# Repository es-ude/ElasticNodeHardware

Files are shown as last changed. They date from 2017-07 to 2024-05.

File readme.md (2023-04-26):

# Elastic Node Hardware Platform

## ENv5 - Elastic Node v5
The 5th generation of Elastic node is designed based on the 4th version, but with some improvements. The main improvements are:
- Using Cortex-M0 MCU instead of AVR 8-bit MCU, to gain more performance and lower power consumption.
- Using SPI as the communication interface between MCU and the FPGA to save more IO pins.
- Simplify the power supply circuit to reduce the space and improve reliability.
- Adding an energy meter chip to ease the energy measurement.
- Optimize the PCB layout to reduce the PCB size.

Before you start using the ENv5, please read the following documents accordingly:
- [ENv5 Test Version User Manual](v5/test_version/readme.md)
- [ENv5 Revision 1 User Manual](v5/revision_1/readme.md)

Troubleshooting
- When you notice the esp32 is not responding to the RP2040, you can apply the [pre-build firmware](v5/revision_1/prebuilds-firmware/test_esp_at.uf2) to test.
  - some descriptions about the behavior of the test are available [here](v5/revision_1/prebuilds-firmware/readme.md).

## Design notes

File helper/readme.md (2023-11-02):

Files that help me order PCBAs from JLCPCBs are stored in this folder.
1. the `ulp` file to generate BOM and CPL file.
2. the `cam_process` file to generate gerber files.

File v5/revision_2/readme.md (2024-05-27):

# ENv5 Revision 2 User Manual

## Notice:
- The old wifi-shield is not compatible with the ENv5-Rev1. Please use the new extension board instead.
  - When you plug out the extension board, please try to make to PCBs in parallel to avoid damage to the male headers.
- Before you plug in a battery to the ENv5, please check if the order of the battery is correct.
  - The Cable close to the dot sign should be positive.
  - A thermal resistor should be attached to the battery to prevent the battery from overheating. If the resistor is not soldered, don't use the battery.
- The pin mapping of Env5 is referred to the [schematic of env5-rev2](en_v5_rev2_schematic.pdf).
- The pin mapping of the extension board is referred to the [schematic of extension board](extension_board/extension_board_schematic.pdf).

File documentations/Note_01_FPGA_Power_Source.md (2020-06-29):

#Note_01_FPGA_Power_Source

| Supply | Circuits | FPGA pins |
| --- | --- | --- |
| 3.3V | FPGA I/O | VCCO_34 |
| 1.4V | FPGA I/O | VCCO_14 |
| 1.8V | FPGA Auxiliary | VCCAUX |
| 1.0V | FPGA Core and Block RAM | VCCINT and VCCBRAM |

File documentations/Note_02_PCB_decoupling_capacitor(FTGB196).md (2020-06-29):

#Note_02_PCB_decoupling_capacitor(FTGB196)

## 1.VCC_INT

| Device | 100uF | 4.7uF | 0.47uF |
| --- | ----- | ----- | --- |
| XC7S15 | 1 | 2 | 2 |
| XC7S25 | 1 | 2 | **3**  |
| XC7S50 | 1 | **3** | **5**  |

## 2.VCCBRAM

| Device | 100uF | 47uF | 4.7uF | 0.47uF |
| --- | ----- | ---- | ----- | --- |
| XC7S15 | 0 | 1 | 1 | 1 |
| XC7S25 | 0 | 1 | 1 | 1 |
| XC7S50 | **1** | 1 | 1 | 1 |

## 3.VCCAUX

| Device | 47uF | 4.7uF | 0.47uF |
| --- | ---- | ----- | --- |
| XC7S15 | 1 | 1 | 2 |
| XC7S25 | 1 | 1 | 2 |
| XC7S50 | 1 | 1 | **3**  |

##4.VCCO (**per Bank**)

| Device | 47uF or 100uF | 4.7uF | 0.47uF |
| --- | --- | ----- | --- |
| XC7S15 | 1 | 2 | 4 |
| XC7S25 | 1 | 2 | 4 |
| XC7S50 | 1 | 2 | 4 |

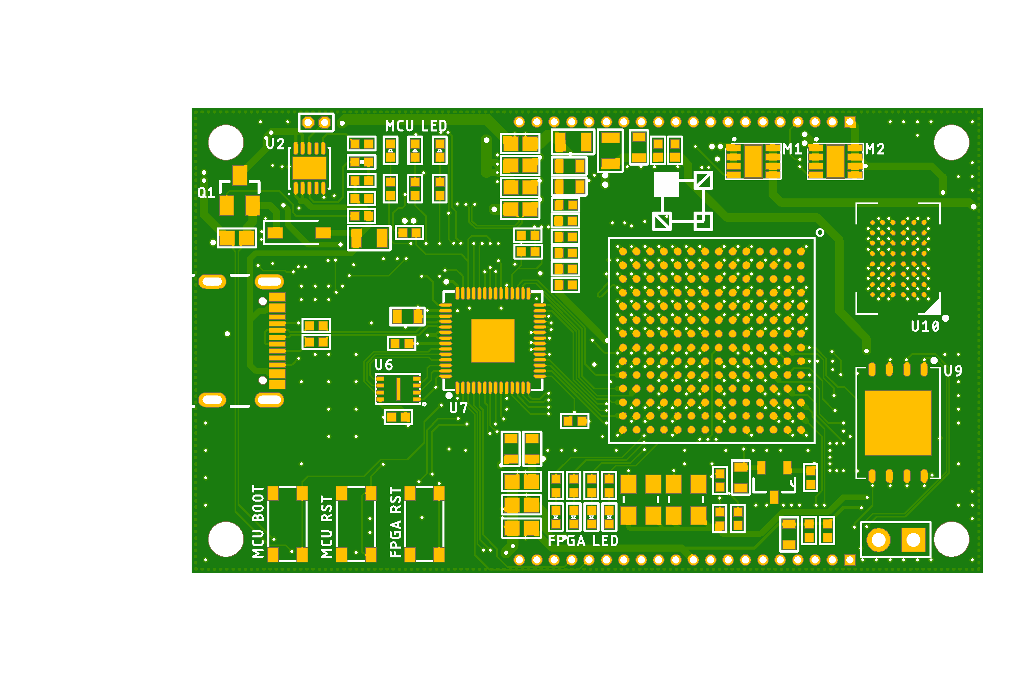
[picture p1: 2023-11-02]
v5/revision_2/main_board/en_v5_rev2_top.png

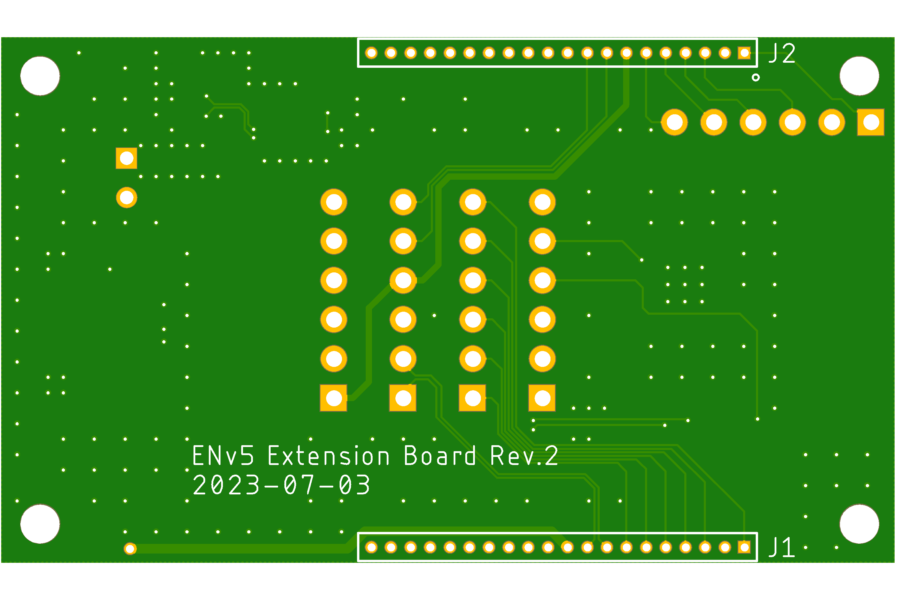
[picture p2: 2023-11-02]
v5/revision_2/extension_board/extension_board_bottom_rev2.png

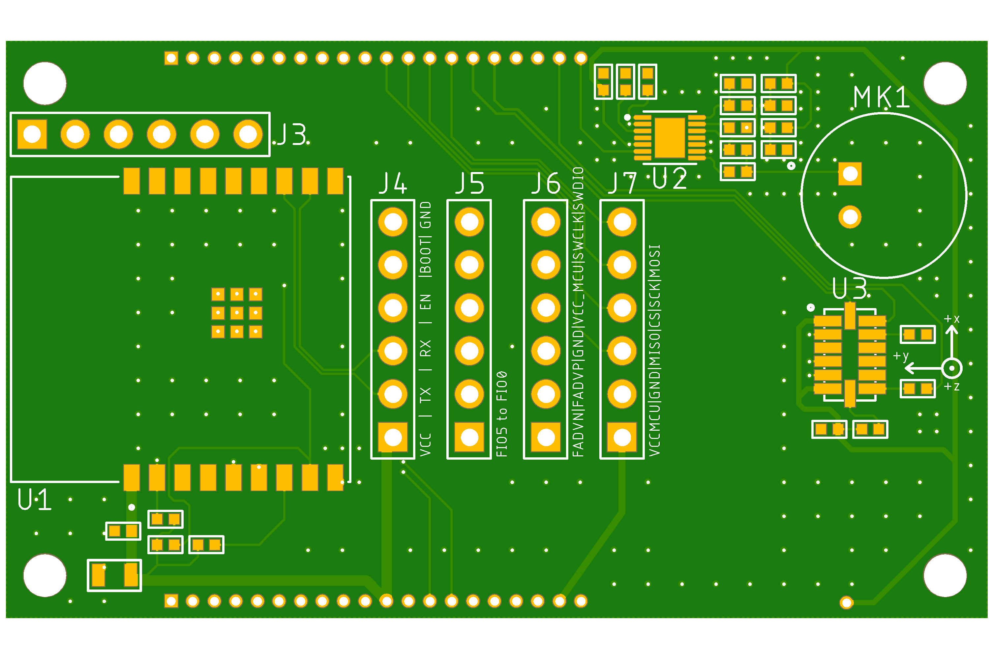
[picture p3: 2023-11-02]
v5/revision_2/extension_board/extension_board_top_rev2.png

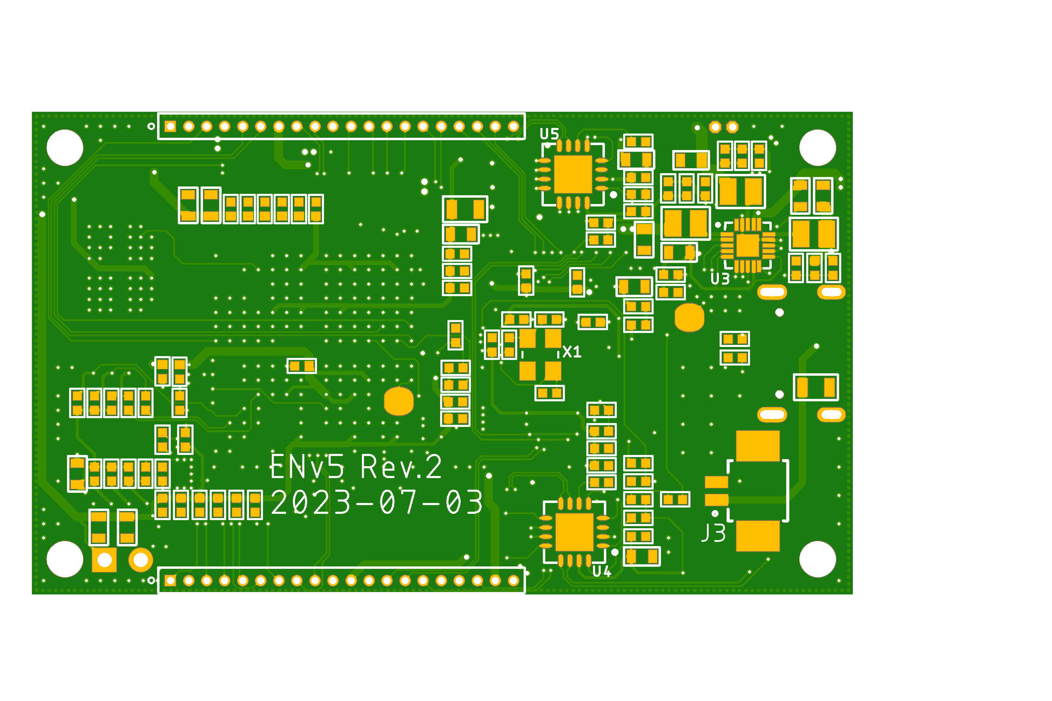
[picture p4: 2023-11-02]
v5/revision_2/main_board/en_v5_rev2_bottom.png

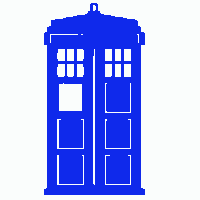
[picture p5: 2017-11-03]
logo/tardis.bmp

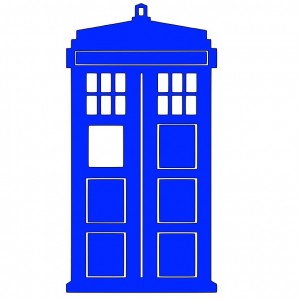
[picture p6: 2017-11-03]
logo/tardis.jpg

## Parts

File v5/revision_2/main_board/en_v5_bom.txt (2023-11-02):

Qty Value                   Device                     Package                   Parts                                                                     Description                                                                                                                           
14  0.1uF                   CAPACITOR0402              0402                      C3, C14, C16, C18, C19, C20, C21, C22, C23, C24, C26, C27, C30, C44                                                                                                                                             
2   0.1uF                   CAPACITOR0603              CAPC1608-0603             C5, C6                                                                                                                                                                                                          
1   0.1uF                   CAPACITOR0805              0805                      C1                                                                                                                                                                                                              
8   0.82R                   RESISTOR0603               0603                      R16, R17, R18, R19, R20, R21, R26, R28                                                                                                                                                                          
7   0R                      RESISTORSMD_0402           0402                      R4, R10, R27, R29, R47, R48, R49                                                                                                                                                                                
1   1.5uH(MLP2016H1R5MT0S1) INDUCTORDFE201612E-R33M=P2 INDC2016X120N             L1                                                                                                                                                                                                              
1   100MHz                  OSCILLATOR3.2X2.5          3.2X2.5_OSC               X3                                                                                                                                                                                                              
7   100R                    RESISTORSMD_0402           0402                      R33, R60, R61, R65, R66, R68, R70                                                                                                                                                                               
1   100uF                   CAPACITOR0805              0805                      C59                                                                                                                                                                                                             
7   10K                     RESISTORSMD_0402           0402                      R3, R22, R23, R24, R25, R34, R44                                                                                                                                                                                
5   10uF                    CAPACITOR0603              CAPC1608-0603             C4, C8, C10, C12, C42                                                                                                                                                                                           
1   10uF                    CAPACITOR0805              0805                      C2                                                                                                                                                                                                              
3   120K                    RESISTORSMD_0402           0402                      R9, R12, R13                                                                                                                                                                                                    
1   12MHz                   QUARTZ                     3.2X2.5_OSC               X1                                                                                                                                                                                                              
1   150K                    RESISTORSMD_0402           0402                      R11                                                                                                                                                                                                             
1   180K                    RESISTORSMD_0402           0402                      R14                                                                                                                                                                                                             
7   1K                      RESISTORSMD_0402           0402                      R6, R46, R51, R52, R54, R55, R62                                                                                                                                                                                
1   1R                      RESISTORSMD_0402           0402                      R41                                                                                                                                                                                                             
2   1uF                     CAPACITOR0402              0402                      C33, C43                                                                                                                                                                                                        
1   2.2uH(MLP2016H2R2MT0S1) INDUCTORDFE201612E-R33M=P2 INDC2016X120N             L3                                                                                                                                                                                                              
1   2.7pF                   CAPACITOR0402              0402                      C11                                                                                                                                                                                                             
1   200R                    RESISTORSMD_0402           0402                      R37                                                                                                                                                                                                             
2   20pF                    CAPACITOR0402              0402                      C31, C32                                                                                                                                                                                                        
2   27R                     RESISTORSMD_0402           0402                      R42, R43                                                                                                                                                                                                        
7   2K                      RESISTORSMD_0402           0402                      R5, R45, R50, R53, R56, R57, R58                                                                                                                                                                                
1   3.3pF                   CAPACITOR0402              0402                      C9                                                                                                                                                                                                              
1   3.3uH(MLP2016H3R3MT0S1) INDUCTORDFE201612E-R33M=P2 INDC2016X120N             L2                                                                                                                                                                                                              
1   30K                     RESISTORSMD_0402           0402                      R8                                                                                                                                                                                                              
1   32MHz                   OSCILLATOR3.2X2.5          3.2X2.5_OSC               X2                                                                                                                                                                                                              
3   4.7K                    RESISTORSMD_0402           0402                      R32, R35, R59                                                                                                                                                                                                   
15  4.7uF                   CAPACITOR0603              CAPC1608-0603             C13, C15, C17, C25, C28, C29, C34, C35, C45, C46, C54, C60, C61, C68, C70                                                                                                                                       
15  470nF                   CAPACITOR0402              0402                      C36, C37, C38, C39, C47, C48, C49, C50, C55, C56, C62, C63, C64, C71, C74                                                                                                                                       
12  47nF                    CAPACITOR0402              0402                      C40, C41, C51, C52, C57, C58, C65, C66, C67, C72, C73, C75                                                                                                                                                      
2   47uF                    CAPACITOR0805              0805                      C53, C69                                                                                                                                                                                                        
9   499R                    RESISTORSMD_0402           0402                      R30, R36, R38, R39, R40, R63, R64, R67, R69                                                                                                                                                                     
1   53261-0271              53261-0271                 MOLEX_53261-0271          J3                                                                        Conn Shrouded Header HDR 2 POS 1.25mm Solder RA SMD PicoBlade™ Embossed T/R Check availability                                        
1   57.6K                   RESISTORSMD_0402           0402                      R15                                                                                                                                                                                                             
2   5K                      RESISTORSMD_0402           0402                      R1, R2                                                                                                                                                                                                          
1   6.8pF                   CAPACITOR0402              0402                      C7                                                                                                                                                                                                              
1   806R                    RESISTORSMD_0402           0402                      R31                                                                                                                                                                                                             
1   CY7C1051DV33            CY7C1051DV33               BGA-48                    U10                                                                       SRAM 8Mb 10ns3.3V 512Kx16 Fast Async                                                                                                  
1   DIODEB5817W             SCHOTTKY_DIODEB5817W       SOD-123                   D1                                                                                                                                                                                                              
1   FDN302P                 FDN302P                    SSOT-3                    Q1                                                                        P-Channel MOSFET                                                                                                                      
1   FEMALE_HEADER_2X1       FEMALE_HEADER_2X1          2X1_HEADER                J5                                                                                                                                                                                                              
1   LTC3569EUDPBF           LTC3569EUDPBF              QFN40P300X300X80-21N      U3                                                                        Triple Buck Regulator with 1.2A and Two 600mA Outputs and  Individual Programmable References Check availability                      
2   M50-3032042             M50-3032042                20X1_HEADER_THT_1.27MM    J1, J2                                                                    M50-3032042                                                                                      
1   MCP73833T-AMI/MF        MCP73833T-AMI/MF           DFN-10(3X3X0.9)           U2                                                                        Linear Charge Management Controller Li-Ion/Li-Pol 1mA 4.2V/4.35V/4.4V/4.5V 10-Pin DFN EP T/R Check prices                             
1   NTCLE413E2103H400       RESISTORTHT_THERMAL        THT_2                     R7                                                                                                                                                                                                              
2   PAC1934                 PAC1934                    UQFN-16(4×4×0.5MM)        U4, U5                                                                    Current & Power Monitors & Regulators Quad High-Side Current Sensor, I2C/SMBus, 32V with Accumulator                                  
1   REF3012AIDBZR           REF3012AIDBZR              SOT-23(3PIN)              U1                                                                        CMOS VOLTAGE REFERENCE Check prices                                                                                                   
1   RP2040                  RP2040                     QFN40P700X700X100-57T310N U7                                                                                                                                                                                                              
1   S25FL256S               S25FL256S                  WSON6X8MM                 U9                                                                        FLASH - NOR Memory IC 256Mb (32M x 8) SPI - Quad I/O WSON-8 (6x8)                                                                     
2   SISS23DN                SISS23DN                   POWERPAK1212-8            M1, M2                                                                                                                                                                                                          
1   SPARTAN7-LX15           SPARTAN7-LX15              FTGB196                   U8                                                                                                                                                                                                              
3   TACTILE-SWITCH          TACTILE-SWITCH             TACTILE-SWITCH            S1, S2, S3                                                                612-TL3365AF180QG                                                                                                                     
2   TEST_POINTSMD           TEST_POINTSMD              SMD_PAD                   TP1, TP2                                                                                                                                                                                                        
1   USB4105-GF-A            USB4105-GF-A               GCT_USB4105-GF-A          J4                                                                        USB-C (USB TYPE-C) USB 2.0 Receptacle Connector 24 (16+8 Dummy) Position Surface Mount, Right Angle; Through Hole  Check availability 
1   W25Q16JVUXIQ            W25Q16JVUXIQ               USON8-2X3MM               U6                                                                        W25Q16JV - NOR Flash                                                                                                                  
1   green                   LED0402                    0402                      D2                                                                                                                                                                                                              
7   red                     LED0402                    0402                      D3, D4, D5, D6, D7, D8, D9

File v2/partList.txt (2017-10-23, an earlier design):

	Partlist

Exported from elasticNode.brd at 07.08.17 2:13 PM

EAGLE Version 8.2.2 Copyright (c) 1988-2017 Autodesk, Inc.

Assembly variant: 

Part     Value               Package         Library    Position (mm)         Orientation

C1       4.7uF               0805            passive    (9.5 28.25)           R270
C2       4.7uF               0805            passive    (17.36 11.25)         R0
C3       4.7uF               0805            passive    (19.5 42.25)          R0
C4       4.7uF               0805            passive    (23.25 11)            R180
C5       4.7uF               0805            passive    (7.25 28.25)          R270
C6       4.7uF               0805            passive    (17.36 13.46)         R0
C7       .47uF               0402            passive    (19.5 44.5)           R0
C8       .47uF               0402            passive    (21.25 11.5)          R90
C9       4.7uF               0805            passive    (5 28.25)             R270
C10      4.7uF               0805            passive    (27.75 48)            R0
C11      .47uF               0402            passive    (19.5 46.75)          R0
C12      .47uF               0402            passive    (20.5 8.75)           R180
C13      0.47uF              0402            passive    (2.75 28.25)          R270
C14      4.7uF               0805            passive    (27.75 45.75)         R0
C15      4.7uF               0805            passive    (43.25 27.5)          R90
C16      4.7uF               0805            passive    (7.25 25)             R270
C17      4.7uF               0805            passive    (27.75 43.5)          R0
C18      .47uF               0402            passive    (41 27.5)             R90
C19      .47uF               0402            passive    (5 25)                R270
C20      4.7uF               0805            passive    (27.75 41.25)         R0
C21      .47uF               0402            passive    (38.75 27.5)          R90
C22      .47uF               0402            passive    (2.75 25)             R270
C23      4.7uF               0805            passive    (43.25 24.75)         R270
C24      .47uF               0805            passive    (41 24.75)            R270
C25      10n                 0805            passive    (78.75 21)            R180
C26      100n                0805            passive    (78.75 25.5)          R180
C27      4.7u                0805            passive    (78.75 27.75)         R180
C28      100n                0805            passive    (74.35 15.05)         R90
C29      22u                 0805            passive    (63.5 35.5)           R0
C30      10u                 0805            passive    (67.8 26.3)           R180
C31      22u                 0805            passive    (70.25 35.5)          R180
J1       ISP_CONN_6PIN       3X2_HEADER_SMT  connectors (57.5 17)             R90
J2       FEMALE_HEADER_2X2   2X2_HEADER      connectors (64.25 48.5)          R180
J3       FEMALE_HEADER_2X1   2X1_HEADER      connectors (16.25 49.75)         R180
J4       FEMALE_HEADER_2X1   2X1_HEADER      connectors (23 49.75)            R180
J5       FEMALE_HEADER_5X2   5X2_HEADER      connectors (4.5 36.75)           R270
J6       FEMALE_HEADER_5X2   5X2_HEADER      connectors (4.5 16.9)            R90
J7       JTAG_CONN_6PINTHT   6X1_HEADER      connectors (38.5 44.25)          R270
J8       USB_CONNSMT         USB_MICRO_B_SMT connectors (77 13.5)             R90
L1       40Ohm 1.5A          0805            passive    (78.75 23.25)         R180
L2       3.3uH               0805            passive    (62.25 29.75)         R270
L3       3.3uH               0805            passive    (71.25 29.75)         R90
LED0     GREEN 2.2V          0805            opto       (68 45.25)            R90
LED1     GREEN 2.2V          0805            opto       (70.25 45.25)         R90
LED2     GREEN 2.2V          0805            opto       (72.5 45.25)          R90
LED3     GREEN 2.2V          0805            opto       (74.75 45.25)         R90
LED4     RED 1.8V 2mA        0805            opto       (10 45)               R90
LED5     RED                 0805            opto       (12.25 45)            R90
LED6     RED                 0805            opto       (14.5 45)             R90
LED7     RED                 0805            opto       (16.75 45)            R90
PWR      RED                 0805            opto       (70.25 4.5)           R90
R1       2.4k                0805            passive    (54.6 35)             R135
R2       2.4k                0805            passive    (53.5 19.75)          MR315
R3       550                 0805            passive    (68 42.25)            R90
R4       550                 0805            passive    (70.25 42.25)         R90
R5       550                 0805            passive    (72.5 42.25)          R90
R6       550                 0805            passive    (74.75 42.25)         R90
R7       15k                 0805            passive    (52 18.75)            R90
R8       750                 0805            passive    (10 42.25)            R90
R9       750                 0805            passive    (12.25 42.25)         R90
R10      750                 0805            passive    (14.5 42.25)          R90
R11      750                 0805            passive    (16.75 42.25)         R90
R12      2.4k                0805            passive    (34.25 16.5)          R270
R13      2.4k                0805            passive    (36.5 16.5)           R270
R14      2.4k                0805            passive    (17.5 8.75)           R270
R15      15k                 0805            passive    (15.25 9.5)           R0
R16      0.8                 0805            passive    (73.75 36.5)          R270
R17      .8                  0805            passive    (30.5 48.75)          R0
R18      0.16                0805            passive    (78.75 30)            R180
R19      .8                  0805            passive    (30.5 51)             R0
R20      100                 0805            passive    (73.5 33.5)           R270
R21      300                 0805            passive    (30.75 42.25)         R0
R22      .8                  0805            passive    (47.5 18.75)          R270
R23      2000                0805            passive    (44.5 22)             R180
R24      1.5k                0805            passive    (48.5 10.5)           MR180
R25      1.5k                0805            passive    (54 14)               MR180
R26      1.5k                0805            passive    (65.75 8)             R270
R27      1.5k                0805            passive    (68 8)                R270
R28      6k8                 0805            passive    (63.25 33.1)          R0
R29      1k5                 0805            passive    (65.5 31.6)           R0
R30      1k5                 0805            passive    (67.5 33.1)           R0
R31      1k5                 0805            passive    (70.25 33.1)          R0
R32      270                 0805            passive    (70.25 8)             R270
RX       ORANGE              0805            opto       (68 4.5)              R90
S1       SPST_BUTTON2PIN_SMT SPST_2PIN_SMT   connectors (57.5 9.25)           R180
S2       SPST_BUTTON2PIN_SMT SPST_2PIN_SMT   connectors (21.75 4.5)           R180
S3       SPST_DIP_2SMT       SPST_DIP2_SMT   connectors (37.5 9.75)           R0
TX       ORANGE 2V           0805            opto       (65.75 4.5)           R90
U1       ATMEGA64AQFN        QFN64           ic         (47.06 26.59)         MR0
U2       SST26VF032B         SOIC8           ic         (57.78 22.15)         MR90
U3       MRF24J40MA          MRF24J40MA      wireless   (50.75 44.5)          R0
U4       SPARTAN6-LX9        TQG144          fpga       (23.56 28.48)         R0
U5       SST26VF032B         SOIC8           ic         (29.63 11.41)         R180
U6       PAC1720             VDFN10          sensors    (77 33.5)             R270
U7       PAC1720             VDFN10          sensors    (32.5 45.5)           R270
U8       PAC1720             VDFN10          sensors    (40.75 18)            R180
U9       FT232RSSOP28        SSOP28          ic         (68 16.75)            R270
U10      LTC3419DFN          DFN8            power      (66.5 29.25)          R270
X1       12MHz               3.2X2.5_OSC     passive    (49.25 14)            MR0
X2       50MHz               3.2X2.5_OSC     passive    (22.75 15)            R180
X3       32MHz               3.2X2.5_OSC     passive    (40.25 32.75)         R270

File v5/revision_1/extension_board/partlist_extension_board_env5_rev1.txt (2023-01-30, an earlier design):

Partlist exported from /home/chao/EAGLE/projects/lattice_v5/extension_board/extension_board.sch at 16/01/2023 20:29

Qty Value                  Device                 Package                     Parts               Description                                                                                                AVAILABILITY CUI_PURCHASE_URL                                                                                                                                                    DESCRIPTION                                                                MANUFACTURER MAXIMUM_PACKAGE_HEIGHT MF                  MP             PACKAGE               PARTREV PRICE PURCHASE-URL                                                    STANDARD                    
3   0.1uF                  CAPACITOR0402          0402                        C3, C5, C6                                                                                                                                                                                                                                                                                                                                                                                                                                                                                                                                                                                        
1   0.1uF                  CAPACITOR0805          0805                        C1                                                                                                                                                                                                                                                                                                                                                                                                                                                                                                                                                                                                
1   0R                     RESISTORSMD_0402       0402                        R13                                                                                                                                                                                                                                                                                                                                                                                                                                                                                                                                                                                               
5   100K                   RESISTORSMD_0402       0402                        R4, R5, R6, R7, R10                                                                                                                                                                                                                                                                                                                                                                                                                                                                                                                                                                               
3   10K                    RESISTORSMD_0402       0402                        R1, R2, R3                                                                                                                                                                                                                                                                                                                                                                                                                                                                                                                                                                                        
1   10uF                   CAPACITOR0805          0805                        C2                                                                                                                                                                                                                                                                                                                                                                                                                                                                                                                                                                                                
1   150K                   RESISTORSMD_0402       0402                        R9                                                                                                                                                                                                                                                                                                                                                                                                                                                                                                                                                                                                
2   1uF                    CAPACITOR0402          0402                        C4, C8                                                                                                                                                                                                                                                                                                                                                                                                                                                                                                                                                                                            
1   2.2K                   RESISTORSMD_0402       0402                        R8                                                                                                                                                                                                                                                                                                                                                                                                                                                                                                                                                                                                
1   2.2uF                  CAPACITOR0402          0402                        C7                                                                                                                                                                                                                                                                                                                                                                                                                                                                                                                                                                                                
2   2K                     RESISTORSMD_0402       0402                        R11, R12                                                                                                                                                                                                                                                                                                                                                                                                                                                                                                                                                                                          
1   ADXL345BCCZ-RL         ADXL345BCCZ-RL         PQFN80P300X500X79-14N       U3                  3-Axis, ±2 g/±4 g/±8 g/±16 g Digital Accelerometer Check prices                                            In Stock                                                                                                                                                                          Accelerometer X, Y, Z Axis ±2g, 4g, 8g, 16g 0.05Hz ~ 1.6kHz 14-LGA (3x5)                                      Analog Devices Inc. ADXL345BCCZ-RL LGA-14 Analog Devices         None  https://pricing.snapeda.com/search/part/ADXL345BCCZ-RL/?ref=eda                             
1   CMA-4544PF-W           CMA-4544PF-W           MIC_CMA-4544PF-W            MK1                 CMA Series 9.7 mm Electret Condenser Omni-Directional Pin Mount 3 V Microphone Check prices                In Stock     https://www.cuidevices.com/product/audio/microphones/electret-condenser-microphones/cma-4544pf-w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 9.7 mm, Omnidirectional, PCB Mount, 3.0 Vdc, Electret Condenser Microphone                                     CUI Devices         CMA-4544PF-W   6-DIP-6 CUI                   None  https://pricing.snapeda.com/search/part/CMA-4544PF-W/?ref=eda                               
1   ESP32-C3-WROOM-02-H4   ESP32-C3-WROOM-02-H4   MODULE_ESP32-C3-WROOM-02-H4 U1                  WiFi Modules (802.11) (Engineering Samples) SMD module, ESP32-C3, 4MB SPI flash, PCB antenna, -40 C +105 C                                                                                                                                                                                                                                                             Espressif    3.35 mm                                                                         V1.0                                                                          Manufacturer Recommendations
2   M50-3142045THT         M50-3142045THT         20X1_HEADER_THT_1.27MM      J1, J2              Headers & Wire Housings 20 WAY SIL VERT SMT SKT                                                                                                                                                                                                                                                                                                                                                                                                                                                                                                                               
5   MALE_HEADER_6X1_2.54MM MALE_HEADER_6X1_2.54MM HDR_6X1_2.54MM              J3, J4, J5, J6, J7                                                                                                                                                                                                                                                                                                                                                                                                                                                                                                                                                                                
1   MAX9814ETD+T           MAX9814ETD+T           SON40P300X300X80-15N        U2                  Audio Amp Microphone 1-CH Mono Class-AB 14-Pin TDFN EP T/R Check prices                                    In Stock                                                                                                                                                                          Amplifier IC 1-Channel (Mono) Class AB 14-TDFN-EP (3x3)                                                       Maxim Integrated    MAX9814ETD+    TDFN-14 Maxim                 None

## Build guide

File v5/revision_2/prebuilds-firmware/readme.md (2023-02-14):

This folder hosts prebuild firmware for hardware test or example purposes. 
The current prebuild are:
- `factory_MINI-1.bin` for the EPS32-C3 module on the extension board with enabled logs.
- `factory_MINI-1-Silence-Mode.bin` is the same as above but enables silence mode.

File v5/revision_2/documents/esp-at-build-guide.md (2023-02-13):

# ESP AT Firmware Build and debug guide
> you can find my prebuild firmware [here](https://github.com/es-ude/ElasticNodeHardware/tree/master/v5/revision_1/prebuilds-firmware).
## Commands example
```
git clone git@github.com:espressif/esp-at.git
cd esp-at
git checkout release/v3.0.0.0
# install your building system
./build.py install
# build the firmware, choose 2 -> 1 -> 0
./build.py build
# to flash the firmware
./build.py flash -p /dev/ttyUSB0
# alternative command to flash the firmware
./build.py flash -p /dev/ttyUSB0 build/factory/factory_MINI-1.bin

# to monitor debug output
./build.py monitor -p /dev/ttyUSB0
```
You will see output like this:

```
--- idf_monitor on /dev/ttyUSB0 115200 ---
--- Quit: Ctrl+] | Menu: Ctrl+T | Help: Ctrl+T followed by Ctrl+H ---
ESP-ROM:esp32c3-api1-20210207
Build:Feb  7 2021
rst:0x1 (POWERON),boot:0xc (SPI_FAST_FLASH_BOOT)
SPIWP:0xee
mode:DIO, clock div:2
load:0x3fcd6100,len:0x18cc
load:0x403ce000,len:0x8dc
load:0x403d0000,len:0x2d90
entry 0x403ce000
I (31) boot: ESP-IDF v4.3.2-553-g588436db47 2nd stage bootloader
I (31) boot: compile time 22:25:17
I (32) boot: chip revision: 3
I (35) boot.esp32c3: SPI Speed      : 40MHz
I (39) boot.esp32c3: SPI Mode       : DIO
I (44) boot.esp32c3: SPI Flash Size : 4MB
I (49) boot: Enabling RNG early entropy source...
I (54) boot: Partition Table:
I (58) boot: ## Label            Usage          Type ST Offset   Length
I (65) boot:  0 otadata          OTA data         01 00 0000d000 00002000
I (72) boot:  1 phy_init         RF data          01 01 0000f000 00001000
I (80) boot:  2 nvs              WiFi data        01 02 00010000 0000e000
I (87) boot:  3 at_customize     unknown          40 00 0001e000 00042000
I (95) boot:  4 ota_0            OTA app          00 10 00060000 001d0000
I (102) boot:  5 ota_1            OTA app          00 11 00230000 001d0000
I (110) boot: End of partition table
I (114) esp_image: segment 0: paddr=00060020 vaddr=3c140020 size=2a990h (174480) map
I (161) esp_image: segment 1: paddr=0008a9b8 vaddr=3fc91200 size=03c04h ( 15364) load
I (165) esp_image: segment 2: paddr=0008e5c4 vaddr=40380000 size=01a54h (  6740) load
I (168) esp_image: segment 3: paddr=00090020 vaddr=42000020 size=134c40h (1264704) map
I (452) esp_image: segment 4: paddr=001c4c68 vaddr=40381a54 size=0f6d0h ( 63184) load
I (467) esp_image: segment 5: paddr=001d4340 vaddr=50000000 size=00014h (    20) load
I (468) esp_image: segment 6: paddr=001d435c vaddr=50000018 size=00010h (    16) load
I (479) boot: Loaded app from partition at offset 0x60000
I (479) boot: Disabling RNG early entropy source...
AT cmd port:uart1 tx:7 rx:6 cts:5 rts:4 baudrate:115200
module_name:MINI-1
max tx power=78,ret=0
2.5.0

```

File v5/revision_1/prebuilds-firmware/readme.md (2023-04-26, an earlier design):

This folder hosts prebuild firmware for hardware test or example purposes. 
The current prebuild are:
- `factory_MINI-1.bin` for the EPS32-C3 module on the extension board with enabled logs.
- `factory_MINI-1-Silence-Mode.bin` is the same as above but enables silence mode.
- `test_esp_at.uf2` is the file for quick check if the esp32 is well connected to ENv5.
  - after you flash it to the RP2040, connect it via `screen` or `putty`, and send the 't' to the board, and it starts the test.
  - It automatically connects to `ES-Stud`, and start ping an IP address, as long as you see it comes to the ping test stage, which means the connection between boards is fine.

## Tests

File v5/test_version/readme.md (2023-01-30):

# ENv5 Test Version User Manual

## Known Issues of the Test Version
> Since this is the primary version of the ENv5, there are some known issues that need to be fixed in the next revision. Please read the following list carefully to save your time for debugging.
- The silk print for buttons `BOOT` and `MCU_RST` is reversed.
- The Flash chip is powered with the same rail as FPGA IOs, which means when you turn off the FPGA the Flash chip will be turned off as well.
  - You cannot write bitfile to the flash chip when the FPGA is turned off.
  - When the bitfile on flash chip is corrupted, once the FPGA is powered on, the FPGA will keeps reading data from the Flash chip. This leads to the MCU cannot visit the Flash anymore.
- Resistor value of the FPGAs mode selection pins are with wrong value, correct value is 1K.

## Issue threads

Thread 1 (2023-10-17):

ENv5 Revision 1 new boards with new MCU does not work with USB 3.0

telefonjoker100, 2023-10-17:
The new boards do not work with USB-C to USB-C Cable. We assume it are the new MCUs that do not force the pc to downgrade to USB2.0

SuperChange001, 2023-11-02:
Closed because we located the error is caused by the wrong resistor soldered by the manufacturer.

Closed 2023-11-02.

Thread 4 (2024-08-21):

LTC3569 - Datasheet states that power rail voltage drops when switching the enable pin of the LTC3569 respective power rail

LeoBuron, 2024-08-21:
The Output is computed with

VOUT1 = VREF1(1 + R1/R2) with R1=30k and R2=120k => VOUT1 = 1.0V
VOUT2 = VREF2(1 + R3/R4) with R3=150k and R4=120k => VOUT2 = 1.8V

VREF starts at 0.8V and will decrease everytime it the respective enable pin is switched by 25mV down to 0.425V.
This means that everytime we switch the FPGA power on and off, the VREF1 and VREF2 will go down by 25mV. Which will result in drops of 31.25mV for VOUT1 and 56.25mV for VOUT2. We should definitly check if the behaviour is like that. This would mean that we can not really turn off and on the FPGA multiple times.

LeoBuron, 2024-09-19:
Sure. But if we enable and disbale the ltc3569 fast, we generate a square wave. So the problem might still occur.

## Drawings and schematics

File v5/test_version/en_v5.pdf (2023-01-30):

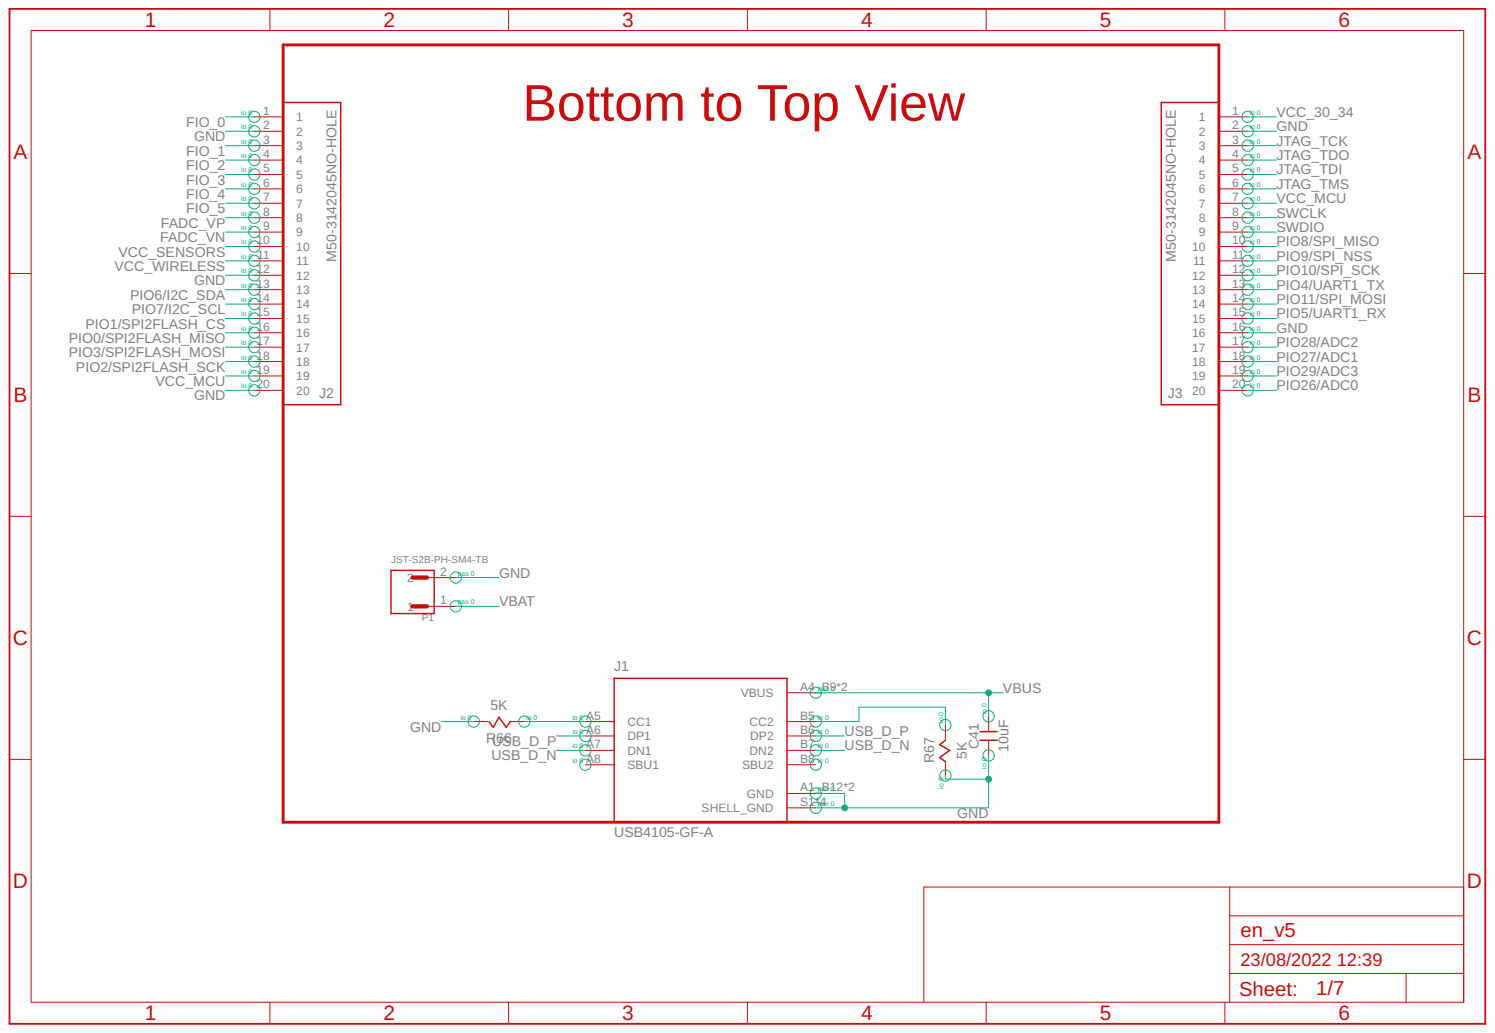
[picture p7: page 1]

Bottom to Top View

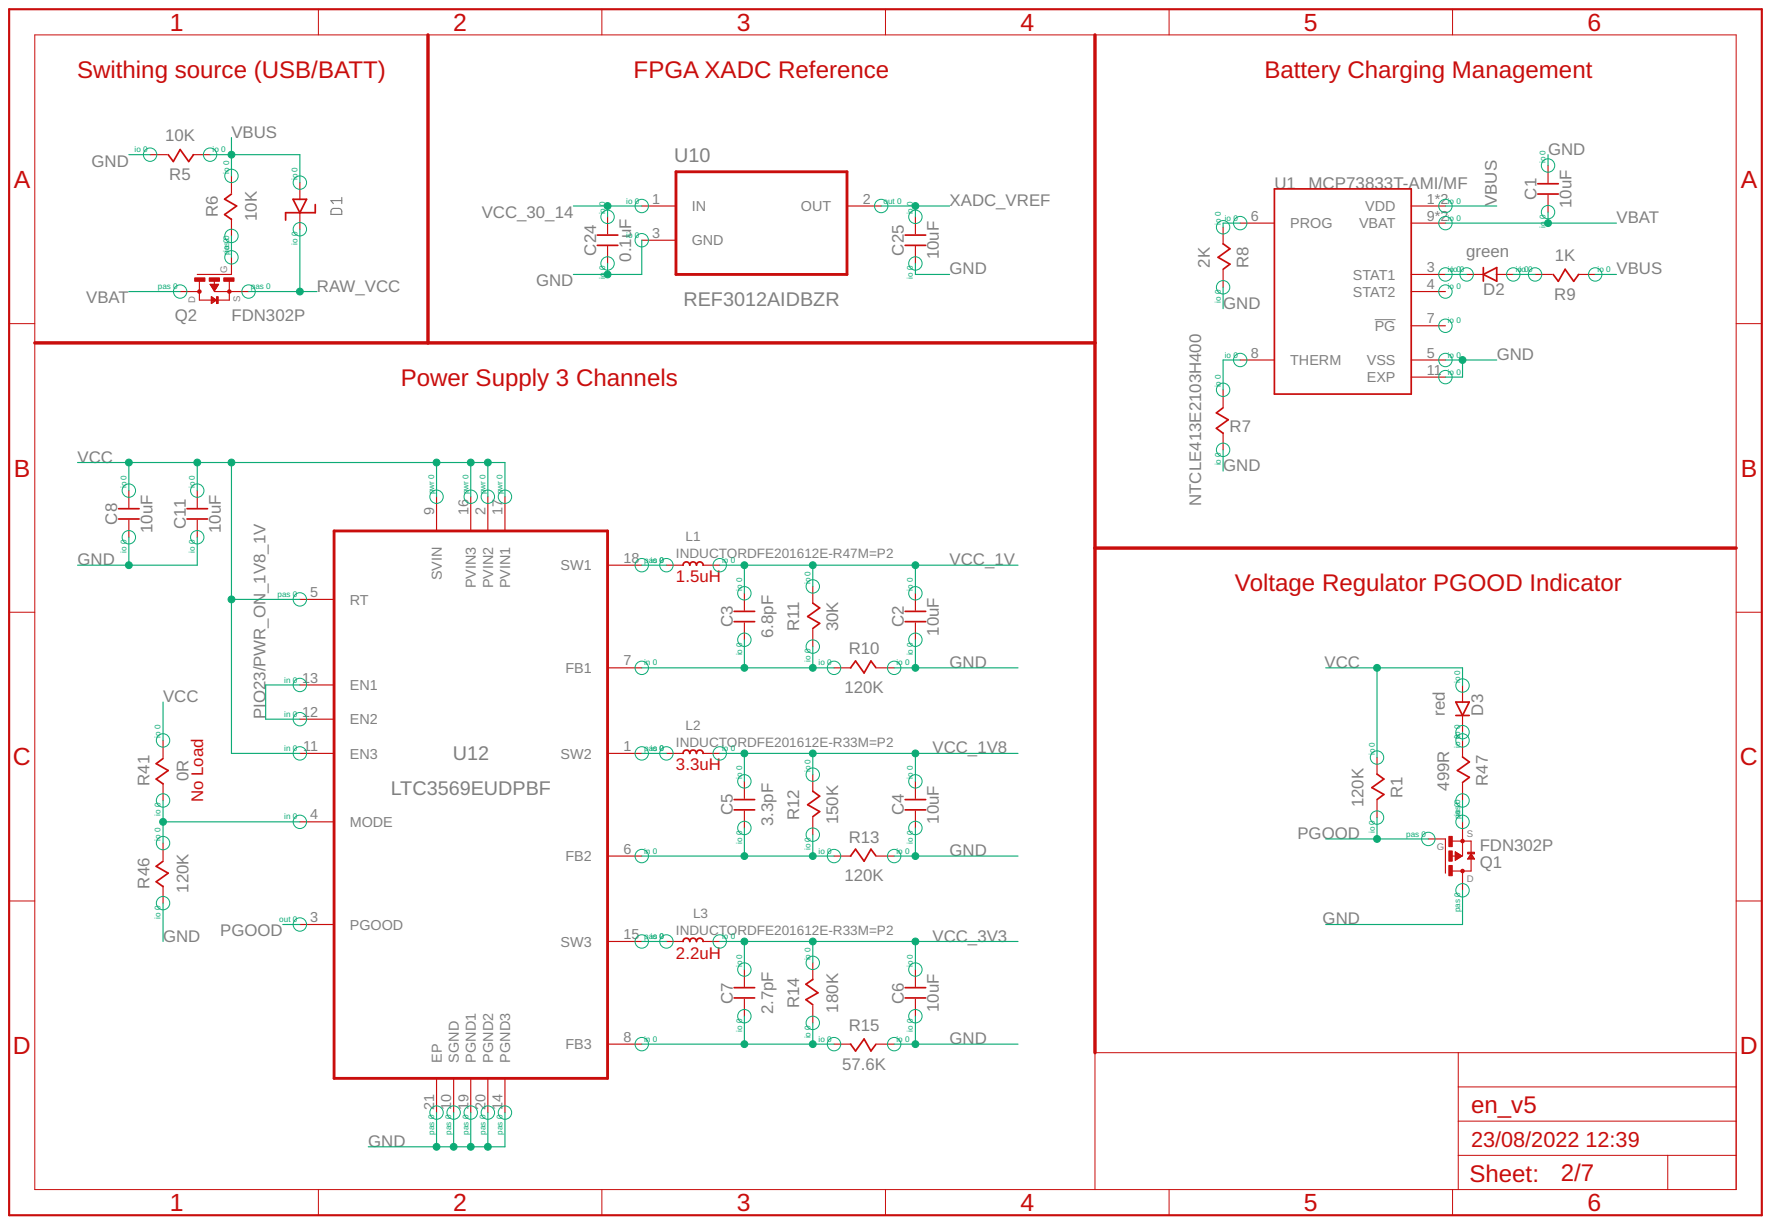
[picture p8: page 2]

Swithing source (USB/BATT) VBUS VBAT | FPGA XADC Reference GND | Battery Charging Management

No Load Power Supply 3 Channels

Voltage Regulator PGOOD Indicator

L2 1 pas 0 io 0 io 0

L3 15 pas 0 io 0 io 0

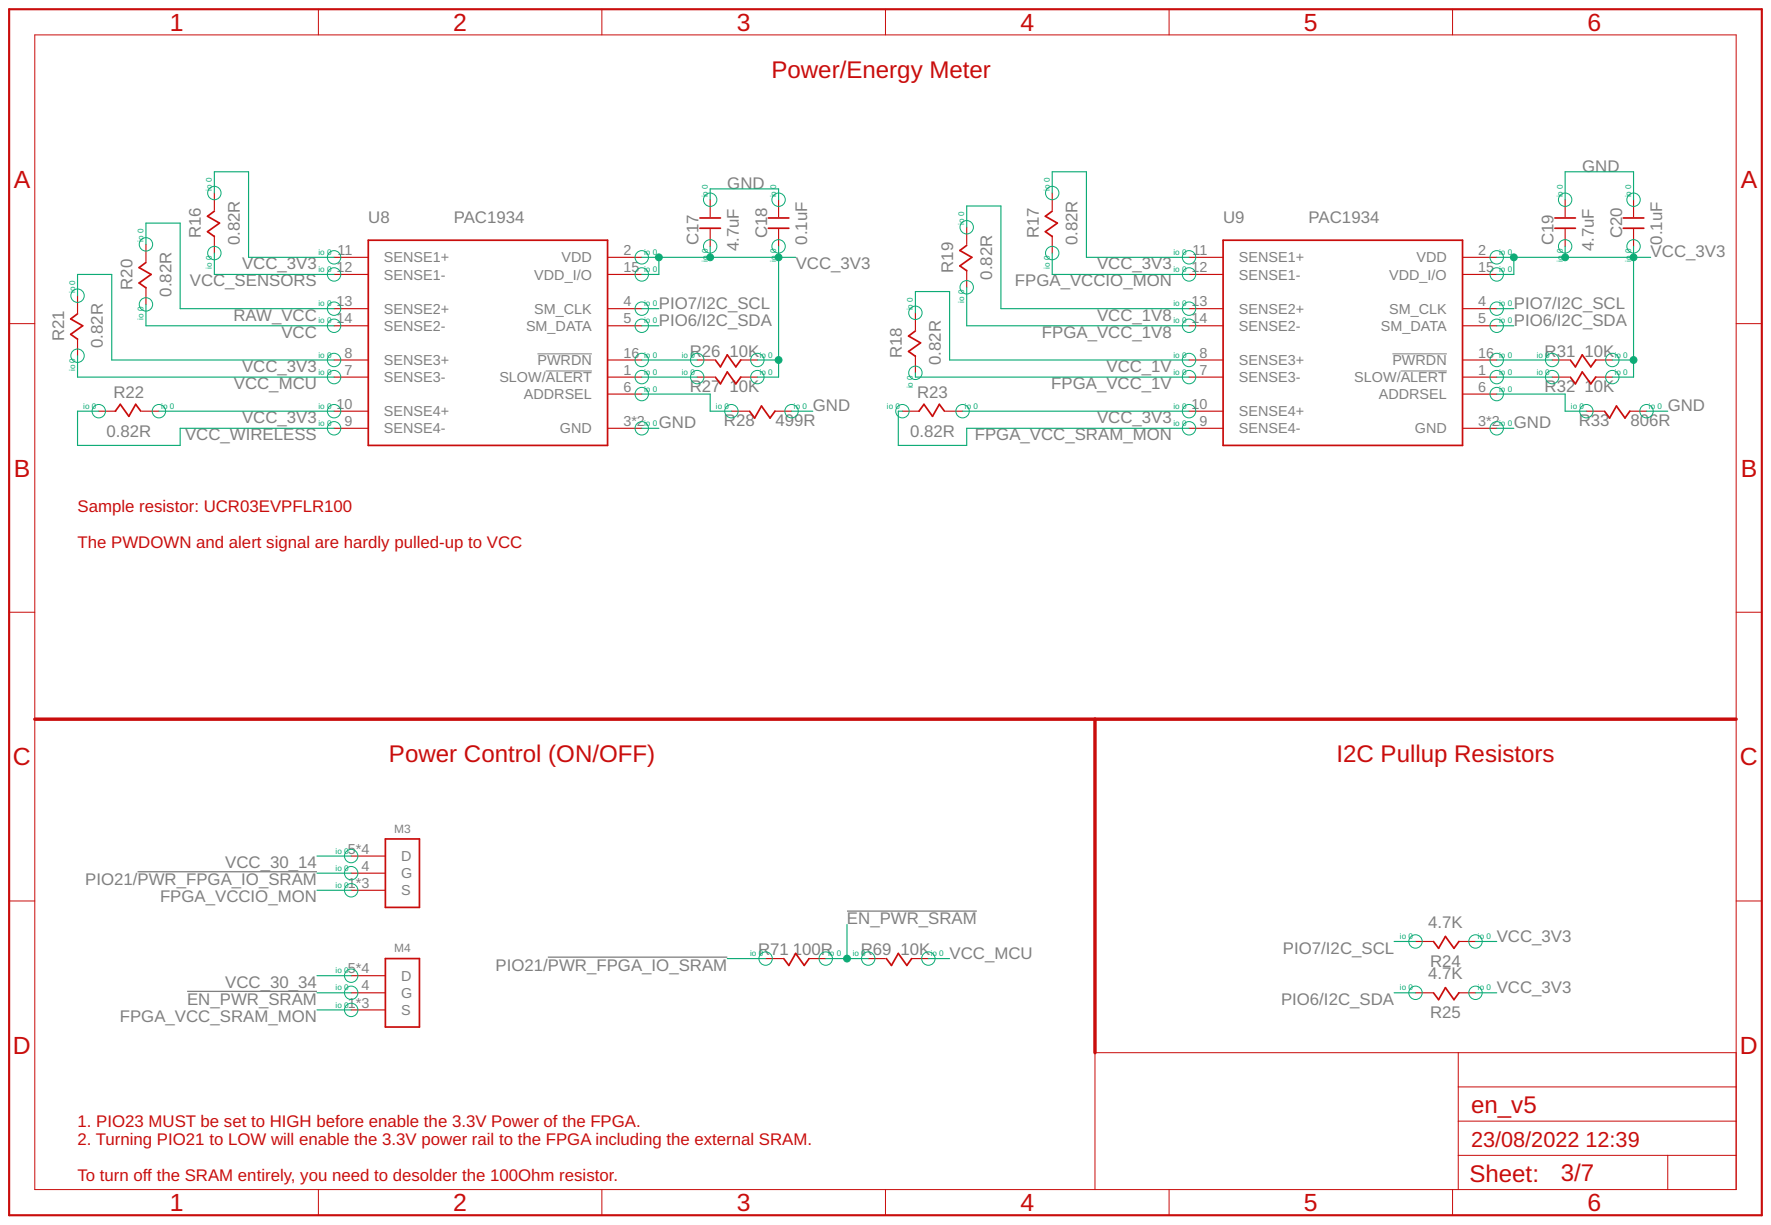
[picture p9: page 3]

Sample resistor: UCR03EVPFLR100
The PWDOWN and alert signal are hardly pulled-up to VCC

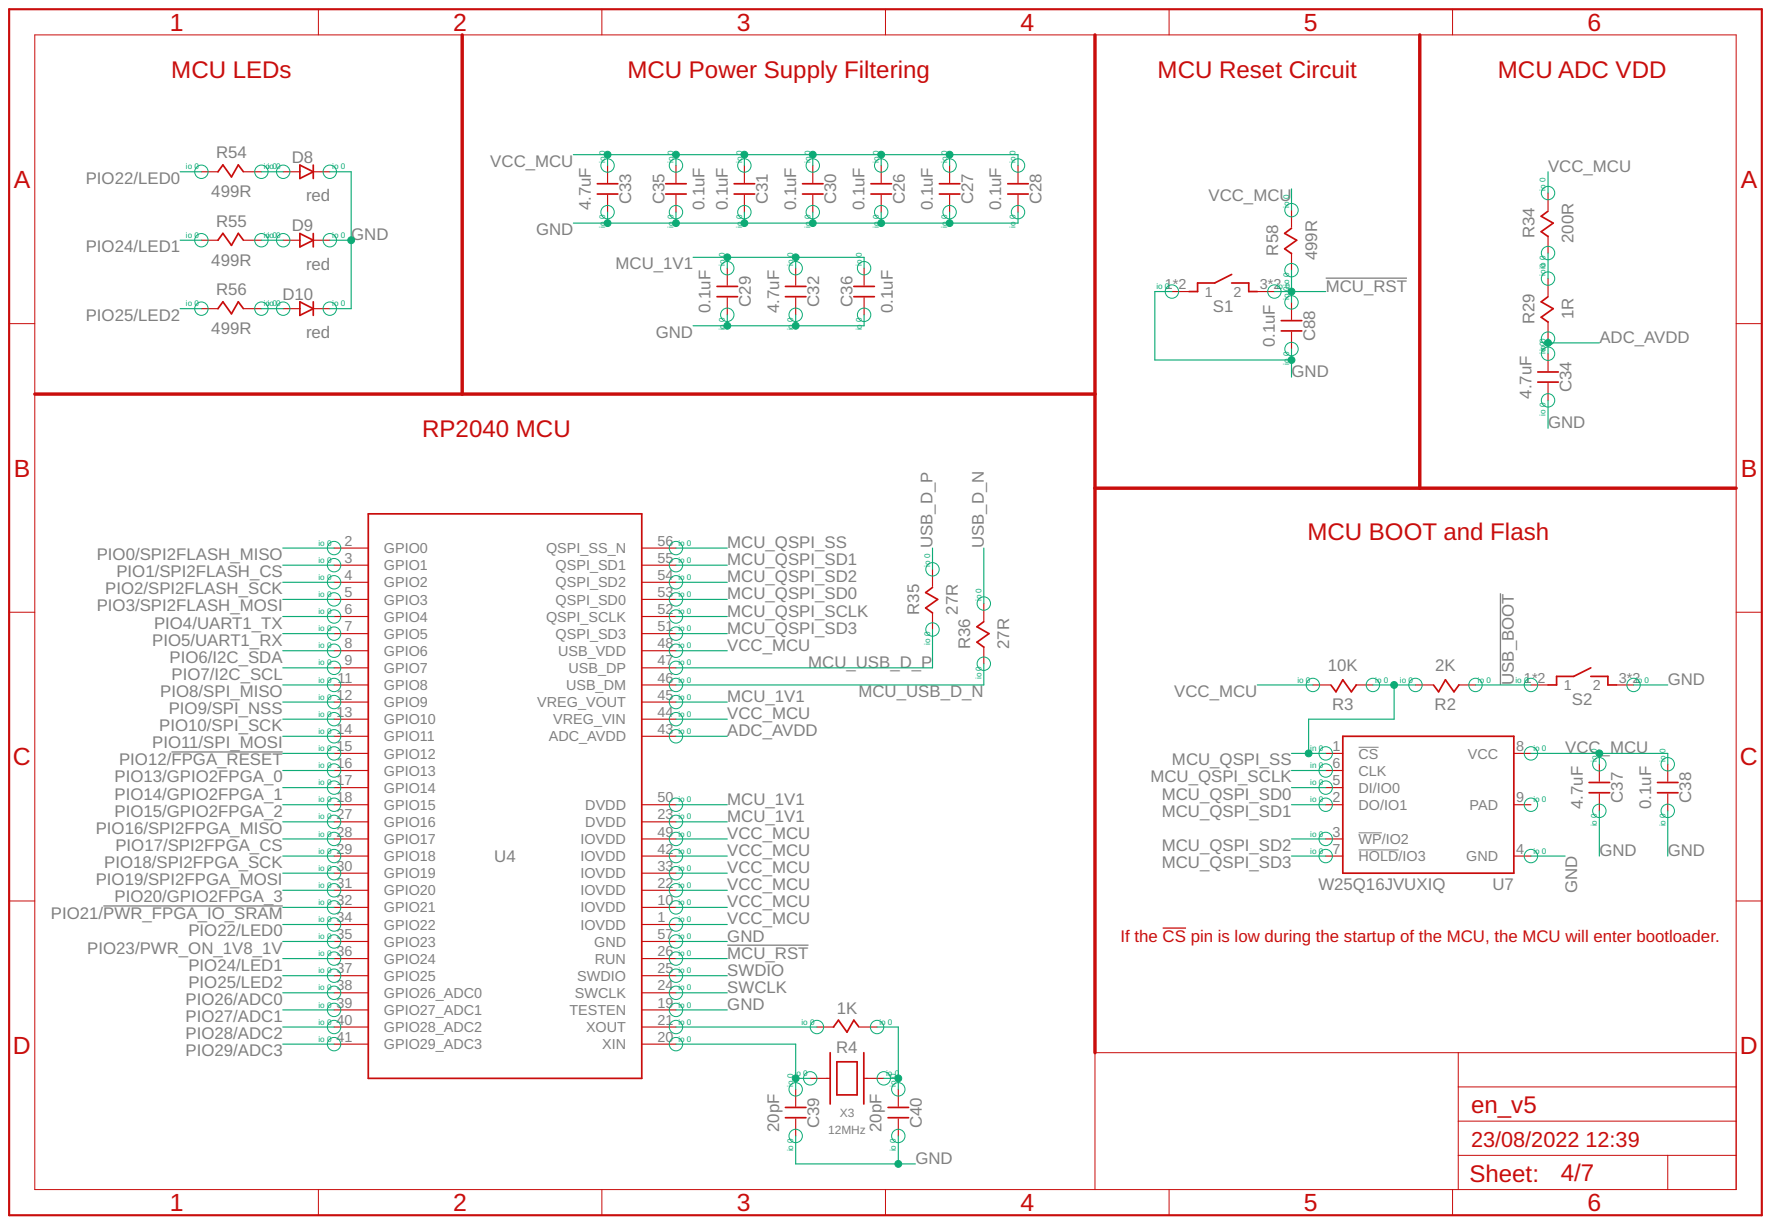
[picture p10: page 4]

MCU BOOT and Flash

If the CS pin is low during the startup of the MCU, the MCU will enter bootloader.

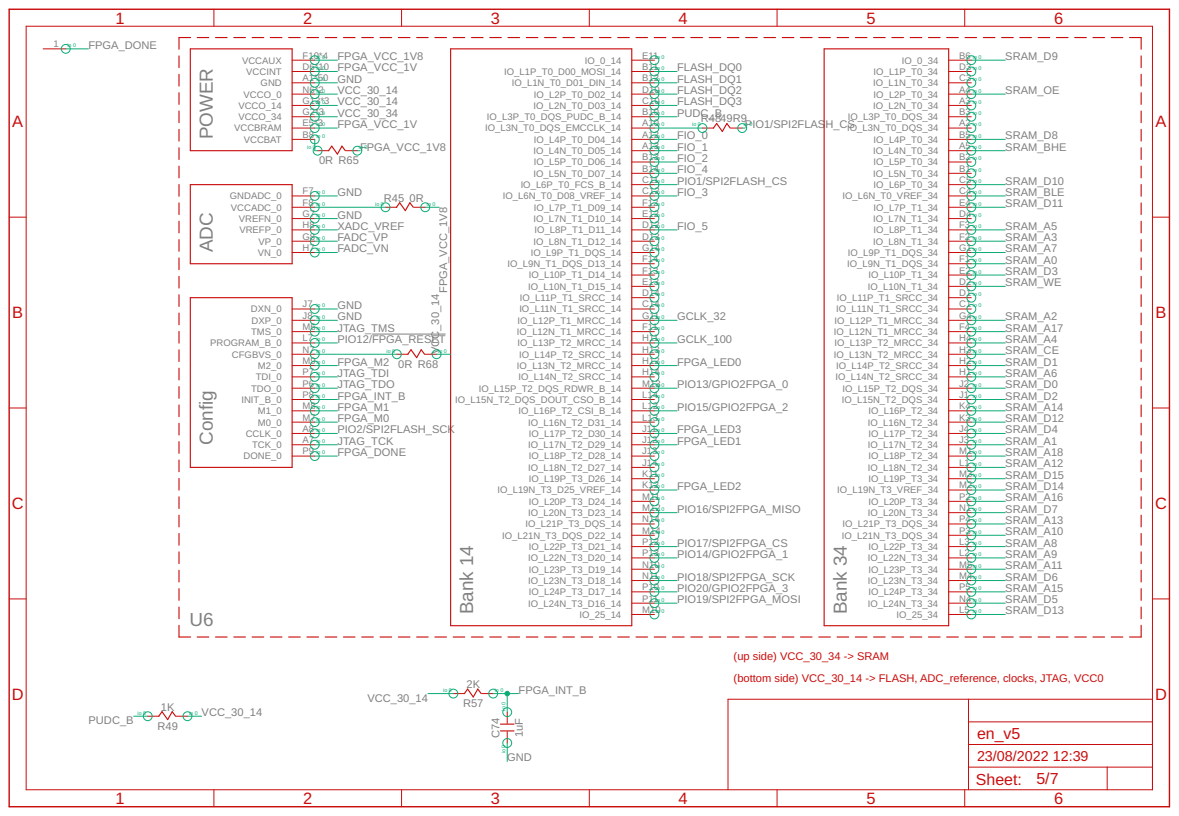
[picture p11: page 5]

(up side) VCC_30_34 -> SRAM
(bottom side) VCC_30_14 -> FLASH, ADC_reference, clocks, JTAG, VCC0

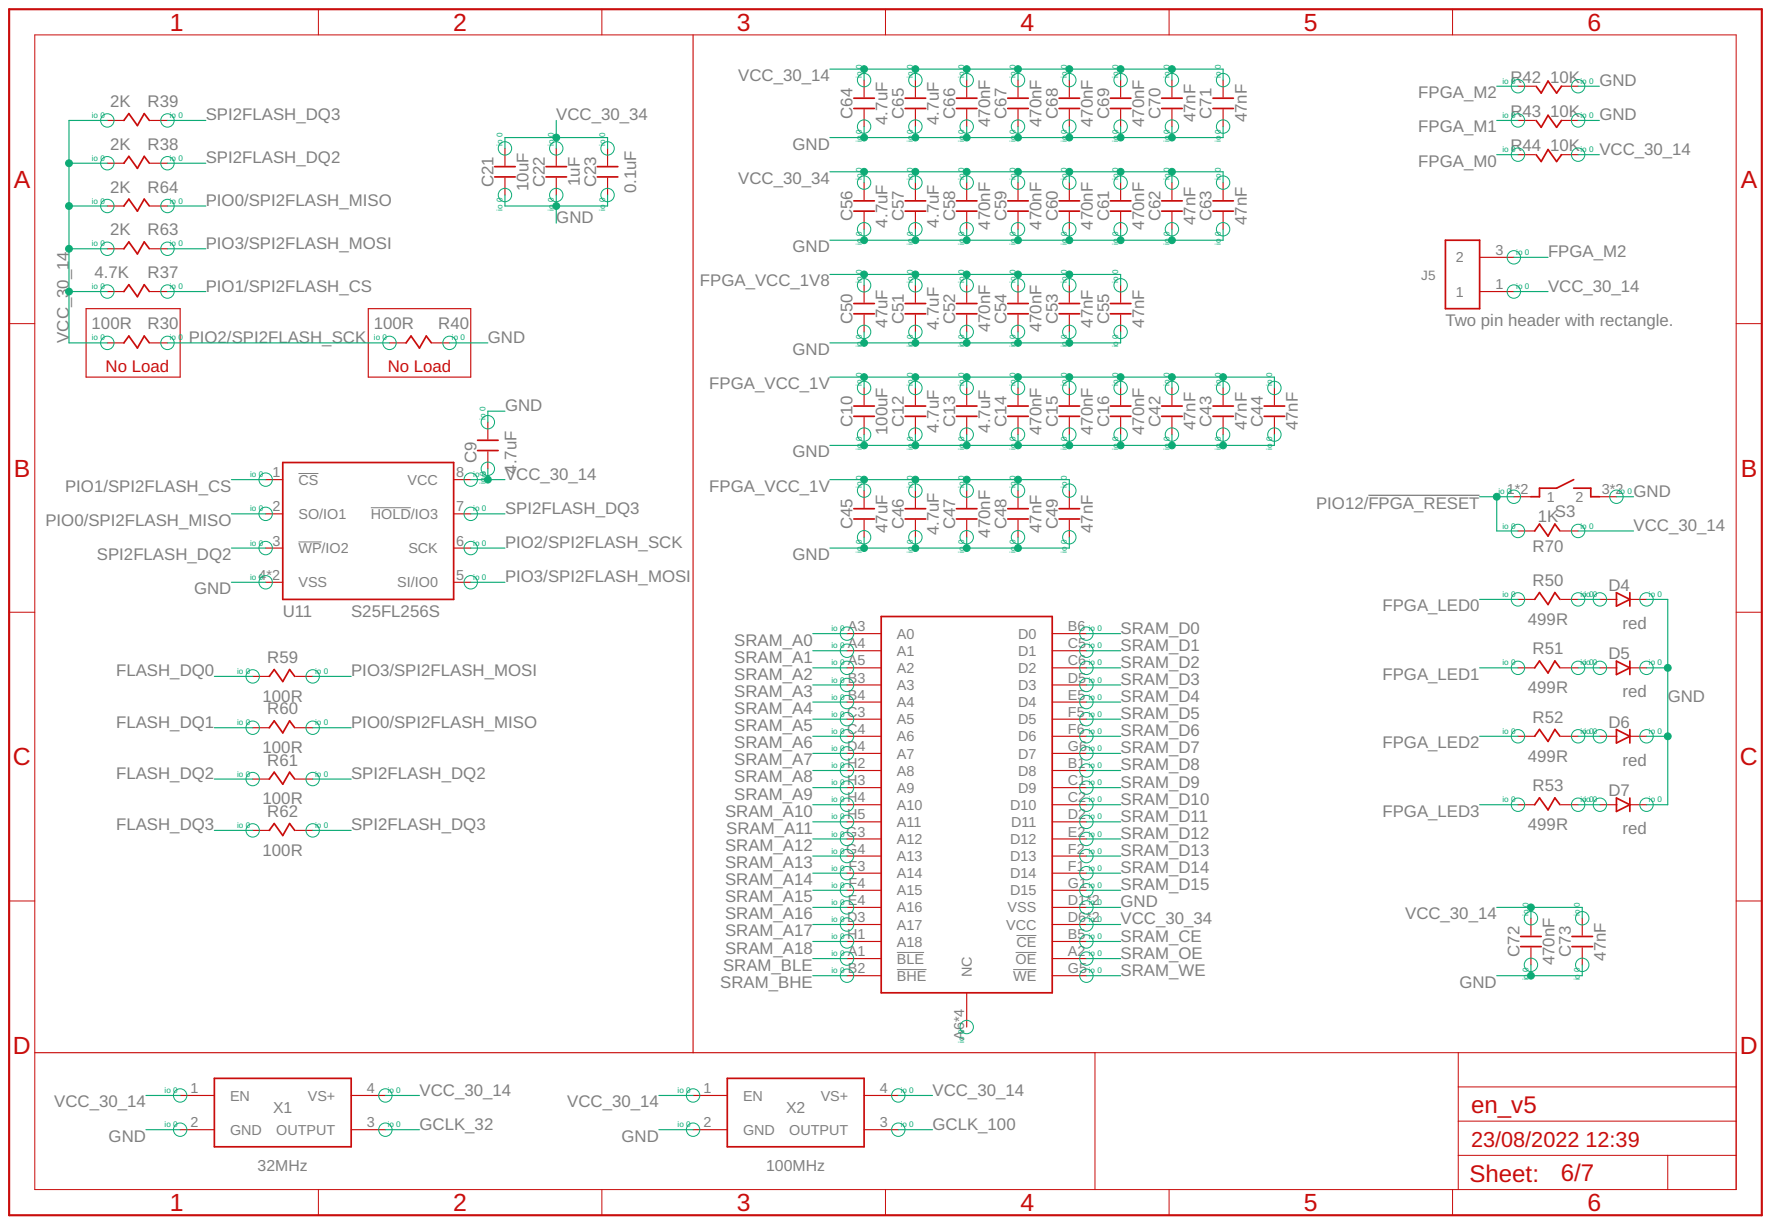
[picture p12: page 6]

2K R39 VCC_30_34 io 0 io 0 | | | | | | FPGA_M0

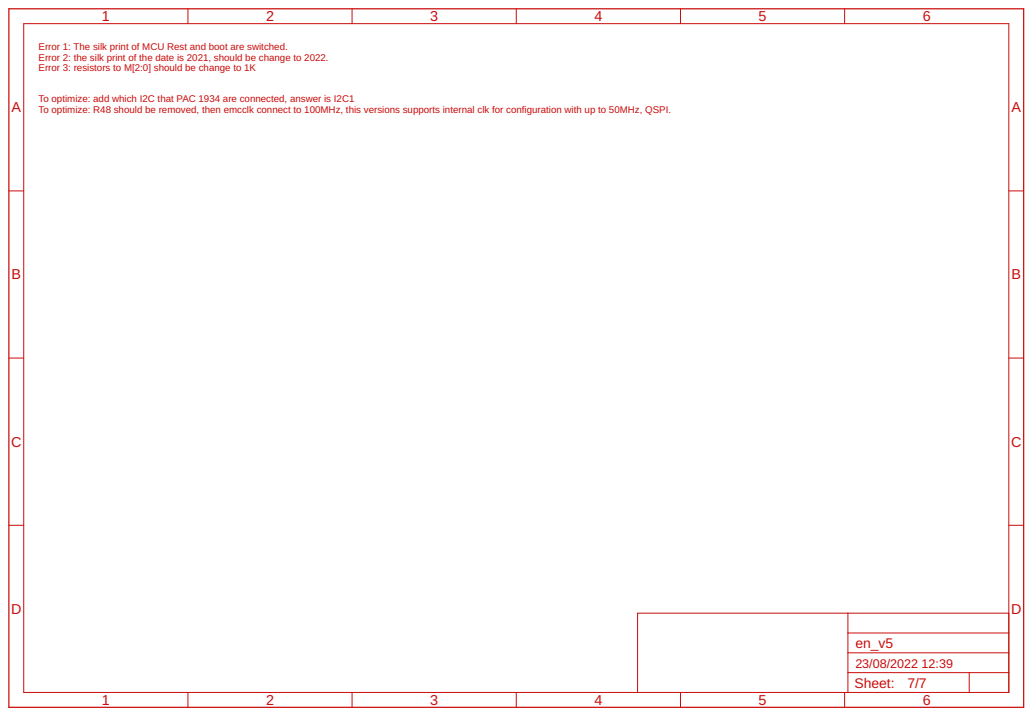
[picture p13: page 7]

Error 1: The silk print of MCU Rest and boot are switched. Error 2: the silk print of the date is 2021, should be change to 2022. Error 3: resistors to M[2:0] should be change to 1K

To optimize: add which I2C that PAC 1934 are connected, answer is I2C1
To optimize: R48 should be removed, then emcclk connect to 100MHz, this versions supports internal clk for configuration with up to 50MHz, QSPI.

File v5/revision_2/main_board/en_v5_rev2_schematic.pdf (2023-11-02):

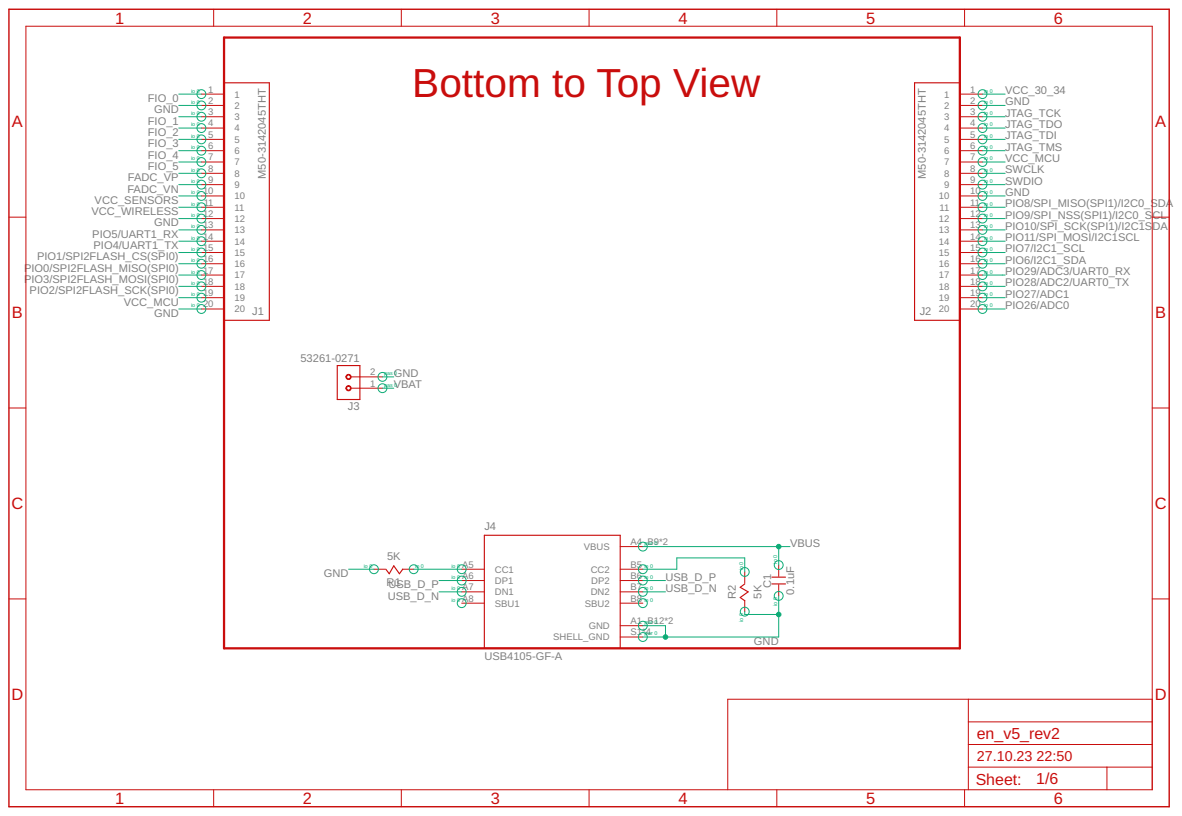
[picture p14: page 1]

Bottom to Top View

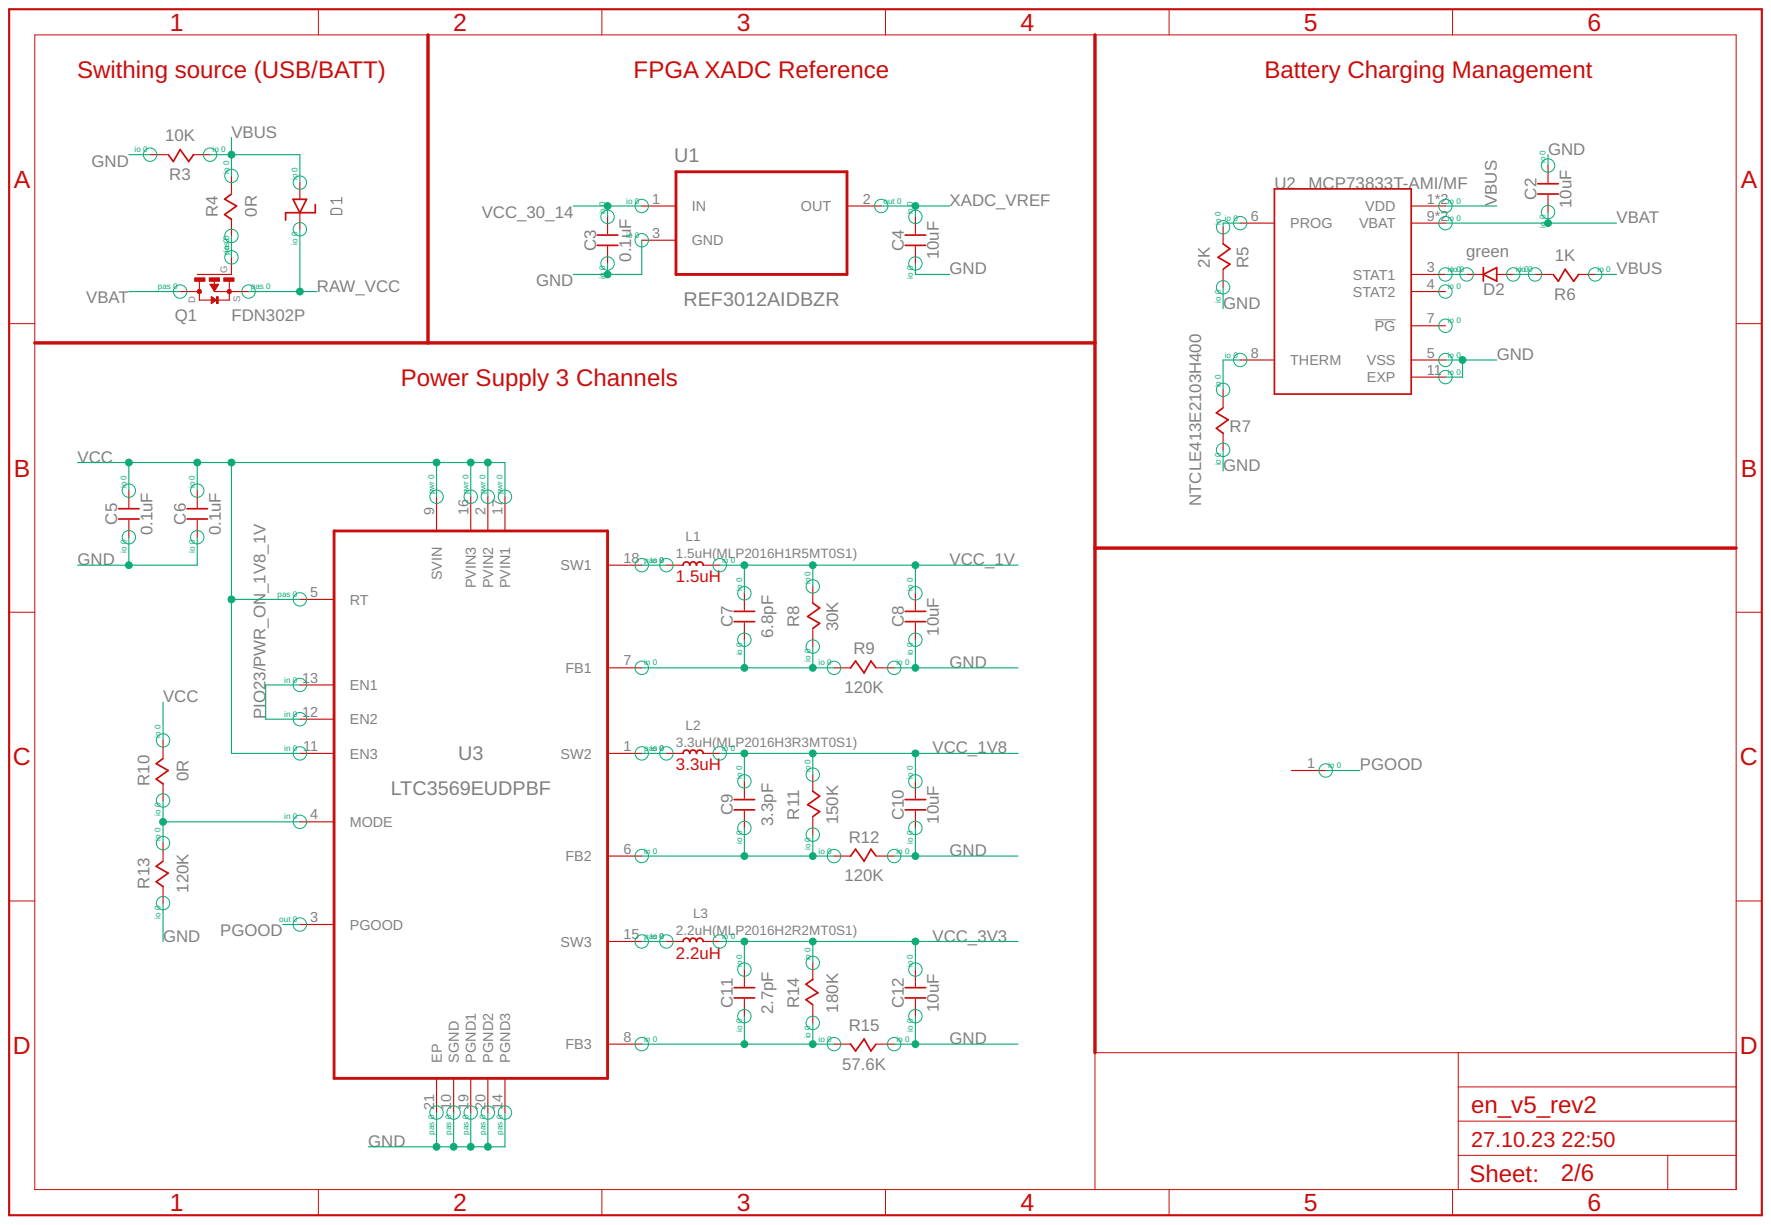
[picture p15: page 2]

Swithing source (USB/BATT) VBUS VBAT | FPGA XADC Reference GND | Battery Charging Management

L2 1 pas 0 io 0 io 0

L3 15 pas 0 io 0 io 0

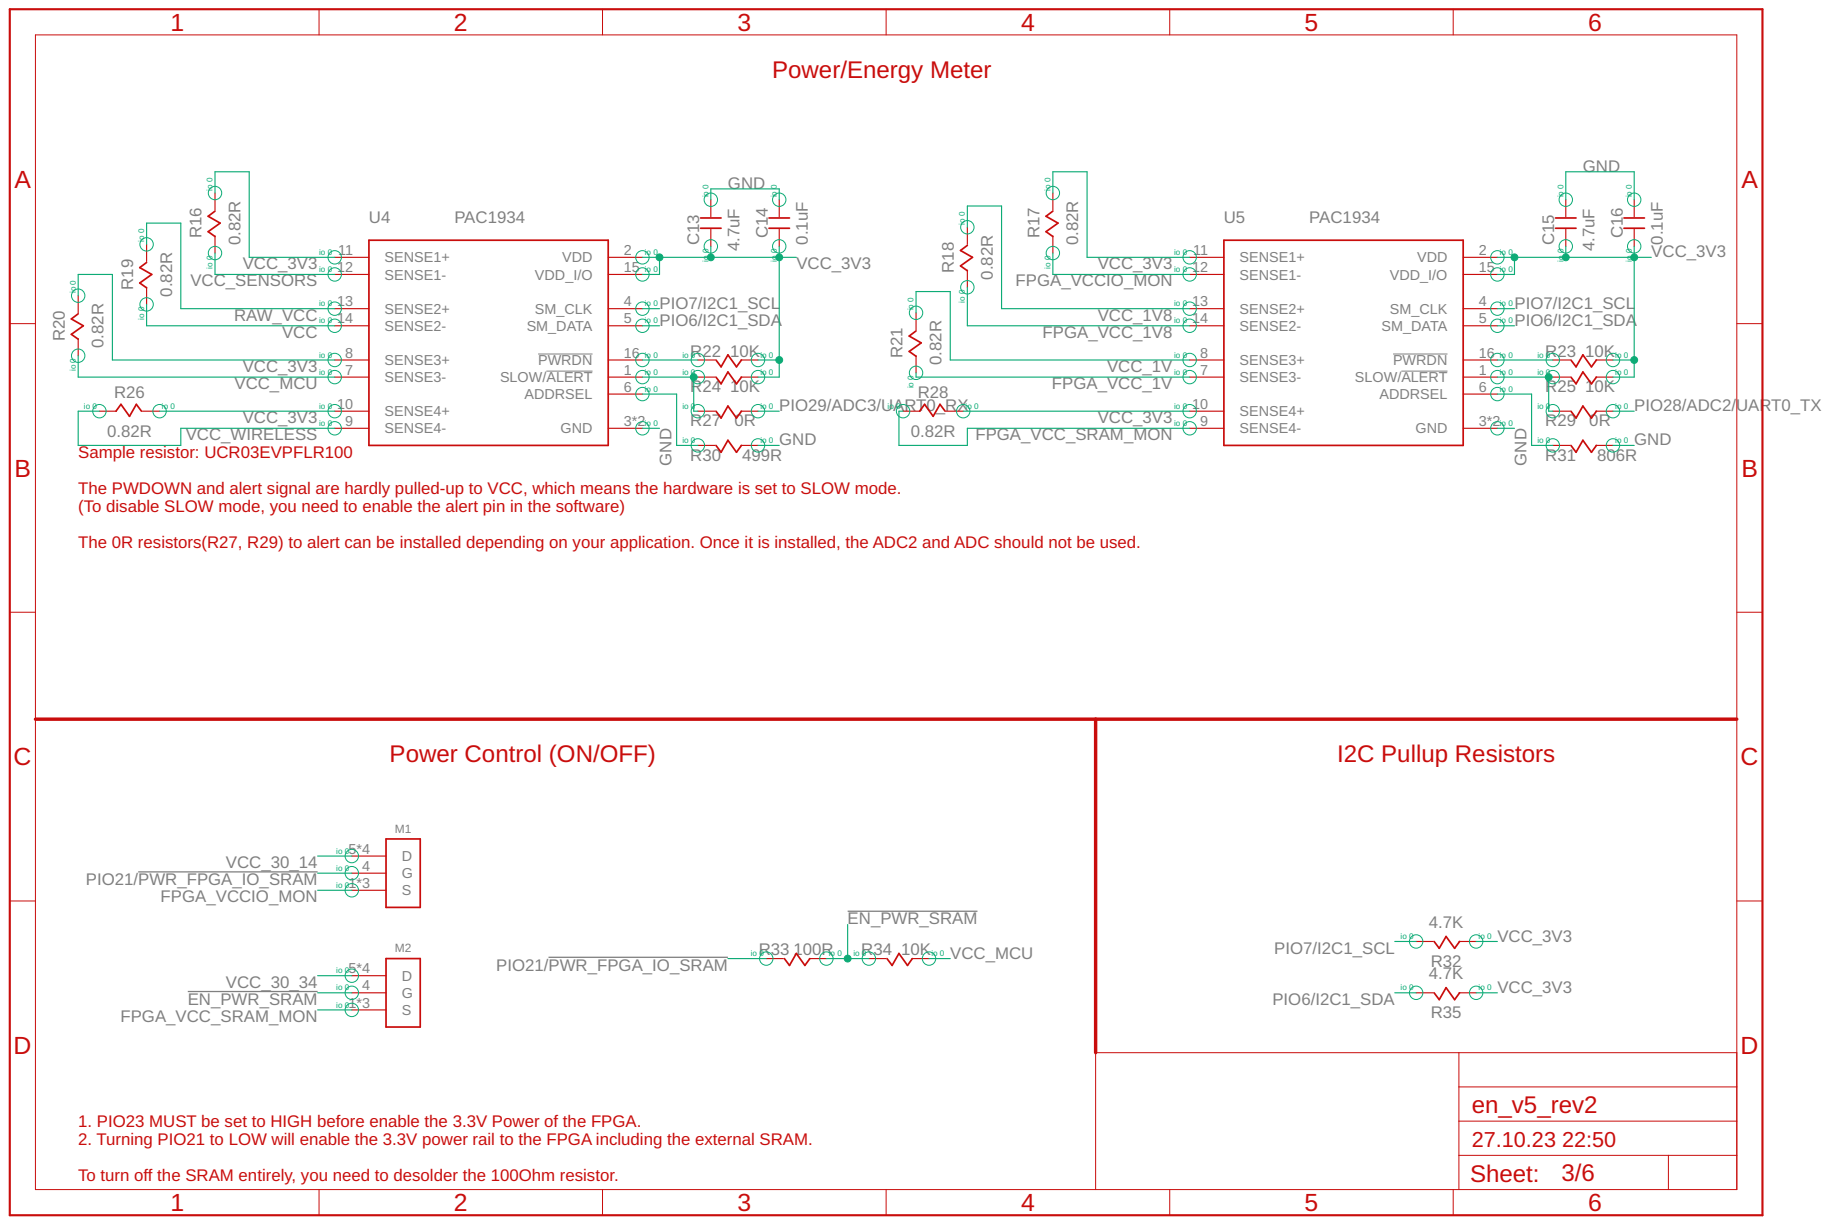
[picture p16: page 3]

The PWDOWN and alert signal are hardly pulled-up to VCC, which means the hardware is set to SLOW mode. (To disable SLOW mode, you need to enable the alert pin in the software)

The 0R resistors(R27, R29) to alert can be installed depending on your application. Once it is installed, the ADC2 and ADC should not be used.

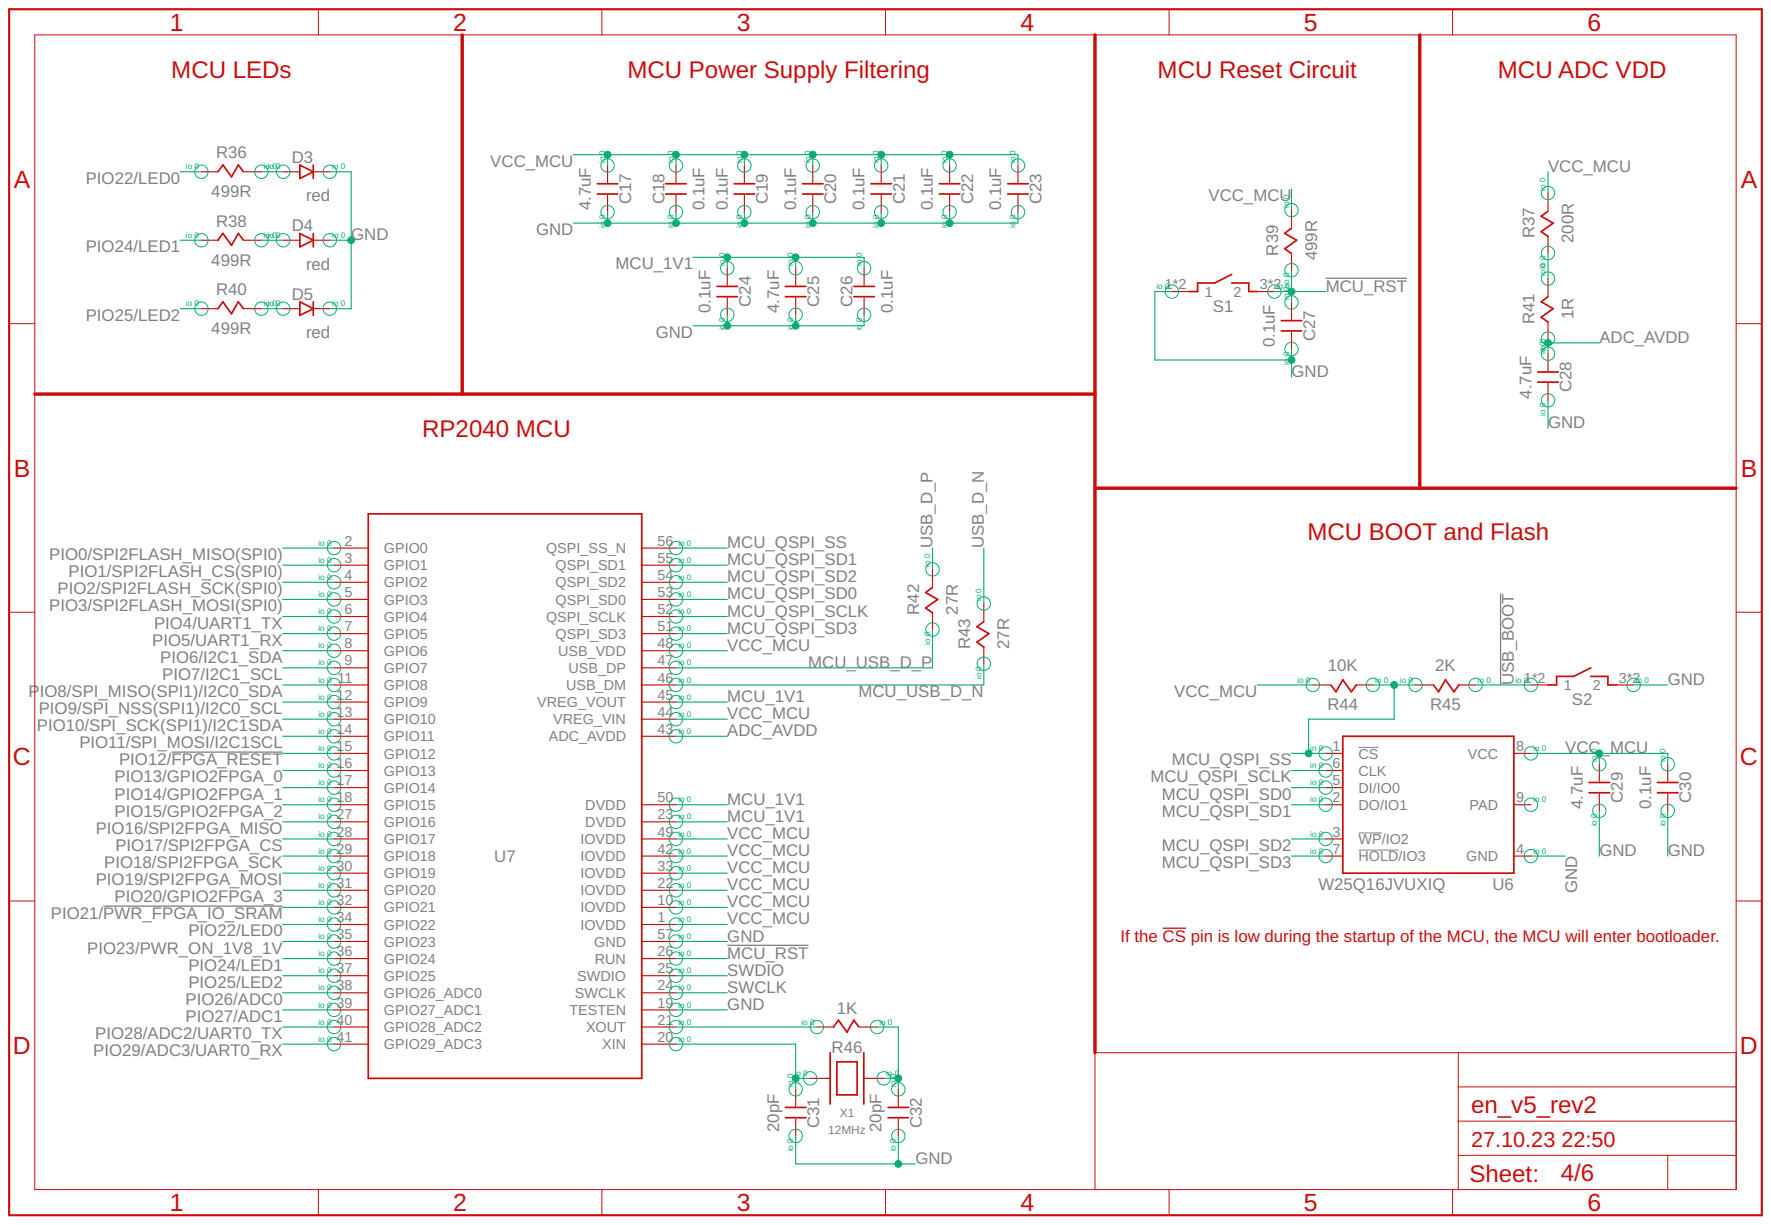
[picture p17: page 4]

MCU BOOT and Flash

If the CS pin is low during the startup of the MCU, the MCU will enter bootloader.

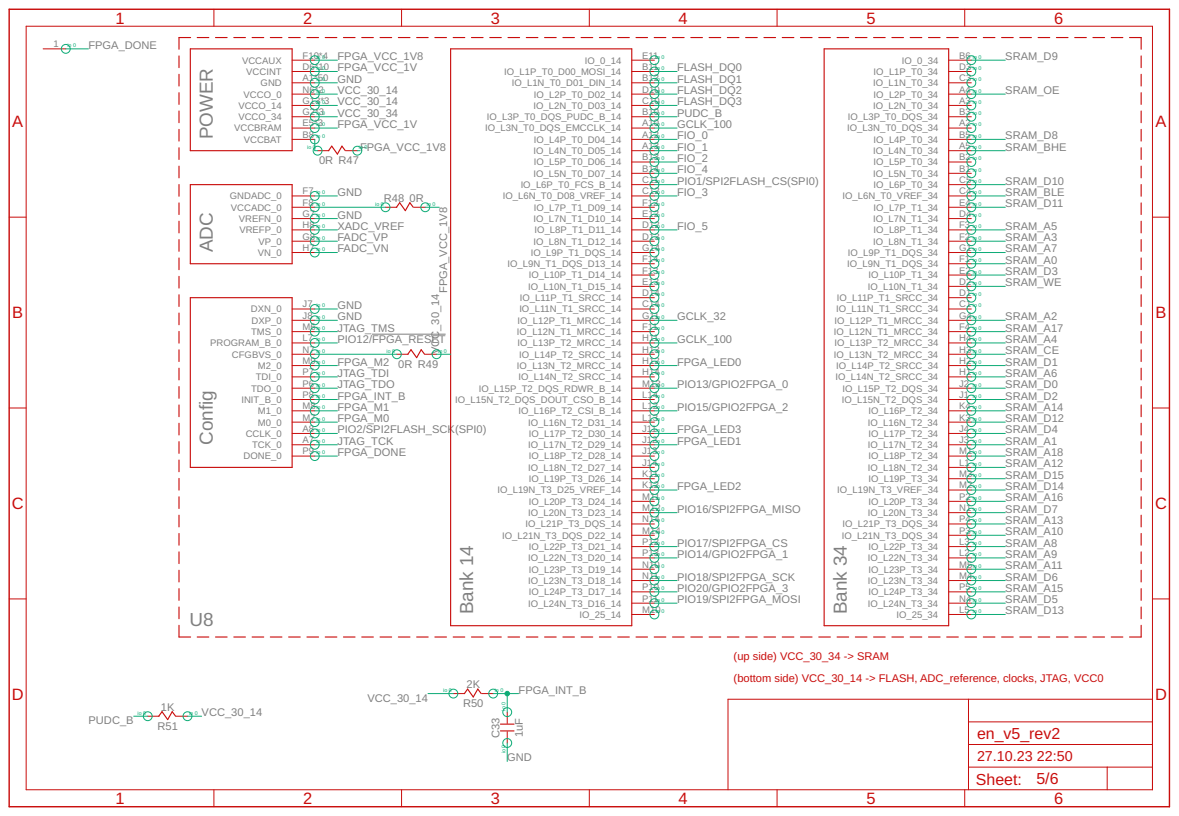
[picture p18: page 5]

(up side) VCC_30_34 -> SRAM
(bottom side) VCC_30_14 -> FLASH, ADC_reference, clocks, JTAG, VCC0


2K R53 io 0 io 0 | | | | FPGA_M0




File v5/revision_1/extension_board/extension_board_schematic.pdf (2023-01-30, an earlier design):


J1 J2 M50-3142045THT M50-3142045THT | 0.1uF C2

Serial Wire Debug to MCU

check the setting on the ENv5 Rev1.

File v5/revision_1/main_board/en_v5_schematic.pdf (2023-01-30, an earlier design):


Bottom to Top View


Swithing source (USB/BATT) VBUS VBAT | FPGA XADC Reference GND | Battery Charging Management

No Load Power Supply 3 Channels

L2 1 pas 0 io 0 io 0

L3 15 pas 0 io 0 io 0


The PWDOWN and alert signal are hardly pulled-up to VCC, which means the hardware is set to SLOW mode. (To disable SLOW mode, you need to enable the alert pin in the software)

The 0R resistors(R27, R29) to alert can be installed depending on your application. Once it is installed, the ADC2 and ADC should not be used.


MCU BOOT and Flash

If the CS pin is low during the startup of the MCU, the MCU will enter bootloader.


(up side) VCC_30_34 -> SRAM
(bottom side) VCC_30_14 -> FLASH, ADC_reference, clocks, JTAG, VCC0


2K R53 io 0 io 0 | | | | FPGA_M0

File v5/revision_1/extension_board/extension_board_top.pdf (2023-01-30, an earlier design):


VCC | TX | RX | EN |BOOT| GND FIO5 to FIO0 FADVN|FADVP|GND|VCC_MCU|SWCLK|SWDIO VCCMCU|GND|MISO|CS|SCK|MOSI +y +x+z J4 J5 J6 J3 J7 1uF 10K 10K 0R 100K 150K 0.1uF 2.2K 0.1uF 10K 10K 10K 10K 10K 10K 10K 0.1uF 10uF 1uF 2.2uF 0.1uF U1 MK1 U2 U3



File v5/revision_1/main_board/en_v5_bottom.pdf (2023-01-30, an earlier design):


10K

4.7K


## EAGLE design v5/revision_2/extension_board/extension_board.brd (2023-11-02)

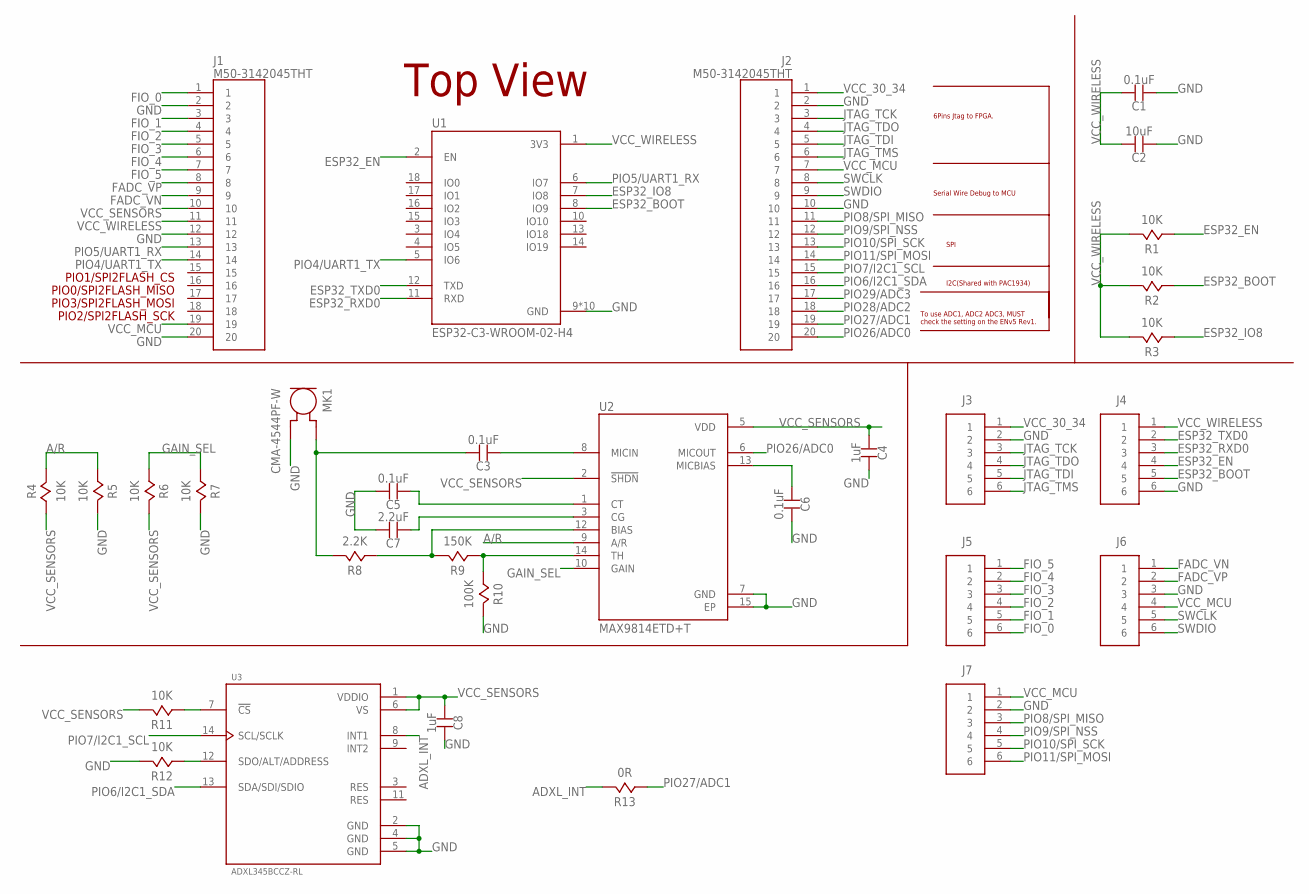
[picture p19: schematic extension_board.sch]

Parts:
C1, C3, C5, C6: 0.1uF; 0402
C2: 10uF; 0805
C4, C8: 1uF; 0402
C7: 2.2uF; 0402
J1, J2: M50-3142045THT; 20X1_HEADER_THT_1.27MM
J3, J4, J5, J6, J7: MALE_HEADER_6X1_2.54MM; HDR_6X1_2.54MM
MK1: CMA-4544PF-W; MIC_CMA-4544PF-W
R1, R2, R3, R4, R5, R6, R7, R11, R12: 10K; 0402
R8: 2.2K; 0402
R9: 150K; 0402
R10: 100K; 0402
R13: 0R; 0402
U1: ESP32-C3-WROOM-02-H4; MODULE_ESP32-C3-WROOM-02-H4
U2: MAX9814ETD+T; SON40P300X300X80-15N
U3: ADXL345BCCZ-RL; PQFN80P300X500X79-14N

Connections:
A/R: R4.2, R5.1, U2.9 (A/R)
ADXL_INT: R13.2, U3.8 (INT1)
ESP32_BOOT: J4.5, R2.1, U1.8 (IO9)
ESP32_EN: J4.4, R1.1, U1.2 (EN)
ESP32_IO8: R3.1, U1.7 (IO8)
ESP32_RXD0: J4.3, U1.11 (RXD)
ESP32_TXD0: J4.2, U1.12 (TXD)
FADC_VN: J1.9, J6.1
FADC_VP: J1.8, J6.2
FIO_0: J1.1, J5.6
FIO_1: J1.3, J5.5
FIO_2: J1.4, J5.4
FIO_3: J1.5, J5.3
FIO_4: J1.6, J5.2
FIO_5: J1.7, J5.1
GAIN_SEL: R6.1, R7.1, U2.10 (GAIN)
GND: C1.1, C2.1, C4.2, C5.2, C6.2, C7.2, C8.2, J1.2, J1.12, J1.20, J2.2, J2.10, J3.2, J4.6, J6.3, J7.2, MK1.2 (GND), R5.2, R7.2, R10.2, R12.2, U1.9 (GND), U1.19 (GND), U1.20 (GND), U1.21 (GND), U1.22 (GND), U1.23 (GND), U1.24 (GND), U1.25 (GND), U1.26 (GND), U1.27 (GND), U2.7 (GND), U2.15 (EP), U3.2 (GND), U3.4 (GND), U3.5 (GND)
JTAG_TCK: J2.3, J3.3
JTAG_TDI: J2.5, J3.5
JTAG_TDO: J2.4, J3.4
JTAG_TMS: J2.6, J3.6
MIC_INPUT: C3.2, MK1.1 (OUT), R8.2
unnamed: R11.1, U3.7 (!CS)
unnamed: R12.1, U3.12 (SDO/ALT/ADDRESS)
unnamed: C5.1, U2.1 (CT)
unnamed: C7.1, U2.3 (CG)
unnamed: C3.1, U2.8 (MICIN)
unnamed: R8.1, R9.2, U2.12 (BIAS)
unnamed: R9.1, R10.1, U2.14 (TH)
unnamed: C6.1, U2.13 (MICBIAS)
PIO4/UART1_TX: J1.14, U1.5 (IO6)
PIO5/UART1_RX: J1.13, U1.6 (IO7)
PIO6/I2C1_SDA: J2.16, U3.13 (SDA/SDI/SDIO)
PIO7/I2C1_SCL: J2.15, U3.14 (SCL/SCLK)
PIO8/SPI_MISO: J2.11, J7.3
PIO9/SPI_NSS: J2.12, J7.4
PIO10/SPI_SCK: J2.13, J7.5
PIO11/SPI_MOSI: J2.14, J7.6
PIO26/ADC0: J2.20, U2.6 (MICOUT)
PIO27/ADC1: J2.19, R13.1
PIO28/ADC2: J2.18
PIO29/ADC3: J2.17
SWCLK: J2.8, J6.5
SWDIO: J2.9, J6.6
VCC_30_34: J2.1, J3.1
VCC_MCU: J1.19, J2.7, J6.4, J7.1
VCC_SENSORS: C4.1, C8.1, J1.10, R4.1, R6.2, R11.2, U2.2 (!SHDN), U2.5 (VDD), U3.1 (VDDIO), U3.6 (VS)
VCC_WIRELESS: C1.2, C2.2, J1.11, J4.1, R1.2, R2.2, R3.2, U1.1 (3V3)

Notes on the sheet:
Top View
PIO1/SPI2FLASH_CS
PIO0/SPI2FLASH_MISO
PIO3/SPI2FLASH_MOSI
PIO2/SPI2FLASH_SCK
To use ADC1, ADC2 ADC3, MUST check the setting on the ENv5 Rev1.
6Pins Jtag to FPGA.
Serial Wire Debug to MCU
SPI
I2C(Shared with PAC1934)

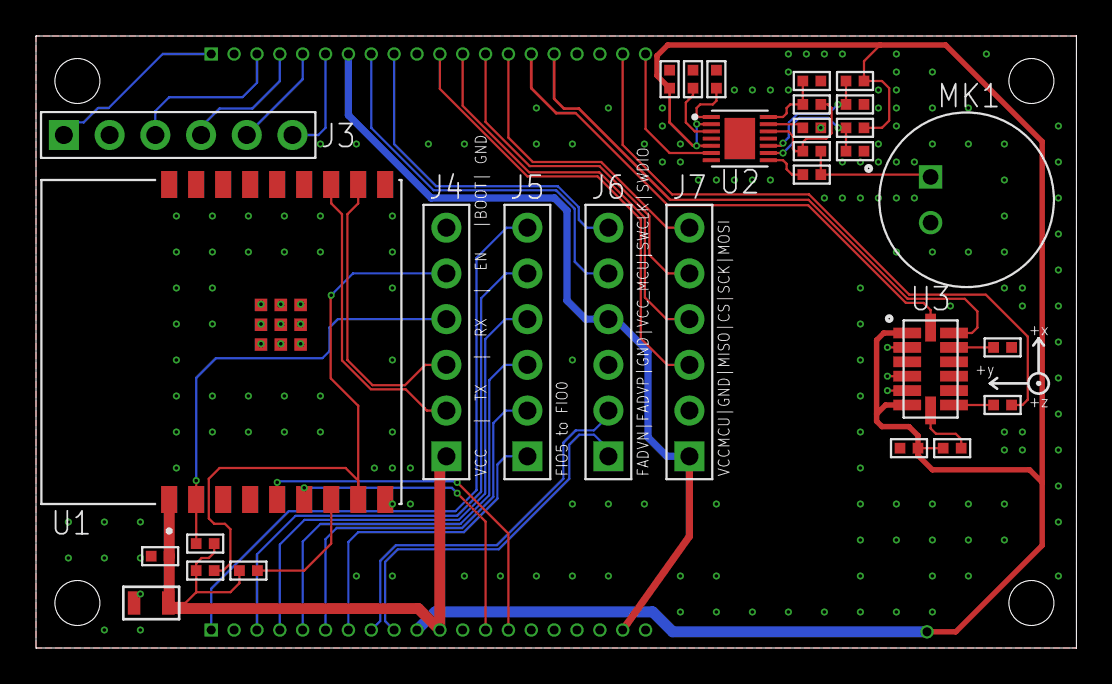
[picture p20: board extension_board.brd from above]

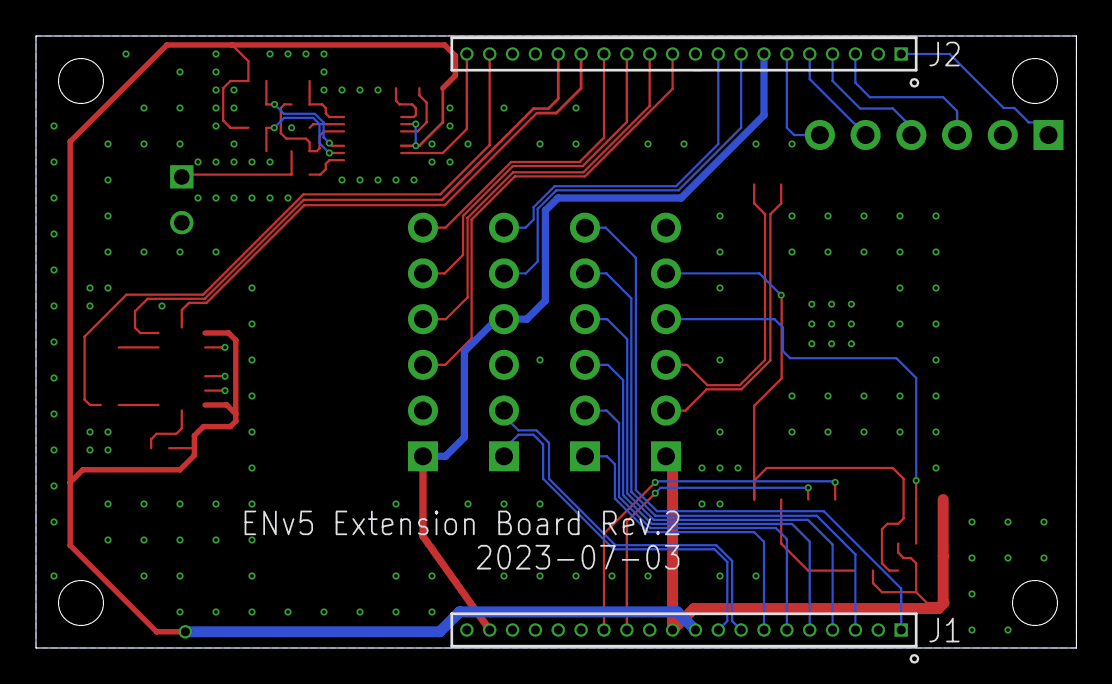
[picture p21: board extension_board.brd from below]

Board: 2 copper layers, 57.8 x 34.0 mm, 32 parts (2 on the bottom side), 46 nets.

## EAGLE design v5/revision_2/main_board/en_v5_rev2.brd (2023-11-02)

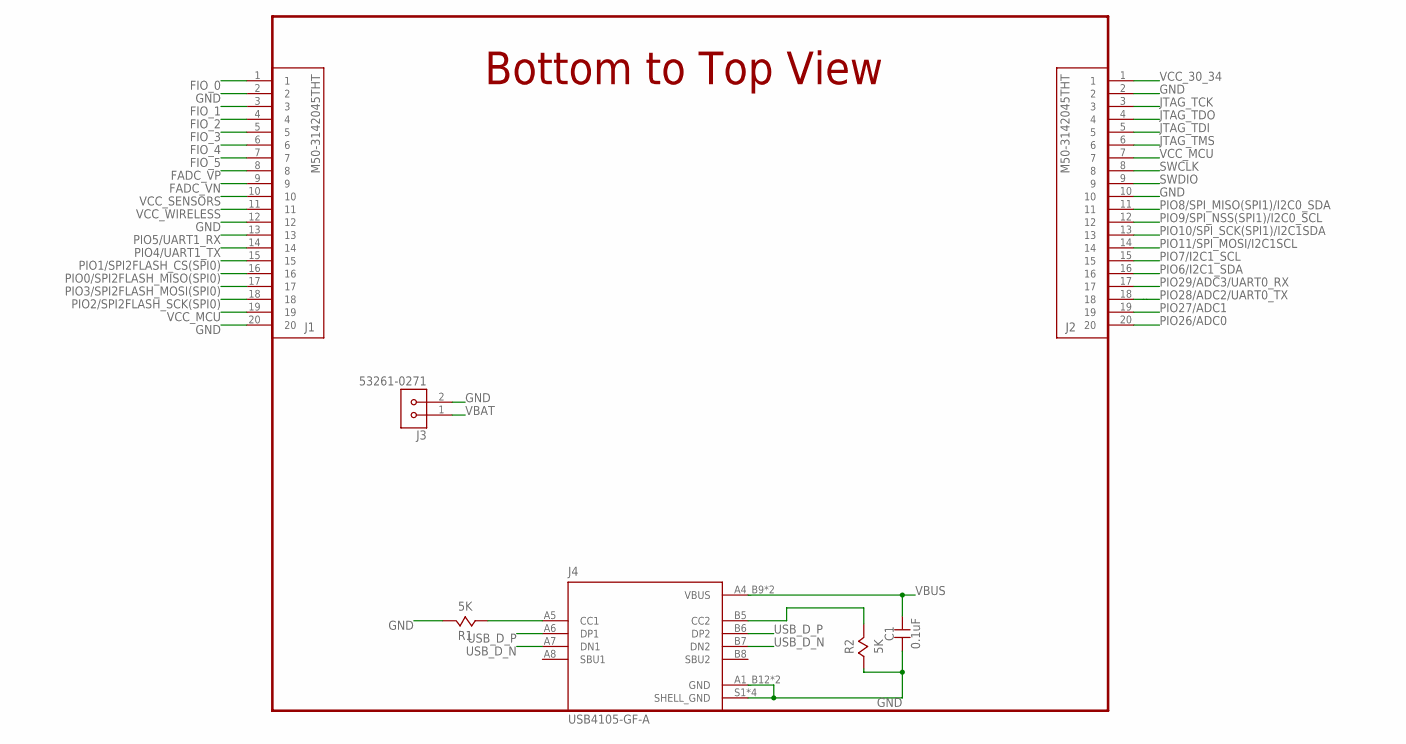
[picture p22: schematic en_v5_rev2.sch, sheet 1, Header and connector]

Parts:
C1: 0.1uF; 0805
J1, J2: M50-3142045THT; 20X1_HEADER_THT_1.27MM
J3: 53261-0271; MOLEX_53261-0271
J4: USB4105-GF-A; GCT_USB4105-GF-A
R1, R2: 5K; 0402

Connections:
FADC_VN: J1.9; also elsewhere on the board
FADC_VP: J1.8; also elsewhere on the board
FIO_0: J1.1; also elsewhere on the board
FIO_1: J1.3; also elsewhere on the board
FIO_2: J1.4; also elsewhere on the board
FIO_3: J1.5; also elsewhere on the board
FIO_4: J1.6; also elsewhere on the board
FIO_5: J1.7; also elsewhere on the board
GND: C1.1, J1.2, J1.12, J1.20, J2.2, J2.10, J3.2, J4.A1_B12 (GND), J4.B1_A12 (GND), J4.S1 (SHELL_GND), J4.S2 (SHELL_GND), J4.S3 (SHELL_GND), J4.S4 (SHELL_GND), R1.2, R2.1; also elsewhere on the board
JTAG_TCK: J2.3; also elsewhere on the board
JTAG_TDI: J2.5; also elsewhere on the board
JTAG_TDO: J2.4; also elsewhere on the board
JTAG_TMS: J2.6; also elsewhere on the board
unnamed: J4.B5 (CC2), R2.2
unnamed: J4.A5 (CC1), R1.1
PIO0/SPI2FLASH_MISO(SPI0): J1.16; also elsewhere on the board
PIO1/SPI2FLASH_CS(SPI0): J1.15; also elsewhere on the board
PIO2/SPI2FLASH_SCK(SPI0): J1.18; also elsewhere on the board
PIO3/SPI2FLASH_MOSI(SPI0): J1.17; also elsewhere on the board
PIO4/UART1_TX: J1.14; also elsewhere on the board
PIO5/UART1_RX: J1.13; also elsewhere on the board
PIO6/I2C1_SDA: J2.16; also elsewhere on the board
PIO7/I2C1_SCL: J2.15; also elsewhere on the board
PIO8/SPI_MISO(SPI1)/I2C0_SDA: J2.11; also elsewhere on the board
PIO9/SPI_NSS(SPI1)/I2C0_SCL: J2.12; also elsewhere on the board
PIO10/SPI_SCK(SPI1)/I2C1SDA: J2.13; also elsewhere on the board
PIO11/SPI_MOSI/I2C1SCL: J2.14; also elsewhere on the board
PIO26/ADC0: J2.20; also elsewhere on the board
PIO27/ADC1: J2.19; also elsewhere on the board
PIO28/ADC2/UART0_TX: J2.18; also elsewhere on the board
PIO29/ADC3/UART0_RX: J2.17; also elsewhere on the board
SWCLK: J2.8; also elsewhere on the board
SWDIO: J2.9; also elsewhere on the board
USB_D_N: J4.A7 (DN1), J4.B7 (DN2); also elsewhere on the board
USB_D_P: J4.A6 (DP1), J4.B6 (DP2); also elsewhere on the board
VBAT: J3.1; also elsewhere on the board
VBUS: C1.2, J4.A4_B9 (VBUS), J4.B4_A9 (VBUS); also elsewhere on the board
VCC_30_34: J2.1; also elsewhere on the board
VCC_MCU: J1.19, J2.7; also elsewhere on the board
VCC_SENSORS: J1.10; also elsewhere on the board
VCC_WIRELESS: J1.11; also elsewhere on the board

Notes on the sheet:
Bottom to Top View

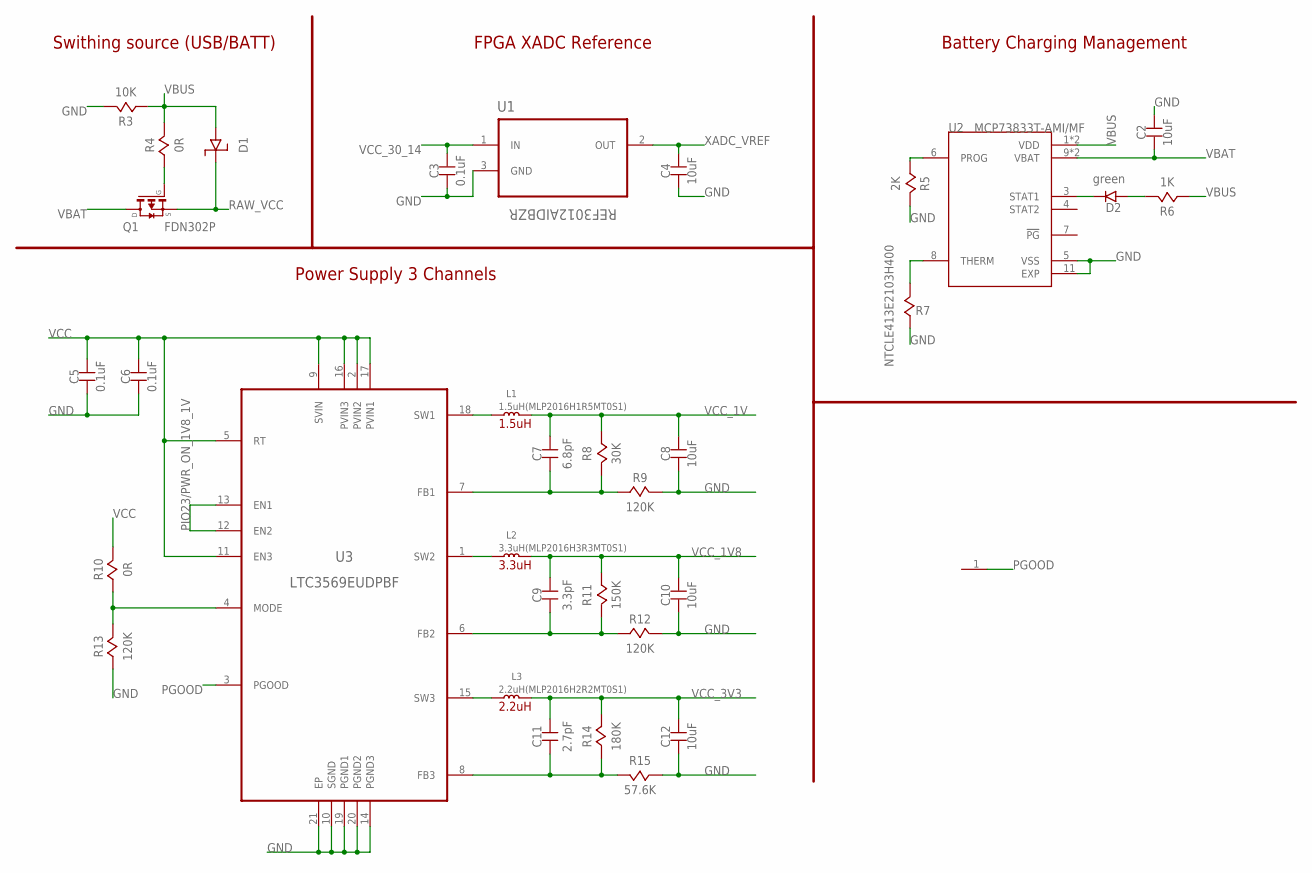
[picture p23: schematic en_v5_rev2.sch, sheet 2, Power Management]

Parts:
C2: 10uF; 0805
C3: 0.1uF; 0402
C4, C8, C10, C12: 10uF; CAPC1608-0603
C5, C6: 0.1uF; CAPC1608-0603
C7: 6.8pF; 0402
C9: 3.3pF; 0402
C11: 2.7pF; 0402
D1: DIODEB5817W; SOD-123
D2: green; 0402
L1: 1.5uH(MLP2016H1R5MT0S1); INDC2016X120N
L2: 3.3uH(MLP2016H3R3MT0S1); INDC2016X120N
L3: 2.2uH(MLP2016H2R2MT0S1); INDC2016X120N
Q1: FDN302P; SSOT-3
R3: 10K; 0402
R4, R10: 0R; 0402
R5: 2K; 0402
R6: 1K; 0402
R7: NTCLE413E2103H400; THT_2
R8: 30K; 0402
R9, R12, R13: 120K; 0402
R11: 150K; 0402
R14: 180K; 0402
R15: 57.6K; 0402
TP2: TEST_POINTSMD; SMD_PAD
U1: REF3012AIDBZR; SOT-23(3PIN)
U2: MCP73833T-AMI/MF; DFN-10(3X3X0.9)
U3: LTC3569EUDPBF; QFN40P300X300X80-21N

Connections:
GND: C2.2, C3.1, C4.1, C5.2, C6.2, C8.1, C10.2, C12.2, R3.2, R5.2, R7.P$1 (1), R9.2, R12.2, R13.1, R15.2, U1.3 (GND), U2.5 (VSS), U2.11 (EXP), U3.10 (SGND), U3.14 (PGND3), U3.19 (PGND1), U3.20 (PGND2), U3.21 (EP); also elsewhere on the board
unnamed: R7.P$2 (2), U2.8 (THERM)
unnamed: R5.1, U2.6 (PROG)
unnamed: Q1.1 (G), R4.1
unnamed: L2.1, U3.1 (SW2)
unnamed: L1.1, U3.18 (SW1)
unnamed: D2.2, U2.3 (STAT1)
unnamed: D2.1, R6.2
unnamed: C7.2, R8.2, R9.1, U3.7 (FB1)
unnamed: L3.2, U3.15 (SW3)
unnamed: C11.2, R14.2, R15.1, U3.8 (FB3)
unnamed: C9.2, R11.2, R12.1, U3.6 (FB2)
unnamed: R10.1, R13.2, U3.4 (MODE)
PGOOD: TP2.1, U3.3 (PGOOD)
PIO23/PWR_ON_1V8_1V: U3.12 (EN2), U3.13 (EN1); also elsewhere on the board
RAW_VCC: D1.1 (C), Q1.2 (S); also elsewhere on the board
VBAT: C2.1, Q1.3 (D), U2.9 (VBAT), U2.10 (VBAT); also elsewhere on the board
VBUS: D1.2 (A), R3.1, R4.2, R6.1, U2.1 (VDD), U2.2 (VDD); also elsewhere on the board
VCC: C5.1, C6.1, R10.2, U3.2 (PVIN2), U3.5 (RT), U3.9 (SVIN), U3.11 (EN3), U3.16 (PVIN3), U3.17 (PVIN1); also elsewhere on the board
VCC_1V: C7.1, C8.2, L1.2, R8.1; also elsewhere on the board
VCC_1V8: C9.1, C10.1, L2.2, R11.1; also elsewhere on the board
VCC_3V3: C11.1, C12.1, L3.1, R14.1; also elsewhere on the board
VCC_30_14: C3.2, U1.1 (IN); also elsewhere on the board
XADC_VREF: C4.2, U1.2 (OUT); also elsewhere on the board

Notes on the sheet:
1.5uH
3.3uH
2.2uH
Power Supply 3 Channels
Swithing source (USB/BATT)
FPGA XADC Reference
Battery Charging Management

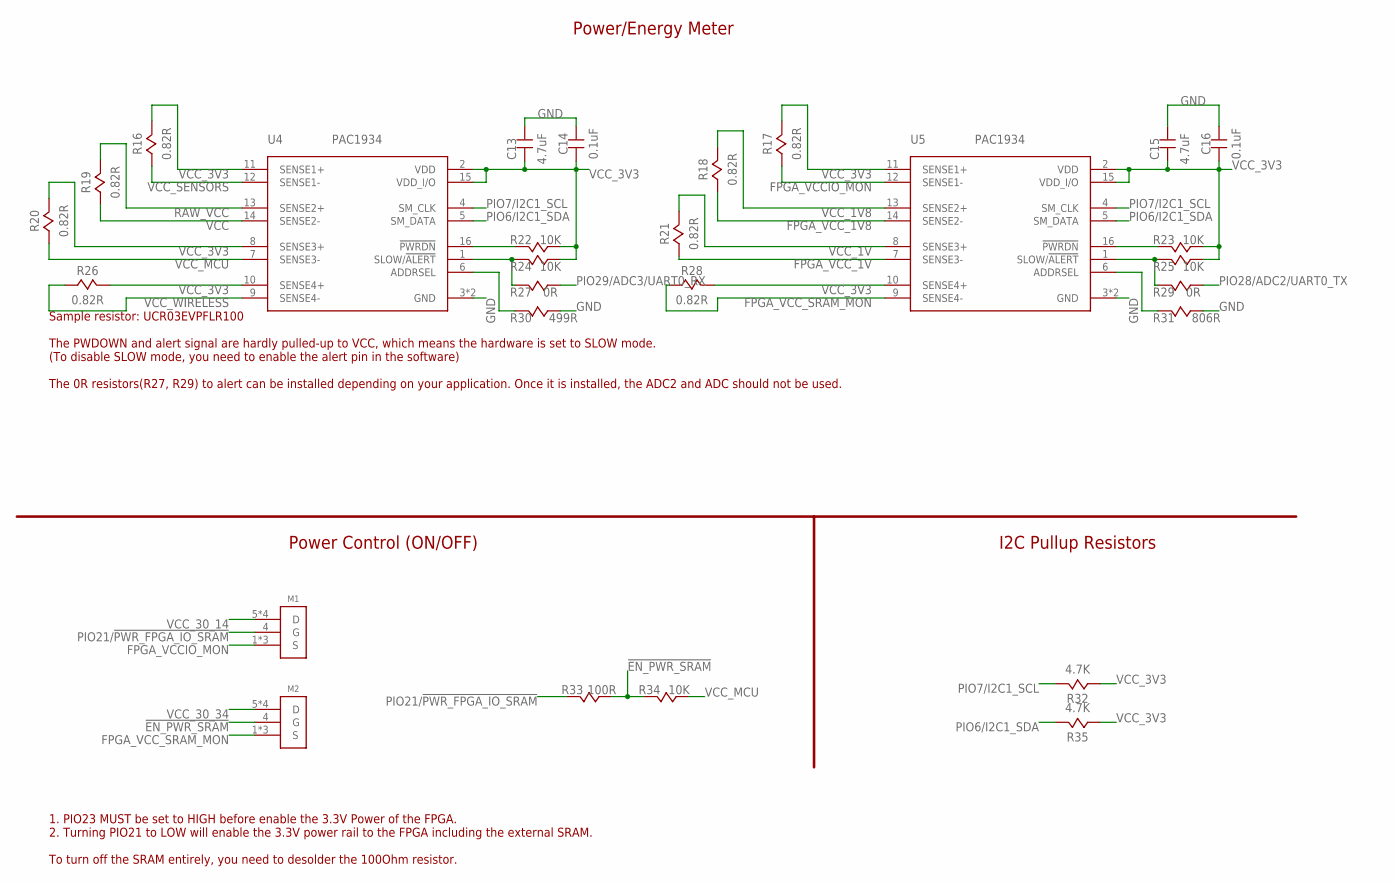
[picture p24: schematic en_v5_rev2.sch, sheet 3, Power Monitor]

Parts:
C13, C15: 4.7uF; CAPC1608-0603
C14, C16: 0.1uF; 0402
M1, M2: SISS23DN; POWERPAK1212-8
R16, R17, R18, R19, R20, R21, R26, R28: 0.82R; 0603
R22, R23, R24, R25, R34: 10K; 0402
R27, R29: 0R; 0402
R30: 499R; 0402
R31: 806R; 0402
R32, R35: 4.7K; 0402
R33: 100R; 0402
U4, U5: PAC1934; UQFN-16(4×4×0.5MM)

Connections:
!EN_PWR_SRAM: M2.4 (G), R33.1, R34.2
FPGA_VCCIO_MON: M1.1 (S), M1.2 (S), M1.3 (S), R17.1, U5.12 (SENSE1-)
FPGA_VCC_1V: R21.1, U5.7 (SENSE3-); also elsewhere on the board
FPGA_VCC_1V8: R18.1, U5.14 (SENSE2-); also elsewhere on the board
FPGA_VCC_SRAM_MON: M2.1 (S), M2.2 (S), M2.3 (S), R28.1, U5.9 (SENSE4-)
GND: C13.2, C14.2, C15.2, C16.2, R30.1, R31.1, U4.3 (GND), U4.17 (GND), U5.3 (GND), U5.17 (GND); also elsewhere on the board
unnamed: R24.2, R27.2, U4.1 (SLOW/!ALERT)
unnamed: R25.2, R29.2, U5.1 (SLOW/!ALERT)
unnamed: R22.2, U4.16 (!PWRDN)
unnamed: R30.2, U4.6 (ADDRSEL)
unnamed: R23.2, U5.16 (!PWRDN)
unnamed: R31.2, U5.6 (ADDRSEL)
PIO6/I2C1_SDA: R35.2, U4.5 (SM_DATA), U5.5 (SM_DATA); also elsewhere on the board
PIO7/I2C1_SCL: R32.2, U4.4 (SM_CLK), U5.4 (SM_CLK); also elsewhere on the board
PIO21/!PWR_FPGA_IO_SRAM: M1.4 (G), R33.2; also elsewhere on the board
PIO28/ADC2/UART0_TX: R29.1; also elsewhere on the board
PIO29/ADC3/UART0_RX: R27.1; also elsewhere on the board
RAW_VCC: R19.2, U4.13 (SENSE2+); also elsewhere on the board
VCC: R19.1, U4.14 (SENSE2-); also elsewhere on the board
VCC_1V: R21.2, U5.8 (SENSE3+); also elsewhere on the board
VCC_1V8: R18.2, U5.13 (SENSE2+); also elsewhere on the board
VCC_3V3: C13.1, C14.1, C15.1, C16.1, R16.2, R17.2, R20.2, R22.1, R23.1, R24.1, R25.1, R26.2, R28.2, R32.1, R35.1, U4.2 (VDD), U4.8 (SENSE3+), U4.10 (SENSE4+), U4.11 (SENSE1+), U4.15 (VDD_I/O), U5.2 (VDD), U5.10 (SENSE4+), U5.11 (SENSE1+), U5.15 (VDD_I/O); also elsewhere on the board
VCC_30_14: M1.5 (D), M1.6 (D), M1.7 (D), M1.8 (D); also elsewhere on the board
VCC_30_34: M2.5 (D), M2.6 (D), M2.7 (D), M2.8 (D); also elsewhere on the board
VCC_MCU: R20.1, R34.1, U4.7 (SENSE3-); also elsewhere on the board
VCC_SENSORS: R16.1, U4.12 (SENSE1-); also elsewhere on the board
VCC_WIRELESS: R26.1, U4.9 (SENSE4-); also elsewhere on the board

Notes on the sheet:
Sample resistor: UCR03EVPFLR100 The PWDOWN and alert signal are hardly pulled-up to VCC, which means the hardware is set to SLOW mode. (To disable SLOW mode, you need to enable the alert pin in the software) The 0R resistors(R27, R29) to alert can be installed depending on your application. Once it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
Power/Energy Meter
Power Control (ON/OFF)
I2C Pullup Resistors
1. PIO23 MUST be set to HIGH before enable the 3.3V Power of the FPGA. 2. Turning PIO21 to LOW will enable the 3.3V power rail to the FPGA including the external SRAM. To turn off the SRAM entirely, you need to desolder the 100Ohm resistor.

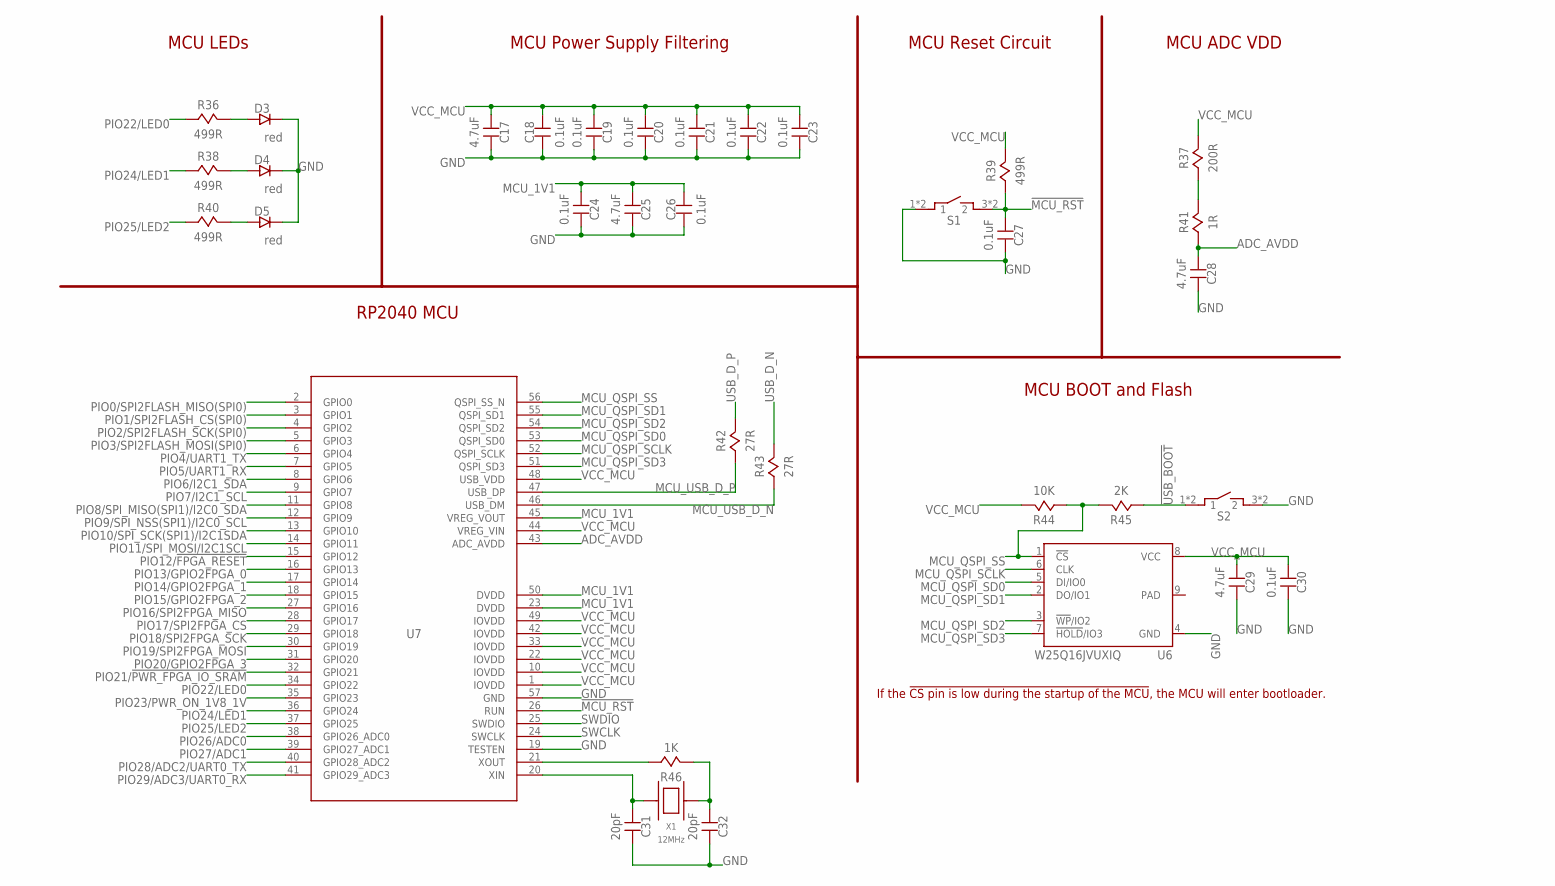
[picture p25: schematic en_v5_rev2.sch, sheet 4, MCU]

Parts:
C17, C25, C28, C29: 4.7uF; CAPC1608-0603
C18, C19, C20, C21, C22, C23, C24, C26, C27, C30: 0.1uF; 0402
C31, C32: 20pF; 0402
D3, D4, D5: red; 0402
R36, R38, R39, R40: 499R; 0402
R37: 200R; 0402
R41: 1R; 0402
R42, R43: 27R; 0402
R44: 10K; 0402
R45: 2K; 0402
R46: 1K; 0402
S1, S2: TACTILE-SWITCH
U6: W25Q16JVUXIQ; USON8-2X3MM
U7: RP2040; QFN40P700X700X100-57T310N
X1: 12MHz; 3.2X2.5_OSC

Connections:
!MCU_RST: C27.1, R39.1, S1.3 (2), S1.4 (2), U7.26 (RUN)
!USB_BOOT: R45.1, S2.1, S2.2 (1)
ADC_AVDD: C28.1, R41.1, U7.43 (ADC_AVDD)
ADC_VREF: R37.1, R41.2
GND: C17.2, C18.1, C19.2, C20.2, C21.2, C22.2, C23.2, C24.2, C25.2, C26.1, C27.2, C28.2, C29.2, C30.2, C31.2, C32.2, D3.2, D4.2, D5.2, S1.1, S1.2 (1), S2.3 (2), S2.4 (2), U6.4 (GND), U7.19 (TESTEN), U7.57 (GND); also elsewhere on the board
MCU_1V1: C24.1, C25.1, C26.2, U7.23 (DVDD), U7.45 (VREG_VOUT), U7.50 (DVDD)
MCU_QSPI_SCLK: U6.6 (CLK), U7.52 (QSPI_SCLK)
MCU_QSPI_SD0: U6.5 (DI/IO0), U7.53 (QSPI_SD0)
MCU_QSPI_SD1: U6.2 (DO/IO1), U7.55 (QSPI_SD1)
MCU_QSPI_SD2: U6.3 (!WP!/IO2), U7.54 (QSPI_SD2)
MCU_QSPI_SD3: U6.7 (!HOLD!/IO3), U7.51 (QSPI_SD3)
MCU_QSPI_SS: R44.1, R45.2, U6.1 (!CS), U7.56 (QSPI_SS_N)
MCU_USB_D_N: R43.1, U7.46 (USB_DM)
MCU_USB_D_P: R42.1, U7.47 (USB_DP)
unnamed: R46.1, U7.21 (XOUT)
unnamed: C32.1, R46.2, X1.3
unnamed: C31.1, U7.20 (XIN), X1.1
unnamed: D3.1, R36.2
unnamed: D4.1, R38.2
unnamed: D5.1, R40.2
PIO0/SPI2FLASH_MISO(SPI0): U7.2 (GPIO0); also elsewhere on the board
PIO1/SPI2FLASH_CS(SPI0): U7.3 (GPIO1); also elsewhere on the board
PIO2/SPI2FLASH_SCK(SPI0): U7.4 (GPIO2); also elsewhere on the board
PIO3/SPI2FLASH_MOSI(SPI0): U7.5 (GPIO3); also elsewhere on the board
PIO4/UART1_TX: U7.6 (GPIO4); also elsewhere on the board
PIO5/UART1_RX: U7.7 (GPIO5); also elsewhere on the board
PIO6/I2C1_SDA: U7.8 (GPIO6); also elsewhere on the board
PIO7/I2C1_SCL: U7.9 (GPIO7); also elsewhere on the board
PIO8/SPI_MISO(SPI1)/I2C0_SDA: U7.11 (GPIO8); also elsewhere on the board
PIO9/SPI_NSS(SPI1)/I2C0_SCL: U7.12 (GPIO9); also elsewhere on the board
PIO10/SPI_SCK(SPI1)/I2C1SDA: U7.13 (GPIO10); also elsewhere on the board
PIO11/SPI_MOSI/I2C1SCL: U7.14 (GPIO11); also elsewhere on the board
PIO12/!FPGA_RESET: U7.15 (GPIO12); also elsewhere on the board
PIO13/GPIO2FPGA_0: U7.16 (GPIO13); also elsewhere on the board
PIO14/GPIO2FPGA_1: U7.17 (GPIO14); also elsewhere on the board
PIO15/GPIO2FPGA_2: U7.18 (GPIO15); also elsewhere on the board
PIO16/SPI2FPGA_MISO: U7.27 (GPIO16); also elsewhere on the board
PIO17/SPI2FPGA_CS: U7.28 (GPIO17); also elsewhere on the board
PIO18/SPI2FPGA_SCK: U7.29 (GPIO18); also elsewhere on the board
PIO19/SPI2FPGA_MOSI: U7.30 (GPIO19); also elsewhere on the board
PIO20/GPIO2FPGA_3: U7.31 (GPIO20); also elsewhere on the board
PIO21/!PWR_FPGA_IO_SRAM: U7.32 (GPIO21); also elsewhere on the board
PIO22/LED0: R36.1, U7.34 (GPIO22)
PIO23/PWR_ON_1V8_1V: U7.35 (GPIO23); also elsewhere on the board
PIO24/LED1: R38.1, U7.36 (GPIO24)
PIO25/LED2: R40.1, U7.37 (GPIO25)
PIO26/ADC0: U7.38 (GPIO26_ADC0); also elsewhere on the board
PIO27/ADC1: U7.39 (GPIO27_ADC1); also elsewhere on the board
PIO28/ADC2/UART0_TX: U7.40 (GPIO28_ADC2); also elsewhere on the board
PIO29/ADC3/UART0_RX: U7.41 (GPIO29_ADC3); also elsewhere on the board
SWCLK: U7.24 (SWCLK); also elsewhere on the board
SWDIO: U7.25 (SWDIO); also elsewhere on the board
USB_D_N: R43.2; also elsewhere on the board
USB_D_P: R42.2; also elsewhere on the board
VCC_MCU: C17.1, C18.2, C19.1, C20.1, C21.1, C22.1, C23.1, C29.1, C30.1, R37.2, R39.2, R44.2, U6.8 (VCC), U7.1 (IOVDD), U7.10 (IOVDD), U7.22 (IOVDD), U7.33 (IOVDD), U7.42 (IOVDD), U7.44 (VREG_VIN), U7.48 (USB_VDD), U7.49 (IOVDD); also elsewhere on the board

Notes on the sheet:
If the !CS pin is low during the startup of the MCU, the MCU will enter bootloader.
MCU LEDs
RP2040 MCU
MCU Power Supply Filtering
MCU Reset Circuit
MCU ADC VDD
MCU BOOT and Flash

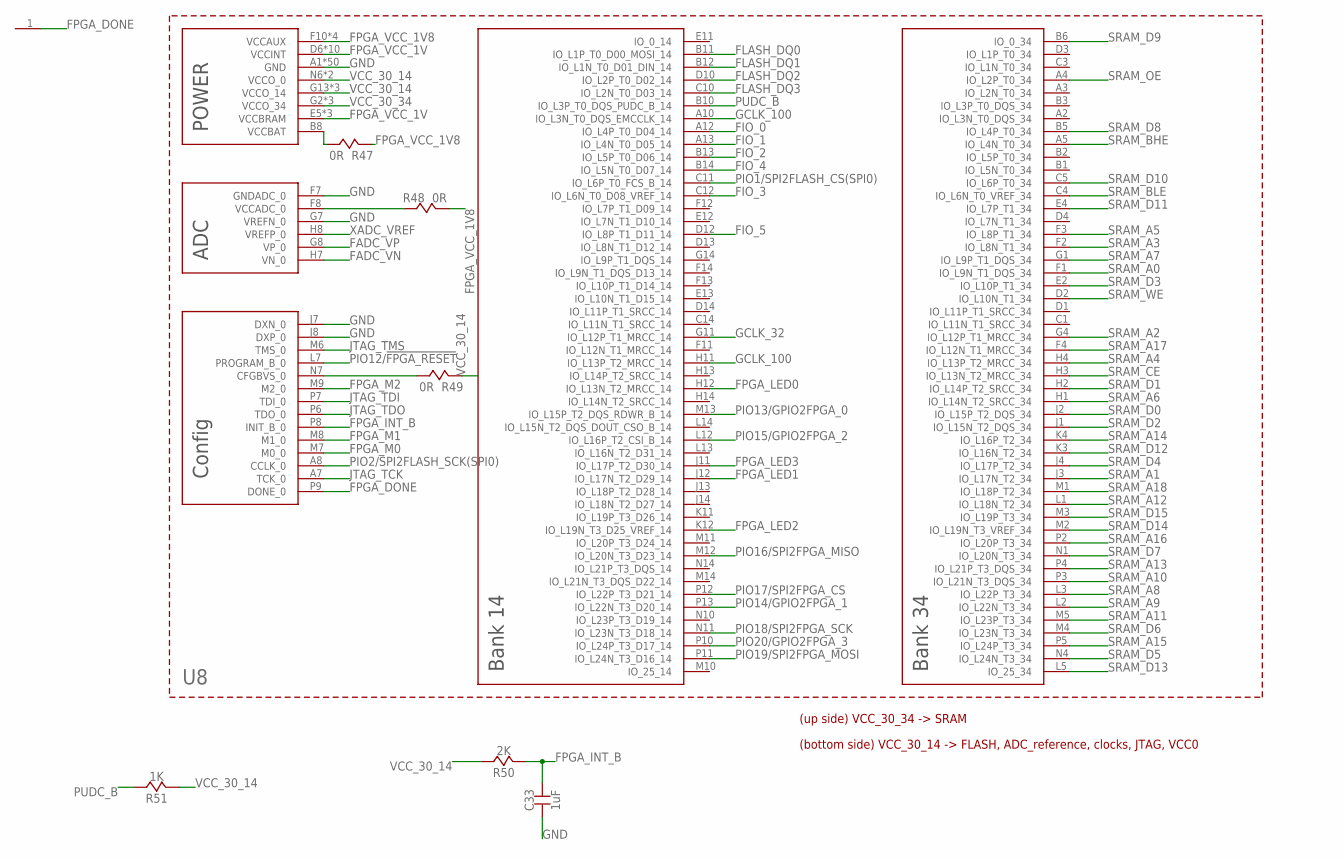
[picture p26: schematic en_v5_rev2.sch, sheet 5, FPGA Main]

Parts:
C33: 1uF; 0402
R47, R48, R49: 0R; 0402
R50: 2K; 0402
R51: 1K; 0402
TP1: TEST_POINTSMD; SMD_PAD
U8: SPARTAN7-LX15; FTGB196

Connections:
FADC_VN: U8.H7 (VN_0); also elsewhere on the board
FADC_VP: U8.G8 (VP_0); also elsewhere on the board
FIO_0: U8.A12 (IO_L4P_T0_D04_14); also elsewhere on the board
FIO_1: U8.A13 (IO_L4N_T0_D05_14); also elsewhere on the board
FIO_2: U8.B13 (IO_L5P_T0_D06_14); also elsewhere on the board
FIO_3: U8.C12 (IO_L6N_T0_D08_VREF_14); also elsewhere on the board
FIO_4: U8.B14 (IO_L5N_T0_D07_14); also elsewhere on the board
FIO_5: U8.D12 (IO_L8P_T1_D11_14); also elsewhere on the board
FLASH_DQ0: U8.B11 (IO_L1P_T0_D00_MOSI_14); also elsewhere on the board
FLASH_DQ1: U8.B12 (IO_L1N_T0_D01_DIN_14); also elsewhere on the board
FLASH_DQ2: U8.D10 (IO_L2P_T0_D02_14); also elsewhere on the board
FLASH_DQ3: U8.C10 (IO_L2N_T0_D03_14); also elsewhere on the board
FPGA_DONE: TP1.1, U8.P9 (DONE_0)
FPGA_INT_B: C33.2, R50.2, U8.P8 (INIT_B_0)
FPGA_LED0: U8.H12 (IO_L13N_T2_MRCC_14); also elsewhere on the board
FPGA_LED1: U8.J12 (IO_L17N_T2_D29_14); also elsewhere on the board
FPGA_LED2: U8.K12 (IO_L19N_T3_D25_VREF_14); also elsewhere on the board
FPGA_LED3: U8.J11 (IO_L17P_T2_D30_14); also elsewhere on the board
FPGA_M0: U8.M7 (M0_0); also elsewhere on the board
FPGA_M1: U8.M8 (M1_0); also elsewhere on the board
FPGA_M2: U8.M9 (M2_0); also elsewhere on the board
FPGA_VCC_1V: U8.D6 (VCCINT), U8.D8 (VCCINT), U8.E5 (VCCBRAM), U8.E7 (VCCINT), U8.E9 (VCCINT), U8.F6 (VCCINT), U8.G5 (VCCBRAM), U8.G9 (VCCINT), U8.H6 (VCCINT), U8.J5 (VCCBRAM), U8.J9 (VCCINT), U8.K6 (VCCINT), U8.K8 (VCCINT); also elsewhere on the board
FPGA_VCC_1V8: R47.2, R48.2, U8.F10 (VCCAUX), U8.H10 (VCCAUX), U8.K10 (VCCAUX), U8.L9 (VCCAUX); also elsewhere on the board
GCLK_32: U8.G11 (IO_L12P_T1_MRCC_14); also elsewhere on the board
GCLK_100: U8.A10 (IO_L3N_T0_DQS_EMCCLK_14), U8.H11 (IO_L13P_T2_MRCC_14); also elsewhere on the board
GND: C33.1, U8.A1 (GND), U8.A6 (GND), U8.A9 (GND), U8.A11 (GND), U8.A14 (GND), U8.B4 (GND), U8.B7 (GND), U8.B9 (GND), U8.C2 (GND), U8.C6 (GND), U8.C7 (GND), U8.C8 (GND), U8.C9 (GND), U8.C13 (GND), U8.D5 (GND), U8.D7 (GND), U8.D9 (GND), U8.D11 (GND), U8.E1 (GND), U8.E3 (GND), U8.E6 (GND), U8.E8 (GND), U8.E10 (GND), U8.E14 (GND), U8.F5 (GND), U8.F7 (GNDADC_0), U8.F9 (GND), U8.G3 (GND), U8.G6 (GND), U8.G7 (VREFN_0), U8.G10 (GND), U8.G12 (GND), U8.H5 (GND), U8.H9 (GND), U8.J6 (GND), U8.J7 (DXN_0), U8.J8 (DXP_0), U8.J10 (GND), U8.K1 (GND), U8.K5 (GND), U8.K7 (GND), U8.K9 (GND), U8.K14 (GND), U8.L4 (GND), U8.L6 (GND), U8.L8 (GND), U8.L10 (GND), U8.L11 (GND), U8.N3 (GND), U8.N5 (GND), U8.N9 (GND), U8.N12 (GND), U8.P1 (GND), U8.P14 (GND); also elsewhere on the board
JTAG_TCK: U8.A7 (TCK_0); also elsewhere on the board
JTAG_TDI: U8.P7 (TDI_0); also elsewhere on the board
JTAG_TDO: U8.P6 (TDO_0); also elsewhere on the board
JTAG_TMS: U8.M6 (TMS_0); also elsewhere on the board
unnamed: R47.1, U8.B8 (VCCBAT)
unnamed: R49.1, U8.N7 (CFGBVS_0)
unnamed: R48.1, U8.F8 (VCCADC_0)
PIO1/SPI2FLASH_CS(SPI0): U8.C11 (IO_L6P_T0_FCS_B_14); also elsewhere on the board
PIO2/SPI2FLASH_SCK(SPI0): U8.A8 (CCLK_0); also elsewhere on the board
PIO12/!FPGA_RESET: U8.L7 (PROGRAM_B_0); also elsewhere on the board
PIO13/GPIO2FPGA_0: U8.M13 (IO_L15P_T2_DQS_RDWR_B_14); also elsewhere on the board
PIO14/GPIO2FPGA_1: U8.P13 (IO_L22N_T3_D20_14); also elsewhere on the board
PIO15/GPIO2FPGA_2: U8.L12 (IO_L16P_T2_CSI_B_14); also elsewhere on the board
PIO16/SPI2FPGA_MISO: U8.M12 (IO_L20N_T3_D23_14); also elsewhere on the board
PIO17/SPI2FPGA_CS: U8.P12 (IO_L22P_T3_D21_14); also elsewhere on the board
PIO18/SPI2FPGA_SCK: U8.N11 (IO_L23N_T3_D18_14); also elsewhere on the board
PIO19/SPI2FPGA_MOSI: U8.P11 (IO_L24N_T3_D16_14); also elsewhere on the board
PIO20/GPIO2FPGA_3: U8.P10 (IO_L24P_T3_D17_14); also elsewhere on the board
PUDC_B: R51.1, U8.B10 (IO_L3P_T0_DQS_PUDC_B_14)
SRAM_A0: U8.F1 (IO_L9N_T1_DQS_34); also elsewhere on the board
SRAM_A1: U8.J3 (IO_L17N_T2_34); also elsewhere on the board
SRAM_A2: U8.G4 (IO_L12P_T1_MRCC_34); also elsewhere on the board
SRAM_A3: U8.F2 (IO_L8N_T1_34); also elsewhere on the board
SRAM_A4: U8.H4 (IO_L13P_T2_MRCC_34); also elsewhere on the board
SRAM_A5: U8.F3 (IO_L8P_T1_34); also elsewhere on the board
SRAM_A6: U8.H1 (IO_L14N_T2_SRCC_34); also elsewhere on the board
SRAM_A7: U8.G1 (IO_L9P_T1_DQS_34); also elsewhere on the board
SRAM_A8: U8.L3 (IO_L22P_T3_34); also elsewhere on the board
SRAM_A9: U8.L2 (IO_L22N_T3_34); also elsewhere on the board
SRAM_A10: U8.P3 (IO_L21N_T3_DQS_34); also elsewhere on the board
SRAM_A11: U8.M5 (IO_L23P_T3_34); also elsewhere on the board
SRAM_A12: U8.L1 (IO_L18N_T2_34); also elsewhere on the board
SRAM_A13: U8.P4 (IO_L21P_T3_DQS_34); also elsewhere on the board
SRAM_A14: U8.K4 (IO_L16P_T2_34); also elsewhere on the board
SRAM_A15: U8.P5 (IO_L24P_T3_34); also elsewhere on the board
SRAM_A16: U8.P2 (IO_L20P_T3_34); also elsewhere on the board
SRAM_A17: U8.F4 (IO_L12N_T1_MRCC_34); also elsewhere on the board
SRAM_A18: U8.M1 (IO_L18P_T2_34); also elsewhere on the board
SRAM_BHE: U8.A5 (IO_L4N_T0_34); also elsewhere on the board
SRAM_BLE: U8.C4 (IO_L6N_T0_VREF_34); also elsewhere on the board
SRAM_CE: U8.H3 (IO_L13N_T2_MRCC_34); also elsewhere on the board
SRAM_D0: U8.J2 (IO_L15P_T2_DQS_34); also elsewhere on the board
SRAM_D1: U8.H2 (IO_L14P_T2_SRCC_34); also elsewhere on the board
SRAM_D2: U8.J1 (IO_L15N_T2_DQS_34); also elsewhere on the board
SRAM_D3: U8.E2 (IO_L10P_T1_34); also elsewhere on the board
SRAM_D4: U8.J4 (IO_L17P_T2_34); also elsewhere on the board
SRAM_D5: U8.N4 (IO_L24N_T3_34); also elsewhere on the board
SRAM_D6: U8.M4 (IO_L23N_T3_34); also elsewhere on the board
SRAM_D7: U8.N1 (IO_L20N_T3_34); also elsewhere on the board
SRAM_D8: U8.B5 (IO_L4P_T0_34); also elsewhere on the board
SRAM_D9: U8.B6 (IO_0_34); also elsewhere on the board
SRAM_D10: U8.C5 (IO_L6P_T0_34); also elsewhere on the board
SRAM_D11: U8.E4 (IO_L7P_T1_34); also elsewhere on the board
SRAM_D12: U8.K3 (IO_L16N_T2_34); also elsewhere on the board
SRAM_D13: U8.L5 (IO_25_34); also elsewhere on the board
SRAM_D14: U8.M2 (IO_L19N_T3_VREF_34); also elsewhere on the board
SRAM_D15: U8.M3 (IO_L19P_T3_34); also elsewhere on the board
SRAM_OE: U8.A4 (IO_L2P_T0_34); also elsewhere on the board
SRAM_WE: U8.D2 (IO_L10N_T1_34); also elsewhere on the board
VCC_30_14: R49.2, R50.1, R51.2, U8.G13 (VCCO_14), U8.K13 (VCCO_14), U8.N6 (VCCO_0), U8.N8 (VCCO_0), U8.N13 (VCCO_14); also elsewhere on the board
VCC_30_34: U8.G2 (VCCO_34), U8.K2 (VCCO_34), U8.N2 (VCCO_34); also elsewhere on the board
XADC_VREF: U8.H8 (VREFP_0); also elsewhere on the board

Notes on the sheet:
(up side) VCC_30_34 -> SRAM
(bottom side) VCC_30_14 -> FLASH, ADC_reference, clocks, JTAG, VCC0

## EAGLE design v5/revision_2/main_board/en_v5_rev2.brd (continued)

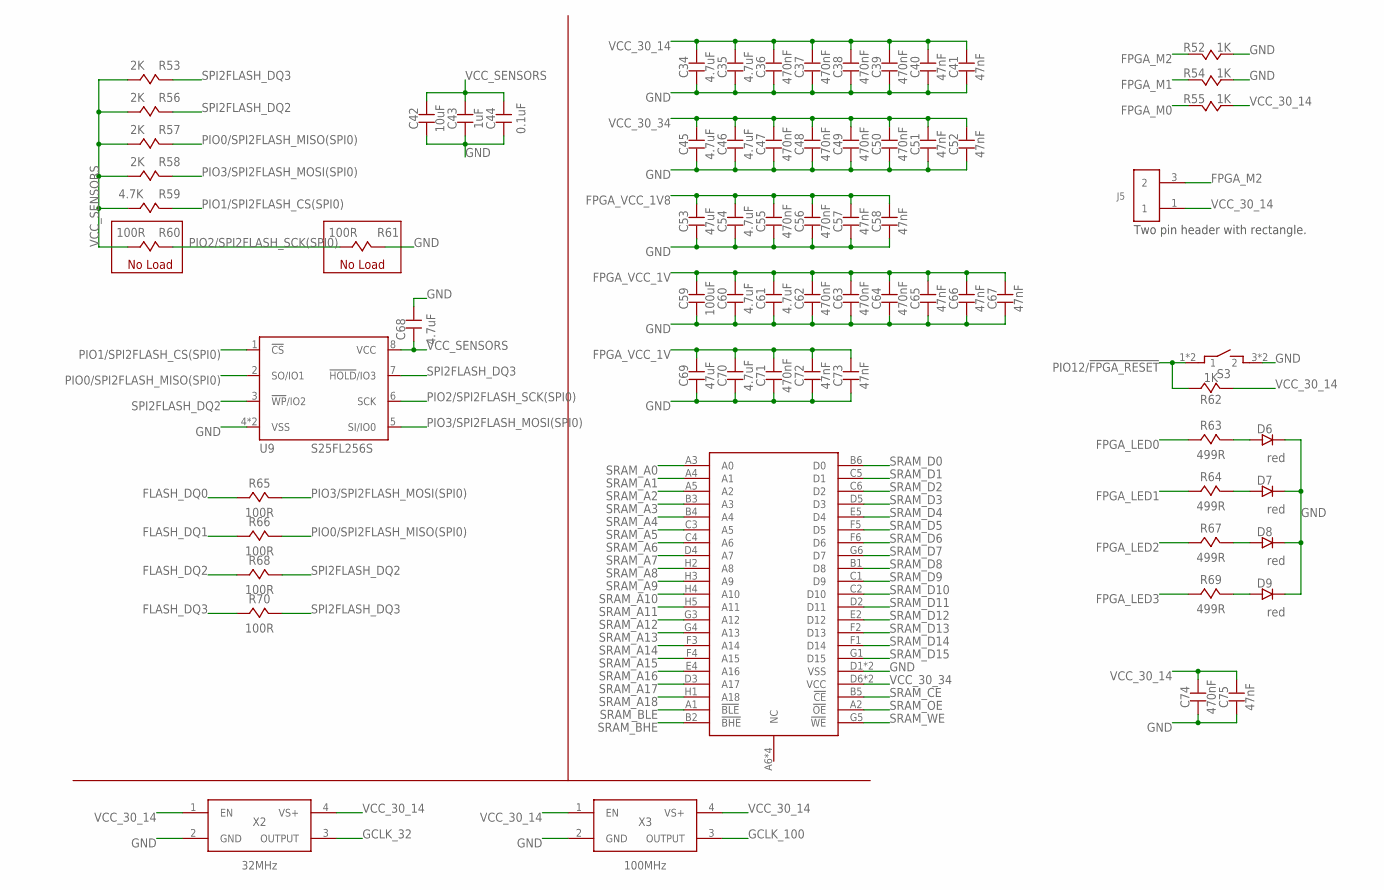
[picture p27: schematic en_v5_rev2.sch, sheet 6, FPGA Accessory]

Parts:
C34, C35, C45, C46, C54, C60, C61, C68, C70: 4.7uF; CAPC1608-0603
C36, C37, C38, C39, C47, C48, C49, C50, C55, C56, C62, C63, C64, C71, C74: 470nF; 0402
C40, C41, C51, C52, C57, C58, C65, C66, C67, C72, C73, C75: 47nF; 0402
C42: 10uF; CAPC1608-0603
C43: 1uF; 0402
C44: 0.1uF; 0402
C53, C69: 47uF; 0805
C59: 100uF; 0805
D6, D7, D8, D9: red; 0402
J5: FEMALE_HEADER_2X1; 2X1_HEADER
R52, R54, R55, R62: 1K; 0402
R53, R56, R57, R58: 2K; 0402
R59: 4.7K; 0402
R60, R61, R65, R66, R68, R70: 100R; 0402
R63, R64, R67, R69: 499R; 0402
S3: TACTILE-SWITCH
U9: S25FL256S; WSON6X8MM
U10: CY7C1051DV33; BGA-48
X2: 32MHz; 3.2X2.5_OSC
X3: 100MHz; 3.2X2.5_OSC

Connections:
FLASH_DQ0: R65.1; also elsewhere on the board
FLASH_DQ1: R66.1; also elsewhere on the board
FLASH_DQ2: R68.1; also elsewhere on the board
FLASH_DQ3: R70.1; also elsewhere on the board
FPGA_LED0: R63.1; also elsewhere on the board
FPGA_LED1: R64.1; also elsewhere on the board
FPGA_LED2: R67.1; also elsewhere on the board
FPGA_LED3: R69.1; also elsewhere on the board
FPGA_M0: R55.2; also elsewhere on the board
FPGA_M1: R54.2; also elsewhere on the board
FPGA_M2: J5.3 (2), R52.2; also elsewhere on the board
FPGA_VCC_1V: C59.2, C60.2, C61.2, C62.2, C63.2, C64.2, C65.2, C66.2, C67.2, C69.2, C70.2, C71.2, C72.2, C73.2; also elsewhere on the board
FPGA_VCC_1V8: C53.2, C54.2, C55.2, C56.2, C57.2, C58.2; also elsewhere on the board
GCLK_32: X2.3 (OUTPUT); also elsewhere on the board
GCLK_100: X3.3 (OUTPUT); also elsewhere on the board
GND: C34.1, C35.1, C36.1, C37.1, C38.1, C39.1, C40.1, C41.1, C42.1, C43.1, C44.1, C45.1, C46.1, C47.1, C48.1, C49.1, C50.1, C51.1, C52.1, C53.1, C54.1, C55.1, C56.1, C57.1, C58.1, C59.1, C60.1, C61.1, C62.1, C63.1, C64.1, C65.1, C66.1, C67.1, C68.2, C69.1, C70.1, C71.1, C72.1, C73.1, C74.1, C75.1, D6.2, D7.2, D8.2, D9.2, R52.1, R54.1, R61.2, S3.3 (2), S3.4 (2), U9.4 (VSS), U9.9 (VSS), U10.D1 (VSS), U10.E6 (VSS), X2.2 (GND), X3.2 (GND); also elsewhere on the board
unnamed: D6.1, R63.2
unnamed: D7.1, R64.2
unnamed: D8.1, R67.2
unnamed: D9.1, R69.2
PIO0/SPI2FLASH_MISO(SPI0): R57.2, R66.2, U9.2 (SO/IO1); also elsewhere on the board
PIO1/SPI2FLASH_CS(SPI0): R59.2, U9.1 (!CS); also elsewhere on the board
PIO2/SPI2FLASH_SCK(SPI0): R60.2, R61.1, U9.6 (SCK); also elsewhere on the board
PIO3/SPI2FLASH_MOSI(SPI0): R58.2, R65.2, U9.5 (SI/IO0); also elsewhere on the board
PIO12/!FPGA_RESET: R62.1, S3.1, S3.2 (1); also elsewhere on the board
SPI2FLASH_DQ2: R56.2, R68.2, U9.3 (!WP!/IO2)
SPI2FLASH_DQ3: R53.2, R70.2, U9.7 (!HOLD!/IO3)
SRAM_A0: U10.A3 (A0); also elsewhere on the board
SRAM_A1: U10.A4 (A1); also elsewhere on the board
SRAM_A2: U10.A5 (A2); also elsewhere on the board
SRAM_A3: U10.B3 (A3); also elsewhere on the board
SRAM_A4: U10.B4 (A4); also elsewhere on the board
SRAM_A5: U10.C3 (A5); also elsewhere on the board
SRAM_A6: U10.C4 (A6); also elsewhere on the board
SRAM_A7: U10.D4 (A7); also elsewhere on the board
SRAM_A8: U10.H2 (A8); also elsewhere on the board
SRAM_A9: U10.H3 (A9); also elsewhere on the board
SRAM_A10: U10.H4 (A10); also elsewhere on the board
SRAM_A11: U10.H5 (A11); also elsewhere on the board
SRAM_A12: U10.G3 (A12); also elsewhere on the board
SRAM_A13: U10.G4 (A13); also elsewhere on the board
SRAM_A14: U10.F3 (A14); also elsewhere on the board
SRAM_A15: U10.F4 (A15); also elsewhere on the board
SRAM_A16: U10.E4 (A16); also elsewhere on the board
SRAM_A17: U10.D3 (A17); also elsewhere on the board
SRAM_A18: U10.H1 (A18); also elsewhere on the board
SRAM_BHE: U10.B2 (!BHE); also elsewhere on the board
SRAM_BLE: U10.A1 (!BLE); also elsewhere on the board
SRAM_CE: U10.B5 (!CE); also elsewhere on the board
SRAM_D0: U10.B6 (D0); also elsewhere on the board
SRAM_D1: U10.C5 (D1); also elsewhere on the board
SRAM_D2: U10.C6 (D2); also elsewhere on the board
SRAM_D3: U10.D5 (D3); also elsewhere on the board
SRAM_D4: U10.E5 (D4); also elsewhere on the board
SRAM_D5: U10.F5 (D5); also elsewhere on the board
SRAM_D6: U10.F6 (D6); also elsewhere on the board
SRAM_D7: U10.G6 (D7); also elsewhere on the board
SRAM_D8: U10.B1 (D8); also elsewhere on the board
SRAM_D9: U10.C1 (D9); also elsewhere on the board
SRAM_D10: U10.C2 (D10); also elsewhere on the board
SRAM_D11: U10.D2 (D11); also elsewhere on the board
SRAM_D12: U10.E2 (D12); also elsewhere on the board
SRAM_D13: U10.F2 (D13); also elsewhere on the board
SRAM_D14: U10.F1 (D14); also elsewhere on the board
SRAM_D15: U10.G1 (D15); also elsewhere on the board
SRAM_OE: U10.A2 (!OE); also elsewhere on the board
SRAM_WE: U10.G5 (!WE); also elsewhere on the board
VCC_30_14: C34.2, C35.2, C36.2, C37.2, C38.2, C39.2, C40.2, C41.2, C74.2, C75.2, J5.1, R55.1, R62.2, X2.1 (EN), X2.4 (VS+), X3.1 (EN), X3.4 (VS+); also elsewhere on the board
VCC_30_34: C45.2, C46.2, C47.2, C48.2, C49.2, C50.2, C51.2, C52.2, U10.D6 (VCC), U10.E1 (VCC); also elsewhere on the board
VCC_SENSORS: C42.2, C43.2, C44.2, C68.1, R53.1, R56.1, R57.1, R58.1, R59.1, R60.1, U9.8 (VCC); also elsewhere on the board

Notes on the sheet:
No Load
Two pin header with rectangle.

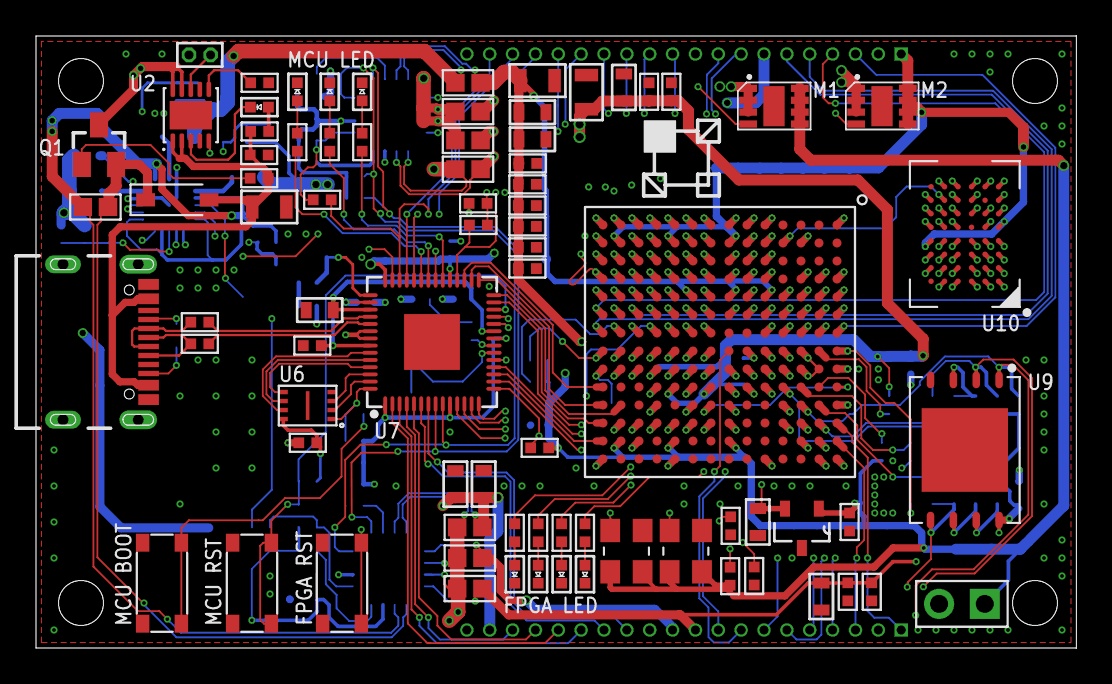
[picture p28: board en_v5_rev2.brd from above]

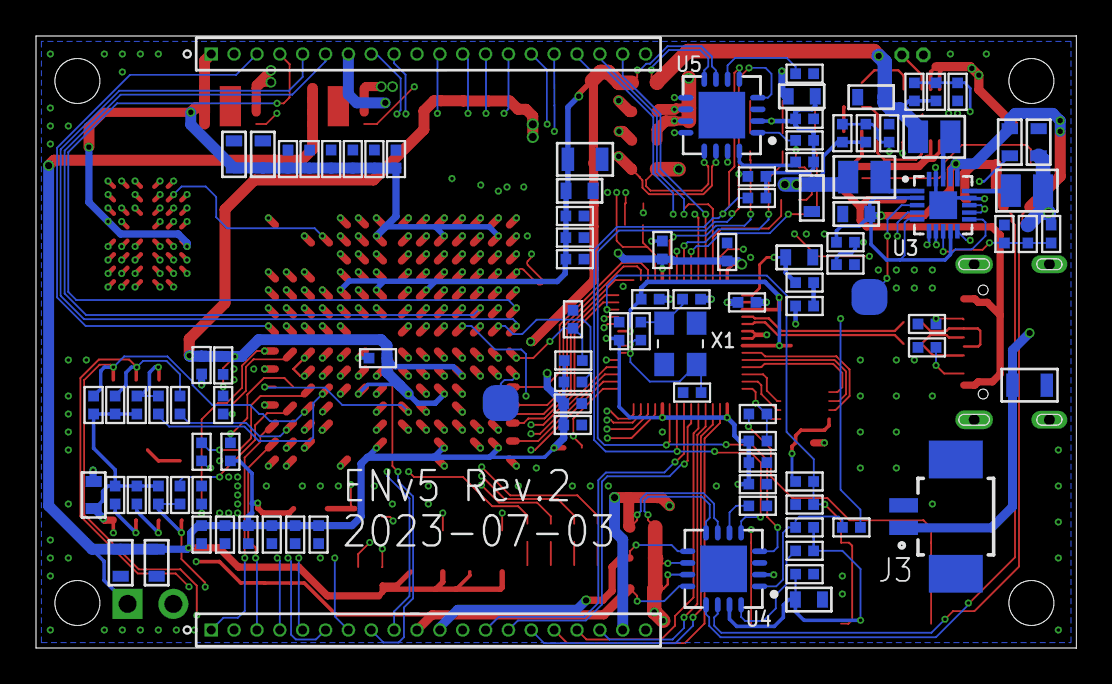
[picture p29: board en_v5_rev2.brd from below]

Board: 4 copper layers, 57.8 x 34.0 mm, 183 parts (104 on the bottom side), 170 nets.

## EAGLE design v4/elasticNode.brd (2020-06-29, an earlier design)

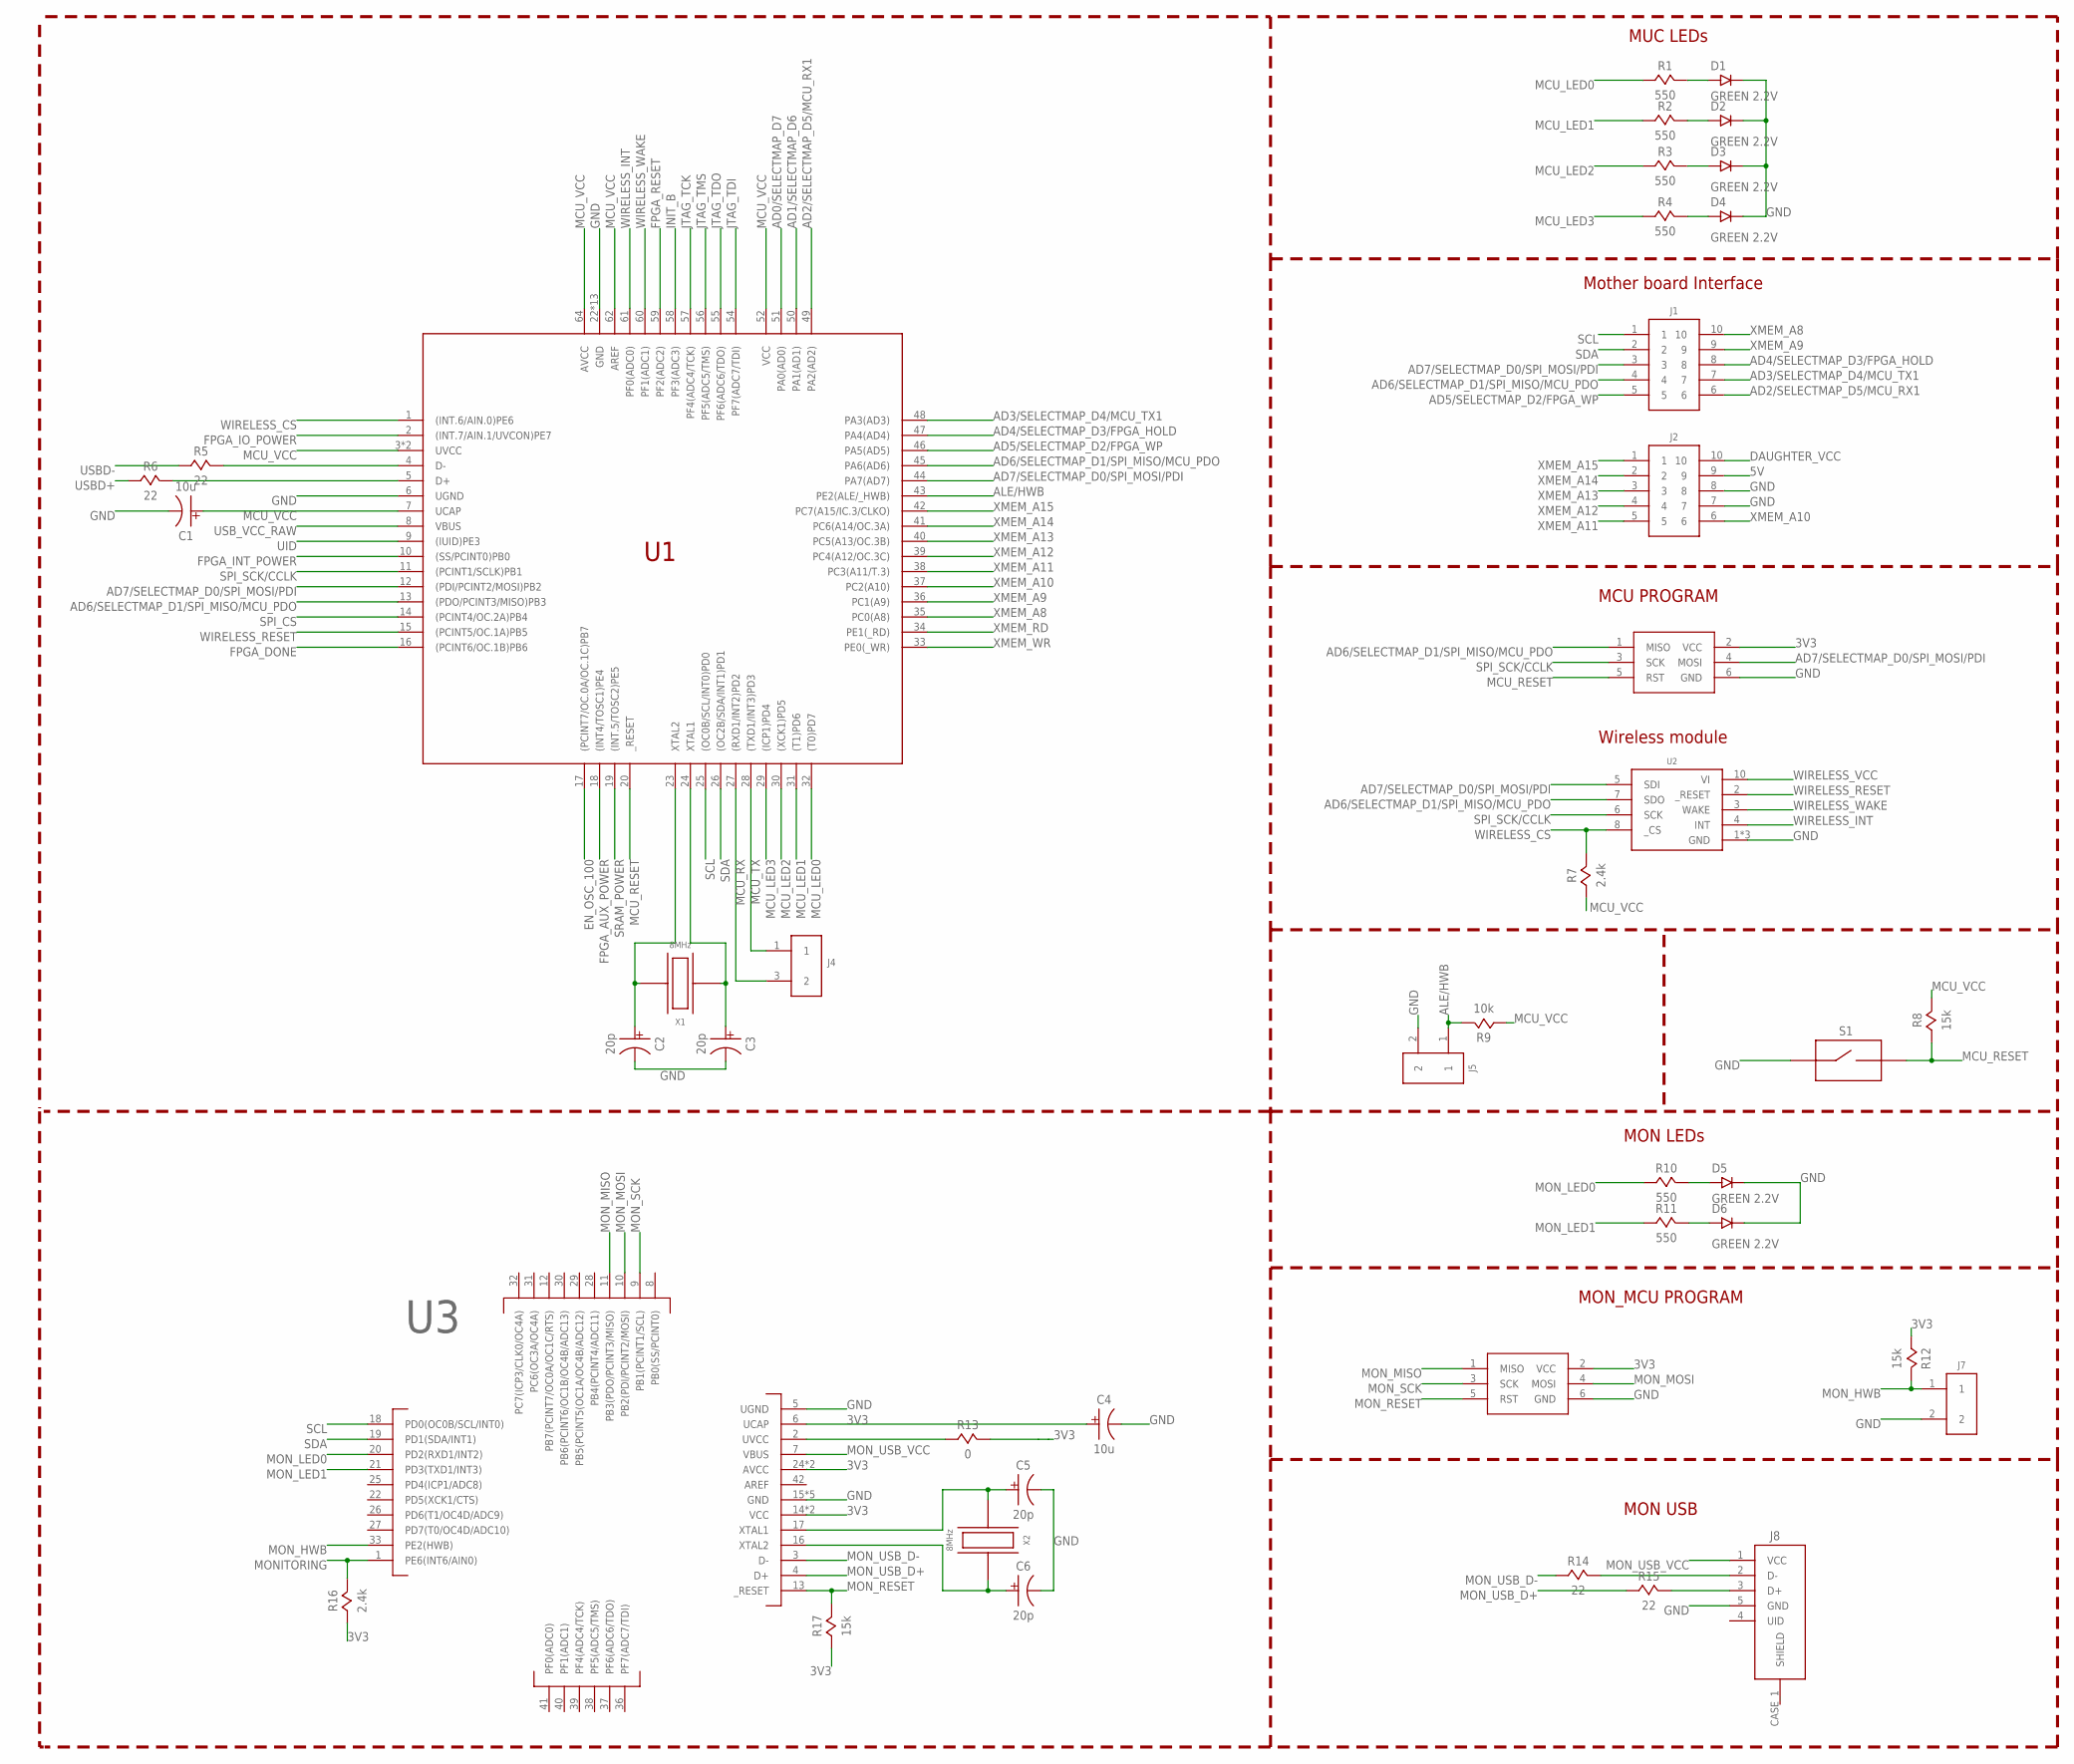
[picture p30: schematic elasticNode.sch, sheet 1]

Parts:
C1, C4: 10u; 0805
C2, C3, C5, C6: 20p; 0805
D1, D2, D3, D4, D5, D6: GREEN 2.2V; 0805
J1, J2: FEMALE_HEADER_5X2; 5X2_HEADER_SMT_1.27
J3, J6: ISP_CONN_6PIN; ICSP_SMT
J4: FEMALE_HEADER_2X1; 2X1_HEADER
J5, J7: JUMPER; JUMPER_SMT
J8: USB_CONNMICRO_SMT; USB_MICRO_B_SMT
R1, R2, R3, R4, R10, R11: 550; 0805
R5, R6, R14, R15: 22; 0805
R7, R16: 2.4k; 0805
R8, R12, R17: 15k; 0805
R9: 10k; 0805
R13: 0; 0805
S1: SPST_BUTTON2PIN_SMT; SPST_2PIN_SMT
U1: AT90USB128; QFN64
U2: MRF24J40MA
U3: ATMEGA32U4QFN; QFN44
X1, X2: 8MHz; 3.2X2.5_OSC

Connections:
3V3: C4.1, J3.2 (VCC), J6.2 (VCC), R12.1, R13.2, R16.1, R17.1, U3.6 (UCAP), U3.14 (VCC), U3.24 (AVCC), U3.34 (VCC), U3.44 (AVCC); also elsewhere on the board
5V: J2.9; also elsewhere on the board
AD0/SELECTMAP_D7: U1.51 (PA0(AD0)); also elsewhere on the board
AD1/SELECTMAP_D6: U1.50 (PA1(AD1)); also elsewhere on the board
AD2/SELECTMAP_D5/MCU_RX1: J1.6, U1.49 (PA2(AD2)); also elsewhere on the board
AD3/SELECTMAP_D4/MCU_TX1: J1.7, U1.48 (PA3(AD3)); also elsewhere on the board
AD4/SELECTMAP_D3/FPGA_HOLD: J1.8, U1.47 (PA4(AD4)); also elsewhere on the board
AD5/SELECTMAP_D2/FPGA_WP: J1.5, U1.46 (PA5(AD5)); also elsewhere on the board
AD6/SELECTMAP_D1/SPI_MISO/MCU_PDO: J1.4, J3.1 (MISO), U1.13 ((PDO/PCINT3/MISO)PB3), U1.45 (PA6(AD6)), U2.7 (SDO); also elsewhere on the board
AD7/SELECTMAP_D0/SPI_MOSI/PDI: J1.3, J3.4 (MOSI), U1.12 ((PDI/PCINT2/MOSI)PB2), U1.44 (PA7(AD7)), U2.5 (SDI); also elsewhere on the board
ALE/HWB: J5.1, R9.2, U1.43 (PE2(ALE/_HWB)); also elsewhere on the board
DAUGHTER_VCC: J2.10; also elsewhere on the board
EN_OSC_100: U1.17 ((PCINT7/OC.0A/OC.1C)PB7); also elsewhere on the board
FPGA_AUX_POWER: U1.18 ((INT4/TOSC1)PE4); also elsewhere on the board
FPGA_DONE: U1.16 ((PCINT6/OC.1B)PB6); also elsewhere on the board
FPGA_INT_POWER: U1.10 ((SS/PCINT0)PB0); also elsewhere on the board
FPGA_IO_POWER: U1.2 ((INT.7/AIN.1/UVCON)PE7); also elsewhere on the board
FPGA_RESET: U1.59 (PF2(ADC2)); also elsewhere on the board
GND: C1.2, C2.2, C3.2, C4.2, C5.2, C6.2, D1.2, D2.2, D3.2, D4.2, D5.2, D6.2, J2.7, J2.8, J3.6 (GND), J5.2, J6.6 (GND), J7.2, J8.5 (GND), S1.1, U1.6 (UGND), U1.22 (GND), U1.53 (GND), U1.63 (GND), U1.PAD (GND), U1.VIA1 (GND), U1.VIA2 (GND), U1.VIA3 (GND), U1.VIA4 (GND), U1.VIA5 (GND), U1.VIA6 (GND), U1.VIA7 (GND), U1.VIA8 (GND), U1.VIA9 (GND), U2.1 (GND), U2.11 (GND), U2.12 (GND), U3.5 (UGND), U3.15 (GND), U3.23 (GND), U3.35 (GND), U3.43 (GND), U3.45 (GND); also elsewhere on the board
INIT_B: U1.58 (PF3(ADC3)); also elsewhere on the board
JTAG_TCK: U1.57 (PF4(ADC4/TCK)); also elsewhere on the board
JTAG_TDI: U1.54 (PF7(ADC7/TDI)); also elsewhere on the board
JTAG_TDO: U1.55 (PF6(ADC6/TDO)); also elsewhere on the board
JTAG_TMS: U1.56 (PF5(ADC5/TMS)); also elsewhere on the board
MCU_LED0: R1.1, U1.32 ((T0)PD7)
MCU_LED1: R2.1, U1.31 ((T1)PD6)
MCU_LED2: R3.1, U1.30 ((XCK1)PD5)
MCU_LED3: R4.1, U1.29 ((ICP1)PD4)
MCU_RESET: J3.5 (RST), R8.1, S1.2 (3), U1.20 (_RESET)
MCU_RX: J4.3 (2), U1.27 ((RXD1/INT2)PD2)
MCU_TX: J4.1, U1.28 ((TXD1/INT3)PD3)
MCU_VCC: C1.1, R7.1, R8.2, R9.1, U1.3 (UVCC), U1.7 (UCAP), U1.21 (UVCC), U1.52 (VCC), U1.62 (AREF), U1.64 (AVCC); also elsewhere on the board
MONITORING: R16.2, U3.1 (PE6(INT6/AIN0)); also elsewhere on the board
MON_HWB: J7.1, R12.2, U3.33 (PE2(HWB))
MON_LED0: R10.1, U3.20 (PD2(RXD1/INT2))
MON_LED1: R11.1, U3.21 (PD3(TXD1/INT3))
MON_MISO: J6.1 (MISO), U3.11 (PB3(PDO/PCINT3/MISO))
MON_MOSI: J6.4 (MOSI), U3.10 (PB2(PDI/PCINT2/MOSI))
MON_RESET: J6.5 (RST), R17.2, U3.13 (_RESET)
MON_SCK: J6.3 (SCK), U3.9 (PB1(PCINT1/SCL))
MON_USB_D+: R15.1, U3.4 (D+)
MON_USB_D-: R14.1, U3.3 (D-)
MON_USB_VCC: J8.1 (VCC), U3.7 (VBUS)
unnamed: R5.2, U1.4 (D-)
unnamed: C2.1, U1.23 (XTAL2), X1.1
unnamed: J8.3 (D+), R15.2
unnamed: C3.1, U1.24 (XTAL1), X1.3
unnamed: R6.2, U1.5 (D+)
unnamed: D4.1, R4.2
unnamed: D3.1, R3.2
unnamed: D6.1, R11.2
unnamed: D5.1, R10.2
unnamed: C5.1, U3.17 (XTAL1), X2.3
unnamed: J8.2 (D-), R14.2
unnamed: C6.1, U3.16 (XTAL2), X2.1
unnamed: R13.1, U3.2 (UVCC)
unnamed: D2.1, R2.2
unnamed: D1.1, R1.2
SCL: J1.1, U1.25 ((OC0B/SCL/INT0)PD0), U3.18 (PD0(OC0B/SCL/INT0)); also elsewhere on the board
SDA: J1.2, U1.26 ((OC2B/SDA/INT1)PD1), U3.19 (PD1(SDA/INT1)); also elsewhere on the board
SPI_CS: U1.14 ((PCINT4/OC.2A)PB4); also elsewhere on the board
SPI_SCK/CCLK: J3.3 (SCK), U1.11 ((PCINT1/SCLK)PB1), U2.6 (SCK); also elsewhere on the board
SRAM_POWER: U1.19 ((INT.5/TOSC2)PE5); also elsewhere on the board
UID: U1.9 ((IUID)PE3); also elsewhere on the board
USBD+: R6.1; also elsewhere on the board
USBD-: R5.1; also elsewhere on the board
USB_VCC_RAW: U1.8 (VBUS); also elsewhere on the board
WIRELESS_CS: R7.2, U1.1 ((INT.6/AIN.0)PE6), U2.8 (_CS)
WIRELESS_INT: U1.61 (PF0(ADC0)), U2.4 (INT)
WIRELESS_RESET: U1.15 ((PCINT5/OC.1A)PB5), U2.2 (_RESET)
WIRELESS_VCC: U2.10 (VI); also elsewhere on the board
WIRELESS_WAKE: U1.60 (PF1(ADC1)), U2.3 (WAKE)
XMEM_A8: J1.10, U1.35 (PC0(A8)); also elsewhere on the board
XMEM_A9: J1.9, U1.36 (PC1(A9)); also elsewhere on the board
XMEM_A10: J2.6, U1.37 (PC2(A10)); also elsewhere on the board
XMEM_A11: J2.5, U1.38 (PC3(A11/T.3)); also elsewhere on the board
XMEM_A12: J2.4, U1.39 (PC4(A12/OC.3C)); also elsewhere on the board
XMEM_A13: J2.3, U1.40 (PC5(A13/OC.3B)); also elsewhere on the board
XMEM_A14: J2.2, U1.41 (PC6(A14/OC.3A)); also elsewhere on the board
XMEM_A15: J2.1, U1.42 (PC7(A15/IC.3/CLKO)); also elsewhere on the board
XMEM_RD: U1.34 (PE1(_RD)); also elsewhere on the board
XMEM_WR: U1.33 (PE0(_WR)); also elsewhere on the board

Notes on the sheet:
MUC LEDs
Mother board Interface
MCU PROGRAM
Wireless module
MON LEDs
MON_MCU PROGRAM
MON USB


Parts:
C7, C17, C24: 100u; 1210
C8, C9, C13, C18, C19, C20, C25, C26, C27: 4.7u; 0805
C10, C11, C14, C15, C16, C21, C22, C23, C28, C29, C30: 0.47u; 0805
C12: 47u; 1210
D7: RED 1.8V 2mA; 0805
D8, D9, D10: RED; 0805
J9: JTAG_CONN_6PINSMT; 6X1_JTAG
J10: FEMALE_HEADER_10X2; 10X2_HEADER_SMT
M1, M2, M3, M4: SISS23DN; POWERPAK1212-8
R18, R19, R20, R22: 750; 0805
R21: 4.7k; 0805
R23, R28: 15k; 0805
R24, R25, R26, R27: 2.4k; 0805
S2: SPST_DIP_4; SPST_DIP4_SMT
S3: SPST_BUTTON2PIN_SMT; SPST_2PIN_SMT
U4: IS66WV51216EALL; TSOP44
U5: SPARTAN7-LX15; FTGB196
U6: SST26VF032BWDFN; WDFN8
X3: 100MHz; 3.2X2.5_OSC
X4: 50MHz; 3.2X2.5_OSC
X5: 32MHz; 3.2X2.5_OSC

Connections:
3V3: R27.1, U6.3 (WP), U6.7 (HOLD), U6.8 (VDD); also elsewhere on the board
AD0/SELECTMAP_D7: U5.B14 (IO_L5N_T0_D07_14); also elsewhere on the board
AD1/SELECTMAP_D6: U5.B13 (IO_L5P_T0_D06_14); also elsewhere on the board
AD2/SELECTMAP_D5/MCU_RX1: U5.A13 (IO_L4N_T0_D05_14); also elsewhere on the board
AD3/SELECTMAP_D4/MCU_TX1: U5.A12 (IO_L4P_T0_D04_14); also elsewhere on the board
AD4/SELECTMAP_D3/FPGA_HOLD: U5.C10 (IO_L2N_T0_D03_14); also elsewhere on the board
AD5/SELECTMAP_D2/FPGA_WP: U5.D10 (IO_L2P_T0_D02_14); also elsewhere on the board
AD6/SELECTMAP_D1/SPI_MISO/MCU_PDO: U5.B12 (IO_L1N_T0_D01_DIN_14), U6.2 (SO); also elsewhere on the board
AD7/SELECTMAP_D0/SPI_MOSI/PDI: U5.B11 (IO_L1P_T0_D00_MOSI_14), U6.5 (SI); also elsewhere on the board
ALE/HWB: U5.G11 (IO_L12P_T1_MRCC_14); also elsewhere on the board
EN_OSC_100: R23.1, X3.1 (EN); also elsewhere on the board
FPGA_AUX_POWER: M2.4 (G); also elsewhere on the board
FPGA_DONE: U5.P9 (DONE_0); also elsewhere on the board
FPGA_GPIO_0: J10.1, U5.H14 (IO_L14N_T2_SRCC_14)
FPGA_GPIO_1: J10.20, U5.H12 (IO_L13N_T2_MRCC_14)
FPGA_GPIO_2: J10.2, U5.H13 (IO_L14P_T2_SRCC_14)
FPGA_GPIO_3: J10.19, U5.J13 (IO_L18P_T2_D28_14)
FPGA_GPIO_4: J10.3, U5.J14 (IO_L18N_T2_D27_14)
FPGA_GPIO_5: J10.18, U5.J12 (IO_L17N_T2_D29_14)
FPGA_GPIO_6: J10.4, U5.J11 (IO_L17P_T2_D30_14)
FPGA_GPIO_7: J10.17, U5.K12 (IO_L19N_T3_D25_VREF_14)
FPGA_GPIO_8: J10.5, U5.L14 (IO_L15N_T2_DQS_DOUT_CSO_B_14)
FPGA_GPIO_9: J10.16, U5.L13 (IO_L16N_T2_D31_14)
FPGA_GPIO_10: J10.15, U5.N14 (IO_L21P_T3_DQS_14)
FPGA_GPIO_11: J10.6, U5.M14 (IO_L21N_T3_DQS_D22_14)
FPGA_GPIO_12: J10.14, U5.K11 (IO_L19P_T3_D26_14)
FPGA_GPIO_13: J10.7, U5.P13 (IO_L22N_T3_D20_14)
FPGA_GPIO_14: J10.8, U5.M12 (IO_L20N_T3_D23_14)
FPGA_GPIO_15: J10.13, U5.P12 (IO_L22P_T3_D21_14)
FPGA_GPIO_16: J10.9, U5.N11 (IO_L23N_T3_D18_14)
FPGA_GPIO_17: J10.12, U5.P11 (IO_L24N_T3_D16_14)
FPGA_GPIO_18: J10.10, U5.N10 (IO_L23P_T3_D19_14)
FPGA_GPIO_19: J10.11, U5.P10 (IO_L24P_T3_D17_14)
FPGA_INT_POWER: M1.4 (G); also elsewhere on the board
FPGA_IO_POWER: M3.4 (G); also elsewhere on the board
FPGA_LED0: R18.1, U5.E11 (IO_0_14)
FPGA_LED1: R19.1, U5.B10 (IO_L3P_T0_DQS_PUDC_B_14)
FPGA_LED2: R20.1, U5.C12 (IO_L6N_T0_D08_VREF_14)
FPGA_LED3: R22.1, U5.M11 (IO_L20P_T3_D24_14)
FPGA_RESET: R28.1, S3.2 (3), U5.L7 (PROGRAM_B_0); also elsewhere on the board
FPGA_VCCAUX: C12.1, C13.1, C14.1, C15.1, C16.1, M2.5 (D), M2.6 (D), M2.7 (D), M2.8 (D), U5.F10 (VCCAUX), U5.H10 (VCCAUX), U5.K10 (VCCAUX), U5.L9 (VCCAUX), U5.N7 (CFGBVS_0)
FPGA_VCCAUX_MON: M2.1 (S), M2.2 (S), M2.3 (S); also elsewhere on the board
FPGA_VCCINT: C7.1, C8.1, C9.1, C10.1, C11.1, M1.5 (D), M1.6 (D), M1.7 (D), M1.8 (D), U5.D6 (VCCINT), U5.D8 (VCCINT), U5.E5 (VCCBRAM), U5.E7 (VCCINT), U5.E9 (VCCINT), U5.F6 (VCCINT), U5.G5 (VCCBRAM), U5.G9 (VCCINT), U5.H6 (VCCINT), U5.J5 (VCCBRAM), U5.J9 (VCCINT), U5.K6 (VCCINT), U5.K8 (VCCINT)
FPGA_VCCINT_MON: M1.1 (S), M1.2 (S), M1.3 (S); also elsewhere on the board
FPGA_VCCIO: C17.1, C18.1, C19.1, C20.1, C21.1, C22.1, C23.1, J9.1 (REF), M3.5 (D), M3.6 (D), M3.7 (D), M3.8 (D), R21.2, R23.2, R24.1, R25.1, R26.1, R28.2, U5.G13 (VCCO_14), U5.K13 (VCCO_14), U5.N6 (VCCO_0), U5.N8 (VCCO_0), U5.N13 (VCCO_14), X3.4 (VS+), X4.1 (EN), X4.4 (VS+), X5.1 (EN), X5.4 (VS+)
FPGA_VCCIO_MON: M3.1 (S), M3.2 (S), M3.3 (S); also elsewhere on the board
GND: C7.2, C8.2, C9.2, C10.2, C11.2, C12.2, C13.2, C14.2, C15.2, C16.2, C17.2, C18.2, C19.2, C20.2, C21.2, C22.2, C23.2, C24.2, C25.2, C26.2, C27.2, C28.2, C29.2, C30.2, D7.2, D8.2, D9.2, D10.2, J9.2 (GND), S2.5 (4Y), S2.6 (3Y), S2.7 (2Y), S2.8 (1Y), S3.1, U4.12 (GND), U4.34 (GND), U5.A1 (GND), U5.A6 (GND), U5.A9 (GND), U5.A11 (GND), U5.A14 (GND), U5.B4 (GND), U5.B7 (GND), U5.B9 (GND), U5.C2 (GND), U5.C6 (GND), U5.C7 (GND), U5.C8 (GND), U5.C9 (GND), U5.C13 (GND), U5.D5 (GND), U5.D7 (GND), U5.D9 (GND), U5.D11 (GND), U5.E1 (GND), U5.E3 (GND), U5.E6 (GND), U5.E8 (GND), U5.E10 (GND), U5.E14 (GND), U5.F5 (GND), U5.F9 (GND), U5.G3 (GND), U5.G6 (GND), U5.G10 (GND), U5.G12 (GND), U5.H5 (GND), U5.H9 (GND), U5.J6 (GND), U5.J7 (DXN_0), U5.J8 (DXP_0), U5.J10 (GND), U5.K1 (GND), U5.K5 (GND), U5.K7 (GND), U5.K9 (GND), U5.K14 (GND), U5.L4 (GND), U5.L6 (GND), U5.L8 (GND), U5.L10 (GND), U5.L11 (GND), U5.L12 (IO_L16P_T2_CSI_B_14), U5.M13 (IO_L15P_T2_DQS_RDWR_B_14), U5.N3 (GND), U5.N5 (GND), U5.N9 (GND), U5.N12 (GND), U5.P1 (GND), U5.P14 (GND), U6.4 (VSS), X3.2 (GND), X4.2 (GND), X5.2 (GND); also elsewhere on the board
INIT_B: R21.1, U5.P8 (INIT_B_0); also elsewhere on the board
JTAG_TCK: J9.3 (TCK), U5.A7 (TCK_0); also elsewhere on the board
JTAG_TDI: J9.5 (TDI), U5.P7 (TDI_0); also elsewhere on the board
JTAG_TDO: J9.4 (TDO), U5.P6 (TDO_0); also elsewhere on the board
JTAG_TMS: J9.6 (TMS), U5.M6 (TMS_0); also elsewhere on the board
MODE0: R24.2, S2.1 (1X), U5.M7 (M0_0)
MODE1: R25.2, S2.2 (2X), U5.M8 (M1_0)
MODE2: R26.2, S2.3 (3X), U5.M9 (M2_0)
MONITORING: S2.4 (4X); also elsewhere on the board
unnamed: D10.1, R22.2
unnamed: D9.1, R20.2
unnamed: D8.1, R19.2
unnamed: D7.1, R18.2
OSC_32: U5.H11 (IO_L13P_T2_MRCC_14), X5.3 (OUTPUT)
OSC_50: U5.F11 (IO_L12N_T1_MRCC_14), X4.3 (OUTPUT)
OSC_100: U5.A10 (IO_L3N_T0_DQS_EMCCLK_14), X3.3 (OUTPUT)
SPI_CS: R27.2, U5.C11 (IO_L6P_T0_FCS_B_14), U6.1 (CE); also elsewhere on the board
SPI_SCK/CCLK: U5.A8 (CCLK_0), U6.6 (SCK); also elsewhere on the board
SRAM_A0: U4.5 (A0), U5.B3 (IO_L3P_T0_DQS_34)
SRAM_A1: U4.4 (A1), U5.B2 (IO_L5P_T0_34)
SRAM_A2: U4.3 (A2), U5.B5 (IO_L4P_T0_34)
SRAM_A3: U4.2 (A3), U5.B6 (IO_0_34)
SRAM_A4: U4.1 (A4), U5.A5 (IO_L4N_T0_34)
SRAM_A5: U4.44 (A5), U5.A4 (IO_L2P_T0_34)
SRAM_A6: U4.43 (A6), U5.A3 (IO_L2N_T0_34)
SRAM_A7: U4.42 (A7), U5.A2 (IO_L3N_T0_DQS_34)
SRAM_A8: U4.27 (A8), U5.M3 (IO_L19P_T3_34)
SRAM_A9: U4.26 (A9), U5.M4 (IO_L23N_T3_34)
SRAM_A10: U4.25 (A10), U5.M5 (IO_L23P_T3_34)
SRAM_A11: U4.24 (A11), U5.N1 (IO_L20N_T3_34)
SRAM_A12: U4.22 (A12), U5.P5 (IO_L24P_T3_34)
SRAM_A13: U4.21 (A13), U5.P4 (IO_L21P_T3_DQS_34)
SRAM_A14: U4.20 (A14), U5.P3 (IO_L21N_T3_DQS_34)
SRAM_A15: U4.19 (A15), U5.P2 (IO_L20P_T3_34)
SRAM_A16: U4.18 (A16), U5.J4 (IO_L17P_T2_34)
SRAM_A17: U4.23 (A17), U5.N4 (IO_L24N_T3_34)
SRAM_A18: U4.28 (A18), U5.M2 (IO_L19N_T3_VREF_34)
SRAM_CS: U4.6 (CS1#), U5.C3 (IO_L1N_T0_34)
SRAM_D0: U4.7 (I/O0), U5.C4 (IO_L6N_T0_VREF_34)
SRAM_D1: U4.8 (I/O1), U5.D2 (IO_L10N_T1_34)
SRAM_D2: U4.9 (I/O2), U5.D3 (IO_L1P_T0_34)
SRAM_D3: U4.10 (I/O3), U5.E2 (IO_L10P_T1_34)
SRAM_D4: U4.13 (I/O4), U5.F2 (IO_L8N_T1_34)
SRAM_D5: U4.14 (I/O5), U5.F3 (IO_L8P_T1_34)
SRAM_D6: U4.15 (I/O6), U5.H2 (IO_L14P_T2_SRCC_34)
SRAM_D7: U4.16 (I/O7), U5.H3 (IO_L13N_T2_MRCC_34)
SRAM_D8: U4.29 (I/O8), U5.M1 (IO_L18P_T2_34)
SRAM_D9: U4.30 (I/O9), U5.L3 (IO_L22P_T3_34)
SRAM_D10: U4.31 (I/O10), U5.L1 (IO_L18N_T2_34)
SRAM_D11: U4.32 (I/O11), U5.L2 (IO_L22N_T3_34)
SRAM_D12: U4.35 (I/O12), U5.J1 (IO_L15N_T2_DQS_34)
SRAM_D13: U4.36 (I/O13), U5.H1 (IO_L14N_T2_SRCC_34)
SRAM_D14: U4.37 (I/O14), U5.G1 (IO_L9P_T1_DQS_34)
SRAM_D15: U4.38 (I/O15), U5.F1 (IO_L9N_T1_DQS_34)
SRAM_LB: U4.39 (LB#), U5.D1 (IO_L11P_T1_SRCC_34)
SRAM_OE: U4.41 (OE#), U5.B1 (IO_L5N_T0_34)
SRAM_POWER: M4.4 (G); also elsewhere on the board
SRAM_UB: U4.40 (UB#), U5.C1 (IO_L11N_T1_SRCC_34)
SRAM_VDD: C24.1, C25.1, C26.1, C27.1, C28.1, C29.1, C30.1, M4.5 (D), M4.6 (D), M4.7 (D), M4.8 (D), U4.11 (VDD), U4.33 (VDD), U5.G2 (VCCO_34), U5.K2 (VCCO_34), U5.N2 (VCCO_34)
SRAM_VDD_MON: M4.1 (S), M4.2 (S), M4.3 (S); also elsewhere on the board
SRAM_WE: U4.17 (WE#), U5.H4 (IO_L13P_T2_MRCC_34)
XMEM_A8: U5.D13 (IO_L8N_T1_D12_14); also elsewhere on the board
XMEM_A9: U5.D12 (IO_L8P_T1_D11_14); also elsewhere on the board
XMEM_A10: U5.E13 (IO_L10N_T1_D15_14); also elsewhere on the board
XMEM_A11: U5.E12 (IO_L7N_T1_D10_14); also elsewhere on the board
XMEM_A12: U5.F14 (IO_L9N_T1_DQS_D13_14); also elsewhere on the board
XMEM_A13: U5.F13 (IO_L10P_T1_D14_14); also elsewhere on the board
XMEM_A14: U5.F12 (IO_L7P_T1_D09_14); also elsewhere on the board
XMEM_A15: U5.G14 (IO_L9P_T1_DQS_14); also elsewhere on the board
XMEM_RD: U5.D14 (IO_L11P_T1_SRCC_14); also elsewhere on the board
XMEM_WR: U5.C14 (IO_L11N_T1_SRCC_14); also elsewhere on the board

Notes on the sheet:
Decoupling caps
SRAM
Oscillator
FPGA Reset
FPGA LEDs
FPGA power control
FPGA GPIO
FPGA Mode Switch
SPI Flash
vccint
vccaux
vccio
sram_vdd
FPGA JTAG

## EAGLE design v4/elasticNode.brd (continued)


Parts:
R29, R30: 1.5k; 0805
R31, R33: 0.8; 0805
R32, R34, R37, R38, R40: .8; 0805
R35: 100; 0805
R36: 2000; 0805
R39: 0.15; 0805
R41: 750; 0805
R42: 300; 0805
U7, U8, U9, U10: PAC1720; VDFN10

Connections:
1V: R40.2, U10.3 (SENSE2+); also elsewhere on the board
1V8: R31.2, R38.2, U7.1 (SENSE1+), U10.1 (SENSE1+); also elsewhere on the board
3V3: R29.2, R30.2, R32.2, R33.2, R34.2, R37.2, U7.3 (SENSE2+), U7.10 (VDD), U8.1 (SENSE1+), U8.3 (SENSE2+), U8.10 (VDD), U9.1 (SENSE1+), U9.10 (VDD), U10.10 (VDD); also elsewhere on the board
5V: R39.2, U9.3 (SENSE2+); also elsewhere on the board
DAUGHTER_VCC: R32.1, U8.2 (SENSE1-); also elsewhere on the board
FPGA_VCCAUX_MON: R38.1, U10.2 (SENSE1-); also elsewhere on the board
FPGA_VCCINT_MON: R40.1, U10.4 (SENSE2-); also elsewhere on the board
FPGA_VCCIO_MON: R33.1, U7.4 (SENSE2-); also elsewhere on the board
GND: R35.1, R36.1, R41.1, R42.1, U7.5 (GND), U7.P$1 (GND), U7.P$2 (GND), U7.P$3 (GND), U7.P$4 (GND), U8.5 (GND), U8.P$1 (GND), U8.P$2 (GND), U8.P$3 (GND), U8.P$4 (GND), U9.5 (GND), U9.P$1 (GND), U9.P$2 (GND), U9.P$3 (GND), U9.P$4 (GND), U10.5 (GND), U10.P$1 (GND), U10.P$2 (GND), U10.P$3 (GND), U10.P$4 (GND); also elsewhere on the board
MCU_VCC: R34.1, U8.4 (SENSE2-); also elsewhere on the board
unnamed: R42.2, U10.6 (ADDR_SEL)
unnamed: R41.2, U9.6 (ADDR_SEL)
unnamed: R35.2, U7.6 (ADDR_SEL)
unnamed: R36.2, U8.6 (ADDR_SEL)
SCL: R29.1, U7.9 (SMCLK), U8.9 (SMCLK), U9.9 (SMCLK), U10.9 (SMCLK); also elsewhere on the board
SDA: R30.1, U7.8 (SMDATA), U8.8 (SMDATA), U9.8 (SMDATA), U10.8 (SMDATA); also elsewhere on the board
SRAM_VDD_MON: R31.1, U7.2 (SENSE1-); also elsewhere on the board
USB_VCC_RAW: R39.1, U9.4 (SENSE2-); also elsewhere on the board
WIRELESS_VCC: R37.1, U9.2 (SENSE1-); also elsewhere on the board

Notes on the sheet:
Rmax = Vmax / Imax = 80mV / Imax
Imax_SENSE1=100mA Imax_SENSE2=100mA
Imax_SENSE1=100mA Imax_SENSE2=533mA
FPGA_3V3 I/O and FPGA_1V8 I/O(and SRAM)
Daughter_Board and MCU
Current measure
FPGA_AUX and FPGA_Core
USB_VCC_ROW and Wireless board


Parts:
C31, C32: 10u; 0805
C33, C34, C35: 22u; 0805
D11: RED; 0805
J11: USB_CONNMICRO_SMT; USB_MICRO_B_SMT
L1, L2, L3: 3.3uH; 0805
R43: 6k8; 0805
R44, R48: 10k; 0805
R45: 20k; 0805
R46: 1k5; 0805
R47: 15k; 0805
R49: 270; 0805
TP1, TP2, TP3, TP4, TP5: TEST_POINTTHT; THT
U11, U12: LTC3419DFN; DFN8

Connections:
1V: C34.1, L2.2, R44.2, TP4.3; also elsewhere on the board
1V8: C35.2, L3.1, R45.1, TP3.3; also elsewhere on the board
3V3: C33.1, L1.1, R43.2, TP2.3, U12.7 (RUN2); also elsewhere on the board
5V: C31.1, C32.1, TP1.3, U11.2 (RUN1), U11.3 (MODE), U11.5 (VIN), U12.2 (RUN1), U12.3 (MODE), U12.5 (VIN); also elsewhere on the board
GND: C31.2, C32.2, C33.2, C34.2, C35.1, J11.5 (GND), R46.2, R47.2, R48.1, R49.1, TP5.3, U11.9 (GND), U12.9 (GND); also elsewhere on the board
unnamed: R44.1, R47.1, U12.1 (VFB1)
unnamed: R45.2, R48.2, U12.8 (VFB2)
unnamed: L2.1, U12.4 (SW1)
unnamed: L3.2, U12.6 (SW2)
unnamed: D11.2, R49.2
unnamed: R43.1, R46.1, U11.1 (VFB1)
unnamed: L1.2, U11.4 (SW1)
UID: J11.4 (UID); also elsewhere on the board
USBD+: J11.3 (D+); also elsewhere on the board
USBD-: J11.2 (D-); also elsewhere on the board
USB_VCC_RAW: D11.1, J11.1 (VCC); also elsewhere on the board

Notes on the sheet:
R1/R2 = (Vo/Vref) - 1 = (1.8/0.6) - 1 = 2 Vo = 0.6V * (1 + R2/R1) = 0.6*(1+20000/10000)=1.8V
Vreg 1.0V
Vreg 3.3V and 1.8V
R1/R2 = (Vo/Vref) - 1 = (1/0.6) - 1 = 0.67 Vo = 0.6V * (1 + R2/R1) = 0.6*(1+10000/15000)=1V
R1/R2 = (Vo/Vref) - 1 = (1/0.6) - 1 = 0.67 Vo = 0.6V * (1 + R2/R1) = 0.6*(1+6800/1500)=3.32V



Board: 4 copper layers, 58.2 x 52.5 mm, 138 parts (76 on the bottom side), 177 nets.

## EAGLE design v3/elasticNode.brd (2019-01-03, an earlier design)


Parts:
C35, C36: 20p; 0805
J1: ISP_CONN_6PIN; 3X2_HEADER_SMT
J2: FEMALE_HEADER_2X2; 2X2_HEADER
LED0, LED1, LED2, LED3: GREEN 2.2V; 0805
R1, R2: 2.4k; 0805
R3, R4, R5, R6: 550; 0805
R7: 15k; 0805
S1: SPST_BUTTON2PIN_SMT; SPST_2PIN_SMT
U1: ATMEGA64AQFN; QFN64
U2: SST26VF032B; SOIC8
U3: MRF24J40MA
X1: 12MHz; 3.2X2.5_OSC

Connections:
3V3: J1.2 (VCC); also elsewhere on the board
A8: U1.35 (PC0_A8); also elsewhere on the board
A9: U1.36 (PC1_A9); also elsewhere on the board
A10: U1.37 (PC2_A10); also elsewhere on the board
A11: U1.38 (PC3_A11); also elsewhere on the board
A12: U1.39 (PC4_A12); also elsewhere on the board
A13: U1.40 (PC5_A13); also elsewhere on the board
A14: U1.41 (PC6_A14); also elsewhere on the board
A15: U1.42 (PC7_A15); also elsewhere on the board
AD0/SELECTMAP_D7: U1.51 (PA0_AD0); also elsewhere on the board
AD1/SELECTMAP_D6: U1.50 (PA1_AD1); also elsewhere on the board
AD2/SELECTMAP_D5/MCU_RX1: U1.49 (PA2_AD2); also elsewhere on the board
AD3/SELECTMAP_D4/MCU_TX1: U1.48 (PA3_AD3); also elsewhere on the board
AD4/SELECTMAP_D3: U1.47 (PA4_AD4); also elsewhere on the board
AD5/SELECTMAP_D2/FPGA_MISO3: U1.46 (PA5_AD5); also elsewhere on the board
AD6/SELECTMAP_D1/FPGA_MISO2: U1.45 (PA6_AD6); also elsewhere on the board
AD7/SELECTMAP_D0/FPGA_MISO1: U1.44 (PA7_AD7); also elsewhere on the board
ALE: U1.43 (PG2_ALE); also elsewhere on the board
CCLK: U1.26 (PD1_SDA/INT1); also elsewhere on the board
CSI_B/FPGA_MISO0: U1.25 (PD0_SCL/INT0); also elsewhere on the board
ENABLE_LEDS: U1.9 (PE7_ICP3/INT7); also elsewhere on the board
FPGA_DONE: U1.8 (PE6_T3/INT6); also elsewhere on the board
FPGA_POWER: U1.5 (PE3_OC3A/AIN1); also elsewhere on the board
FPGA_RESET: U1.59 (PF2_ADC2); also elsewhere on the board
FPGA_SUSPEND: U1.7 (PE5_OC3C/INT5); also elsewhere on the board
GND: C35.2, C36.2, J1.6 (GND), LED0.2, LED1.2, LED2.2, LED3.2, S1.1, U1.22 (GND), U1.53 (GND), U1.63 (GND), U1.PAD (GND), U1.VIA1 (GND), U1.VIA2 (GND), U1.VIA3 (GND), U1.VIA4 (GND), U1.VIA5 (GND), U1.VIA6 (GND), U1.VIA7 (GND), U1.VIA8 (GND), U1.VIA9 (GND), U2.4 (VSS), U3.1 (GND), U3.11 (GND), U3.12 (GND); also elsewhere on the board
INIT_B: U1.58 (PF3_ADC3); also elsewhere on the board
JTAG_TCK: U1.57 (PF4_ADC4/TCK); also elsewhere on the board
JTAG_TDI: U1.55 (PF6_ADC6/TDO); also elsewhere on the board
JTAG_TDO: U1.56 (PF5_ADC5/TMS); also elsewhere on the board
JTAG_TMS: U1.54 (PF7_ADC7/TDI); also elsewhere on the board
MCU_FLASH_CE: R2.2, U1.14 (PB4_OC0), U2.1 (CE)
MCU_GPIO_0: J2.1, U1.17 (PB7_OC2/OC1C)
MCU_GPIO_1: J2.2, U1.18 (PG3_TOSC2)
MCU_GPIO_2: J2.3, U1.19 (PG4_TOSC2)
MCU_GPIO_3: J2.4, U1.16 (PB6_OC1B)
MCU_LED0: R3.1, U1.32 (PD7_T2)
MCU_LED1: R4.1, U1.31 (PD6_T1)
MCU_LED2: R5.1, U1.30 (PD5_XCK1)
MCU_LED3: R6.1, U1.29 (PD4_ICP1)
MCU_MISO: U1.13 (PB3_MISO), U2.2 (SO), U3.7 (SDO)
MCU_MOSI: U1.12 (PB2_MOSI), U2.5 (SI), U3.5 (SDI)
MCU_RESET: J1.5 (RST), R7.1, S1.2 (3), U1.20 (_RESET)
MCU_RX0/PDI: J1.4 (MOSI), U1.2 (PE0_RXD0/PDI)
MCU_RX1: U1.27 (PD2_RXD1/INT2); also elsewhere on the board
MCU_SCK: J1.3 (SCK), U1.11 (PB1_SCK), U2.6 (SCK), U3.6 (SCK)
MCU_TX0/PDO: J1.1 (MISO), U1.3 (PE1_TXD0/PDO)
MCU_TX1: U1.28 (PD3_TXD1/INT3); also elsewhere on the board
MCU_VCC: R1.1, R2.1, R7.2, U1.21 (VCC), U1.52 (VCC), U1.62 (AVREF), U1.64 (AVCC), U2.3 (WP), U2.7 (HOLD), U2.8 (VDD); also elsewhere on the board
unnamed: LED3.1, R6.2
unnamed: LED2.1, R5.2
unnamed: LED1.1, R4.2
unnamed: LED0.1, R3.2
RD: U1.34 (PG1_RD#); also elsewhere on the board
WIRELESS_CS: R1.2, U1.60 (PF1_ADC1), U3.8 (_CS)
WIRELESS_INT: U1.61 (PF0_ADC0), U3.4 (INT)
WIRELESS_RESET: U1.15 (PB5_OC1A), U3.2 (_RESET)
WIRELESS_VCC: U3.10 (VI); also elsewhere on the board
WIRELESS_WAKE: U1.4 (PE2_XCK0/AIN0), U3.3 (WAKE)
WR: U1.33 (PG0_WR#); also elsewhere on the board
XTAL1: C36.1, U1.24 (XTAL1), X1.1
XTAL2: C35.1, U1.23 (XTAL2), X1.3


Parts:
C1, C2, C3, C4, C5, C6, C9, C10, C14, C15, C16, C17, C20, C23: 4.7uF; 0805
C7, C8, C11, C12, C18, C19, C21, C22: .47uF; 0402
C13: 0.47uF; 0402
C24: .47uF; 0805
J3, J4: FEMALE_HEADER_2X1; 2X1_HEADER
J5: FEMALE_HEADER_10X2; 10X2_HEADER_SMT
LED4: RED 1.8V 2mA; 0805
LED5, LED6, LED7: RED; 0805
M1, M2: SISS23DN; POWERPAK1212-8
R8, R9, R10, R11: 750; 0805
R12, R13, R14: 2.4k; 0805
R15: 15k; 0805
S2: SPST_BUTTON2PIN_SMT; SPST_2PIN_SMT
S3: SPST_DIP_4; SPST_DIP4_SMT
U4: SPARTAN6-LX9; TQG144
U5: SST26VF032B; SOIC8
X2: 50MHz; 3.2X2.5_OSC
X3: 32MHz; 3.2X2.5_OSC

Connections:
A8: U4.83 (IO_L45P_1); also elsewhere on the board
A9: U4.82 (IO_L45N_1); also elsewhere on the board
A10: U4.81 (IO_L46P_1); also elsewhere on the board
A11: U4.80 (IO_L46N_1); also elsewhere on the board
A12: U4.79 (IO_L47P_1); also elsewhere on the board
A13: U4.78 (IO_L47N_1); also elsewhere on the board
A14: U4.75 (IO_L74P_AWAKE_1); also elsewhere on the board
A15: U4.74 (IO_L74N_DOUT_BUSY_1); also elsewhere on the board
AD0/SELECTMAP_D7: U4.48 (IO_L48P_D7_2); also elsewhere on the board
AD1/SELECTMAP_D6: U4.43 (IO_L62N_D6_2); also elsewhere on the board
AD2/SELECTMAP_D5/MCU_RX1: U4.44 (IO_L62P_D5_2); also elsewhere on the board
AD3/SELECTMAP_D4/MCU_TX1: U4.45 (IO_L49N_D4_2); also elsewhere on the board
AD4/SELECTMAP_D3: U4.46 (IO_L49P_D3_2); also elsewhere on the board
AD5/SELECTMAP_D2/FPGA_MISO3: U4.61 (IO_L12N_D2_MISO3_2), U5.7 (HOLD); also elsewhere on the board
AD6/SELECTMAP_D1/FPGA_MISO2: U4.62 (IO_L12P_D1_MISO2_2), U5.3 (WP); also elsewhere on the board
AD7/SELECTMAP_D0/FPGA_MISO1: U4.65 (IO_L3P_D0_DIN_MISO_MISO1_2), U5.2 (SO); also elsewhere on the board
ALE: U4.66 (IO_L2N_CMPMOSI_2); also elsewhere on the board
CCLK: U4.70 (IO_L1P_CCLK_2), U5.6 (SCK); also elsewhere on the board
CSI_B/FPGA_MISO0: U4.64 (IO_L3N_MOSI_CSI_B_MISO0_2), U5.5 (SI); also elsewhere on the board
CSO_B: R14.2, U4.38 (IO_L65N_CSO_B_2), U5.1 (CE)
ENABLE_LEDS: S3.3 (3X); also elsewhere on the board
FPGA_DONE: U4.71 (DONE_2); also elsewhere on the board
FPGA_GPIO_0: J5.1, U4.1 (IO_L83N_VREF_3)
FPGA_GPIO_1: J5.20, U4.2 (IO_L83P_3)
FPGA_GPIO_2: J5.2, U4.5 (IO_L52N_3)
FPGA_GPIO_3: J5.19, U4.6 (IO_L52P_3)
FPGA_GPIO_4: J5.3, U4.7 (IO_L51N_3)
FPGA_GPIO_5: J5.18, U4.8 (IO_L51P_3)
FPGA_GPIO_6: J5.4, U4.9 (IO_L50N_3)
FPGA_GPIO_7: J5.17, U4.10 (IO_L50P_3)
FPGA_GPIO_8: J5.5, U4.11 (IO_L49N_3)
FPGA_GPIO_9: J5.16, U4.12 (IO_L49P_3)
FPGA_GPIO_10: J5.15, U4.15 (IO_L44P_GCLK21_3)
FPGA_GPIO_11: J5.6, U4.14 (IO_L44N_GCLK20_3)
FPGA_GPIO_12: J5.14, U4.17 (IO_L43P_GCLK23_3)
FPGA_GPIO_13: J5.7, U4.16 (IO_L43N_GCLK22_IRDY2_3)
FPGA_GPIO_14: J5.8, U4.21 (IO_L42N_GCLK24_3)
FPGA_GPIO_15: J5.13, U4.22 (IO_L42P_GCLK25_TRDY2_3)
FPGA_GPIO_16: J5.9, U4.23 (IO_L41N_GCLK26_3)
FPGA_GPIO_17: J5.12, U4.24 (IO_L41P_GCLK27_3)
FPGA_GPIO_18: J5.10, U4.27 (IO_L37P_3)
FPGA_GPIO_19: J5.11, U4.26 (IO_L37N_3)
FPGA_LED0: R8.1, U4.105 (IO_L1P_1)
FPGA_LED1: R9.1, U4.104 (IO_L1N_VREF_1)
FPGA_LED2: R10.1, U4.102 (IO_L32P_1)
FPGA_LED3: R11.1, U4.101 (IO_L32N_1)
FPGA_POWER: M1.4 (G), M2.4 (G); also elsewhere on the board
FPGA_RESET: R15.1, S2.2 (3), U4.37 (PROGRAM_B_2); also elsewhere on the board
FPGA_SUSPEND: U4.73 (SUSPEND); also elsewhere on the board
FPGA_VCCAUX: C2.1, C3.1, C4.1, C6.1, C7.1, C8.1, C10.1, C11.1, C12.1, C14.1, C15.1, C16.1, C17.1, C18.1, C19.1, C20.1, C21.1, C22.1, C23.1, C24.1, J3.1, M2.5 (D), M2.6 (D), M2.7 (D), M2.8 (D), R12.1, R13.1, R14.1, R15.2, U4.4 (VCCO_3), U4.18 (VCCO_3), U4.20 (VCCAUX), U4.31 (VCCO_3), U4.36 (VCCAUX), U4.42 (VCCO_2), U4.53 (VCCAUX), U4.63 (VCCO_2), U4.76 (VCCO_1), U4.86 (VCCO_1), U4.90 (VCCAUX), U4.103 (VCCO_1), U4.122 (VCCO_0), U4.125 (VCCO_0), U4.129 (VCCAUX), U4.135 (VCCO_0), U5.8 (VDD), X2.1 (EN), X2.4 (VS+), X3.1 (EN), X3.4 (VS+)
FPGA_VCCAUX_MON: M2.1 (S), M2.2 (S), M2.3 (S); also elsewhere on the board
FPGA_VCCINT: C1.1, C5.1, C9.1, C13.1, J4.1, M1.5 (D), M1.6 (D), M1.7 (D), M1.8 (D), U4.19 (VCCINT), U4.28 (VCCINT), U4.52 (VCCINT), U4.89 (VCCINT), U4.128 (VCCINT)
FPGA_VCCINT_MON: M1.1 (S), M1.2 (S), M1.3 (S); also elsewhere on the board
GND: C1.2, C2.2, C3.2, C4.2, C5.2, C6.2, C7.2, C8.2, C9.2, C10.2, C11.2, C12.2, C13.2, C14.2, C15.2, C16.2, C17.2, C18.2, C19.2, C20.2, C21.2, C22.2, C23.2, C24.2, J3.3 (2), J4.3 (2), LED4.2, LED5.2, LED6.2, LED7.2, S2.1, S3.5 (4Y), S3.6 (3Y), S3.7 (2Y), S3.8 (1Y), U4.3 (GND), U4.13 (GND), U4.25 (GND), U4.47 (IO_L48N_RDWR_B_VREF_2), U4.49 (GND), U4.54 (GND), U4.68 (GND), U4.77 (GND), U4.91 (GND), U4.96 (GND), U4.108 (GND), U4.113 (GND), U4.130 (GND), U4.136 (GND), U5.4 (VSS), X2.2 (GND), X3.2 (GND); also elsewhere on the board
INIT_B: U4.39 (IO_L65P_INIT_B_2); also elsewhere on the board
JTAG_TCK: U4.109 (TCK); also elsewhere on the board
JTAG_TDI: U4.110 (TDI); also elsewhere on the board
JTAG_TDO: U4.106 (TDO); also elsewhere on the board
JTAG_TMS: U4.107 (TMS); also elsewhere on the board
MODE0: R12.2, S3.1 (1X), U4.69 (IO_L1N_M0_CMPMISO_2)
MODE1: R13.2, S3.2 (2X), U4.60 (IO_L13P_M1_2)
MONITORING: S3.4 (4X); also elsewhere on the board
unnamed: LED7.1, R11.2
unnamed: LED6.1, R10.2
unnamed: LED5.1, R9.2
unnamed: LED4.1, R8.2
OSC_32: U4.94 (IO_L40N_GCLK10_1), X3.3 (OUTPUT)
OSC_50: U4.51 (IO_L31P_GCLK31_D14_2), X2.3 (OUTPUT)
RD: U4.84 (IO_L43N_GCLK4_1); also elsewhere on the board
WR: U4.85 (IO_L43P_GCLK5_1); also elsewhere on the board

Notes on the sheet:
Decoupling caps
vccint
vccaux
vcco0
vcco1
vcco2
vcco3


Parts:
15K: 10k; 0805
C32: 1u; 0805
C33, C34: 20pF; 0805
J6: FEMALE_HEADER_2X1; 2X1_HEADER
J9: USB_CONNSMT; USB_MICRO_B_SMT
J10: ISP_CONN_6PIN; 3X2_HEADER_SMT
R16: 0.8; 0805
R17, R19, R22, R36: .8; 0805
R18: 0.16; 0805
R20: 100; 0805
R21: 300; 0805
R23: 2000; 0805
R24, R25: 1.5k; 0805
R33, R34: 22; 0805
R35: 15k; 0805
S4: SPST_BUTTON2PIN_SMT; SPST_2PIN_SMT
U6, U7, U8: PAC1720; VDFN10
U11: ATMEGA32U4; QFN44
X4: 12MHz; 3.2X2.5_OSC

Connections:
1V2: R17.2, U7.3 (SENSE2+); also elsewhere on the board
3V3: R16.2, R19.2, R22.2, R24.2, R25.1, R36.1, U6.3 (SENSE2+), U7.1 (SENSE1+), U8.1 (SENSE1+), U8.3 (SENSE2+); also elsewhere on the board
5V: R18.1, U6.1 (SENSE1+); also elsewhere on the board
D+: R33.2, U11.4 (D+)
D-: R34.2, U11.3 (D-)
FPGA_VCCAUX_MON: R19.1, U7.2 (SENSE1-); also elsewhere on the board
FPGA_VCCINT_MON: R17.1, U7.4 (SENSE2-); also elsewhere on the board
GND: C32.2, C33.2, C34.2, J6.3 (2), J9.5 (GND), J10.6 (GND), R20.1, R21.1, R23.1, S4.1, U6.5 (GND), U6.P$1 (GND), U6.P$2 (GND), U6.P$3 (GND), U6.P$4 (GND), U7.5 (GND), U7.P$1 (GND), U7.P$2 (GND), U7.P$3 (GND), U7.P$4 (GND), U8.5 (GND), U8.P$1 (GND), U8.P$2 (GND), U8.P$3 (GND), U8.P$4 (GND), U11.5 (UGND), U11.15 (GND), U11.23 (GND), U11.35 (GND), U11.43 (GND), U11.45 (GND); also elsewhere on the board
MCU_VCC: R22.1, U8.4 (SENSE2-); also elsewhere on the board
MONITORING: U11.1 (PE6(INT6/AIN0)); also elsewhere on the board
MON_HWB: 15K.1, J6.1, U11.33 (PE2(HWB))
MON_MISO: J10.1 (MISO), U11.11 (PB3(PDO/PCINT3/MISO))
MON_MOSI: J10.4 (MOSI), U11.10 (PB2(PDI/PCINT2/MOSI))
MON_RESET: J10.5 (RST), R35.1, S4.2 (3), U11.13 (_RESET)
MON_SCK: J10.3 (SCK), U11.9 (PB1(PCINT1/SCL))
MON_VCC: 15K.2, J10.2 (VCC), R16.1, R35.2, U6.4 (SENSE2-), U6.10 (VDD), U7.10 (VDD), U8.10 (VDD), U11.14 (VCC), U11.24 (AVCC), U11.34 (VCC), U11.44 (AVCC)
MON_XTAL1: C33.1, U11.17 (XTAL1), X4.1
MON_XTAL2: C34.1, U11.16 (XTAL2), X4.3
unnamed: R23.2, U8.6 (ADDR_SEL)
unnamed: R21.2, U7.6 (ADDR_SEL)
unnamed: R20.2, U6.6 (ADDR_SEL)
unnamed: J9.3 (D+), R33.1
unnamed: J9.2 (D-), R34.1
SCL: R24.1, U6.9 (SMCLK), U7.9 (SMCLK), U8.9 (SMCLK), U11.18 (PD0(OC0B/SCL/INT0))
SDA: R25.2, U6.8 (SMDATA), U7.8 (SMDATA), U8.8 (SMDATA), U11.19 (PD1(SDA/INT1))
UCAP: C32.1, U11.6 (UCAP)
USB2_VCC: J9.1 (VCC), U11.2 (UVCC), U11.7 (VBUS)
USB_VCC: R18.2, U6.2 (SENSE1-); also elsewhere on the board
WIRELESS_VCC: R36.2, U8.2 (SENSE1-); also elsewhere on the board

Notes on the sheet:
Rmax = Vmax / Imax = 80mV / Imax
Imax=100mA
Imax=500mA


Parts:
C25: 10n; 0805
C26, C28: 100n; 0805
C27: 4.7u; 0805
C29, C31: 22u; 0805
C30: 10u; 0805
J8: USB_CONNSMT; USB_MICRO_B_SMT
L1: 40Ohm 1.5A; 0805
L2, L3: 3.3uH; 0805
PWR: RED; 0805
R26, R27: 1.5k; 0805
R28: 6k8; 0805
R29, R30, R31: 1k5; 0805
R32: 270; 0805
RX: ORANGE; 0805
TX: ORANGE 2V; 0805
U9: FT232RSSOP28; SSOP28
U10: LTC3419DFN; DFN8

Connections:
1V2: C31.2, L3.2, R31.2; also elsewhere on the board
3V3: C29.1, L2.1, R28.1, U10.7 (RUN2); also elsewhere on the board
5V: C30.1, PWR.1, RX.1, TX.1, U9.4 (VCCIO), U9.20 (VCC), U10.2 (RUN1), U10.3 (MODE), U10.5 (VIN); also elsewhere on the board
FTDI_RXLED: R27.1, U9.14 (CBUS3)
GND: C25.2, C26.1, C27.1, C28.2, C29.2, C30.2, C31.1, J8.5 (GND), R29.2, R30.1, R32.1, U9.7 (GND), U9.18 (GND), U9.21 (GND), U9.25 (AGND), U9.26 (TEST), U10.9 (GND); also elsewhere on the board
MCU_RX1: U9.1 (TXD); also elsewhere on the board
MCU_TX1: U9.5 (RXD); also elsewhere on the board
unnamed: L2.2, U10.4 (SW1)
unnamed: R28.2, R29.1, U10.1 (VFB1)
unnamed: C28.1, U9.17 (3V3OUT)
unnamed: R30.2, R31.1, U10.8 (VFB2)
unnamed: L3.1, U10.6 (SW2)
unnamed: R26.1, U9.13 (CBUS2)
unnamed: R26.2, TX.2
unnamed: R27.2, RX.2
unnamed: PWR.2, R32.2
USBD+: J8.3 (D+), U9.15 (USBDP)
USBD-: J8.2 (D-), U9.16 (USBDM)
USB_VCC: C26.2, C27.2, L1.2; also elsewhere on the board
USB_VCC_RAW: C25.1, J8.1 (VCC), L1.1

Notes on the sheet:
vreg

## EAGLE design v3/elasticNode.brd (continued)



Board: 4 copper layers, 58.2 x 52.5 mm, 117 parts (47 on the bottom side), 135 nets.

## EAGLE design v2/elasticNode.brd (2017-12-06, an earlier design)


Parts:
J1: ISP_CONN_6PIN; 3X2_HEADER_SMT
J2: FEMALE_HEADER_2X2; 2X2_HEADER
LED0, LED1, LED2, LED3: GREEN 2.2V; 0805
R1, R2: 2.4k; 0805
R3, R4, R5, R6: 550; 0805
R7: 15k; 0805
S1: SPST_BUTTON2PIN_SMT; SPST_2PIN_SMT
U1: ATMEGA64AQFN; QFN64
U2: SST26VF032B; SOIC8
U3: MRF24J40MA
X1: 12MHz; 3.2X2.5_OSC

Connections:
3V3: J1.2 (VCC); also elsewhere on the board
A8: U1.35 (PC0_A8); also elsewhere on the board
A9: U1.36 (PC1_A9); also elsewhere on the board
A10: U1.37 (PC2_A10); also elsewhere on the board
A11: U1.38 (PC3_A11); also elsewhere on the board
A12: U1.39 (PC4_A12); also elsewhere on the board
A13: U1.40 (PC5_A13); also elsewhere on the board
A14: U1.41 (PC6_A14); also elsewhere on the board
A15: U1.42 (PC7_A15); also elsewhere on the board
AD0: U1.51 (PA0_AD0); also elsewhere on the board
AD1: U1.50 (PA1_AD1); also elsewhere on the board
AD2: U1.49 (PA2_AD2); also elsewhere on the board
AD3: U1.48 (PA3_AD3); also elsewhere on the board
AD4: U1.47 (PA4_AD4); also elsewhere on the board
AD5: U1.46 (PA5_AD5); also elsewhere on the board
AD6: U1.45 (PA6_AD6); also elsewhere on the board
AD7: U1.44 (PA7_AD7); also elsewhere on the board
ALE: U1.43 (PG2_ALE); also elsewhere on the board
CCLK: U1.19 (PG4_TOSC2); also elsewhere on the board
CSI_B/FPGA_MISO0: U1.18 (PG3_TOSC2); also elsewhere on the board
FPGA_RESET: U1.16 (PB6_OC1B); also elsewhere on the board
GND: J1.6 (GND), LED0.2, LED1.2, LED2.2, LED3.2, S1.1, U1.22 (GND), U1.53 (GND), U1.63 (GND), U1.PAD (GND), U1.VIA1 (GND), U1.VIA2 (GND), U1.VIA3 (GND), U1.VIA4 (GND), U1.VIA5 (GND), U1.VIA6 (GND), U1.VIA7 (GND), U1.VIA8 (GND), U1.VIA9 (GND), U2.4 (VSS), U3.1 (GND), U3.11 (GND), U3.12 (GND); also elsewhere on the board
INIT_B: U1.17 (PB7_OC2/OC1C); also elsewhere on the board
JTAG_TCK: U1.57 (PF4_ADC4/TCK); also elsewhere on the board
JTAG_TDI: U1.55 (PF6_ADC6/TDO); also elsewhere on the board
JTAG_TDO: U1.56 (PF5_ADC5/TMS); also elsewhere on the board
JTAG_TMS: U1.54 (PF7_ADC7/TDI); also elsewhere on the board
MCU_FLASH_CE: R2.2, U1.14 (PB4_OC0), U2.1 (CE)
MCU_GPIO_0: J2.4, U1.58 (PF3_ADC3)
MCU_GPIO_1: J2.3, U1.59 (PF2_ADC2)
MCU_GPIO_2: J2.2, U1.60 (PF1_ADC1)
MCU_GPIO_3: J2.1, U1.61 (PF0_ADC0)
MCU_LED0: R3.1, U1.15 (PB5_OC1A)
MCU_LED1: R4.1, U1.10 (PB0_SS#)
MCU_LED2: R5.1, U1.4 (PE2_XCK0/AIN0)
MCU_LED3: R6.1, U1.5 (PE3_OC3A/AIN1)
MCU_MISO: U1.13 (PB3_MISO), U2.2 (SO), U3.7 (SDO)
MCU_MOSI: U1.12 (PB2_MOSI), U2.5 (SI), U3.5 (SDI)
MCU_RESET: J1.5 (RST), R7.1, S1.2 (3), U1.20 (_RESET)
MCU_RX0/PDI: J1.4 (MOSI), U1.2 (PE0_RXD0/PDI); also elsewhere on the board
MCU_SCK: J1.3 (SCK), U1.11 (PB1_SCK), U2.6 (SCK), U3.6 (SCK)
MCU_TX0/PDO: J1.1 (MISO), U1.3 (PE1_TXD0/PDO); also elsewhere on the board
MCU_VCC: R1.1, R2.1, R7.2, U1.21 (VCC), U1.52 (VCC), U1.62 (AVREF), U1.64 (AVCC), U2.3 (WP), U2.7 (HOLD), U2.8 (VDD); also elsewhere on the board
unnamed: LED3.1, R6.2
unnamed: LED2.1, R5.2
unnamed: LED1.1, R4.2
unnamed: LED0.1, R3.2
RD: U1.34 (PG1_RD#); also elsewhere on the board
SELECTMAP_D0/FPGA_MISO1: U1.32 (PD7_T2); also elsewhere on the board
SELECTMAP_D1/FPGA_MISO2: U1.31 (PD6_T1); also elsewhere on the board
SELECTMAP_D2/FPGA_MISO3: U1.30 (PD5_XCK1); also elsewhere on the board
SELECTMAP_D3: U1.29 (PD4_ICP1); also elsewhere on the board
SELECTMAP_D4/MCU_TX1: U1.28 (PD3_TXD1/INT3); also elsewhere on the board
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

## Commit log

2017-05-01 initial design partly sch
    [elasticNode.brd, elasticNode.sch]
2017-05-02 working on elastic node
    [elasticNode.brd, elasticNode.sch]
2017-05-02 small edits
    [elasticNode.brd, elasticNode.sch]
2017-05-07 home working on elastic node
    [elasticNode.brd, elasticNode.sch]
2017-05-09 small routing at home
    [elasticNode.brd, elasticNode.sch]
2017-05-10 lots of routing, and reorganising
    [elasticNode.brd, elasticNode.sch]
2017-05-10 small home edits
    [elasticNode.brd]
2017-05-16 lots of routing, removed latch
    [elasticNode.brd, elasticNode.sch]
2017-05-17 added another measurement
    [elasticNode.brd, elasticNode.sch]
2017-05-17 changed to single power plane
    [elasticNode.brd, elasticNode.sch]
2017-05-18 finished first round rerouting
    [elasticNode.brd, elasticNode.sch]
2017-05-22 small edits before unified
    [elasticNode.brd, elasticNode.sch]
2017-07-28 last before fixes to v2
    [elasticNode.brd, elasticNode.sch]
2017-08-04 changed i2c to pullup
    [elasticNode.brd, elasticNode.sch]
2017-08-04 updated board for previous pullups and swapped fpga power rails
    [elasticNode.brd, elasticNode.sch]
2017-08-04 added smd usb connector
    [elasticNode.brd, elasticNode.sch]
2017-08-05 updated footprints, moved reset buttons, general reorganising
    [elasticNode.brd, elasticNode.sch]
2017-10-21 first part toward separate monitoring board
    [elasticNode.brd, elasticNode.sch]
2017-10-23 backup of v2
    [elasticNode.brd, elasticNode.sch]
2017-10-31 first part of new layout
    [elasticNode.brd, elasticNode.sch]
2017-11-01 New layout is done
    [elasticNode.brd, elasticNode.sch]
2017-11-02 elasticnode mostly finished with smaller footprint
    [elasticNode.brd]
2017-11-03 4-switch dip added into design
    [elasticNode.brd, elasticNode.sch]
2017-11-06 also monitoring PAC1720 current
    [elasticNode.brd, elasticNode.sch]
2017-11-21 small changes for mosfet power
    [elasticNode.brd, elasticNode.sch]
2017-12-06 added fpga_power control line, some text and minor changes to layout
    [DRILEGEND.CFG, elasticNode.brd, elasticNode.sch]
2019-01-03 partial v3
    [elasticNode.brd, elasticNode.sch]
2019-03-08 Remove old MCU
    working on the mother board interface.
    [elasticNode.brd, elasticNode.sch]
2019-03-11 backup before review
    [elasticNode.brd, elasticNode.sch]
2019-03-13 back up before review.
    [elasticNode.brd, elasticNode.sch]
2019-03-13 Layout work start.
    [elasticNode.brd, elasticNode.sch]
2019-03-16 backup
    SRAM and FPGA finished, now connecting fpga and MCU
    [elasticNode.brd, elasticNode.sch]
2019-03-17 back up
    spi_sck didn’t connect to FPGA,OK？
    [elasticNode.brd, elasticNode.sch]
2019-03-17 backup
    SPI FLASH ok.
    [elasticNode.brd, elasticNode.sch]
2019-03-19 backup
    FPGA_GPIO connecting
    [elasticNode.brd, elasticNode.sch]
2019-03-21 back up
    power line need check again.
    [elasticNode.brd, elasticNode.sch]
2019-03-22 only daughter board interface left
    [elasticNode.brd, elasticNode.sch]
2019-03-24 finish the work.
    [elasticNode.brd, elasticNode.sch]
2019-03-25 Fix DRC errors.
    [elasticNode.brd]
2019-03-25 Fixed all DRC Errors and Warnings.
    [elasticNode.brd, elasticNode.sch]
2019-03-25 move back the logo
    [elasticNode.brd]
2019-03-26 add the direction for the mother board interface.
    [elasticNode.brd, elasticNode.sch]
2019-03-26 backup before renumber the elements.
    [elasticNode.brd, elasticNode.sch]
2019-03-26 Add JTAG Header
    Checked the schematic diagram again.
    [elasticNode.brd, elasticNode.sch]
2019-03-26 renumber all elements.
    [elasticNode.brd, elasticNode.sch]
2019-03-26 Add a new version, v4.
    [elasticNode.brd, elasticNode.sch]
2019-03-26 Change the capacitors’ name positions.
    [elasticNode.brd]
2019-03-26 ready for ordering.
    [elasticNode.brd]
2019-03-26 fix mistake about the capacitor of 4.7uF
    [elasticNode.brd, elasticNode.sch]
2019-03-28 Change the 100M clock signals connection
    Add enable signal to oscillator 100M, and check aux IOs Voltage.
    [elasticNode.brd, elasticNode.sch]
2019-03-29 changed the position of the little notch
    [elasticNode.brd]
2019-04-25 Modified the footprint of the FPGA and MCU.
    Rechecked the board again.
    [elasticNode.brd, elasticNode.sch]
2019-06-30 Optimized the distance between the elements.
    [elasticNode.brd, elasticNode.sch]
2019-07-03 Fixed some errors check.
    [elasticNode.brd]
2019-11-17 add the v4 with dual port ram.
    [elasticNode.brd, elasticNode.sch]
2023-01-30 add env5 stuff
    [DRILEGEND.CFG, elasticNode.brd, elasticNode.sch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]
2023-01-30 fix extension board schematic link
2023-07-03 version stared
    [en_v5.brd, en_v5.sch, extension_board.brd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]
2023-07-17 change vias position
    [en_v5_rev2.brd, en_v5_rev2.sch]
2023-08-30 point ordered PCBA from JLCPCB
    [extension_board_top_bom.csv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]
2023-08-30 point ordered PCBA from JLCPCB for the mainboard
    [en_v5_rev2_bom.csv, en_v5_rev2_bottom_bom.csv, en_v5_rev2_top_bom.csv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]
2023-10-24 optimize design half done
    [en_v5_rev2.brd, en_v5_rev2.sch]
2023-10-24 changed a resistor value
    [en_v5_rev2.brd, en_v5_rev2.sch]
2023-10-27 fixed the voltage regulator
    [en_v5_rev2.brd, en_v5_rev2.sch]
2023-10-27 changed the direction of battery connector
    [en_v5_rev2.brd, en_v5_rev2.sch]
2023-10-27 prepared CAM files
    [PnP_en_v5_rev2_back.csv, PnP_en_v5_rev2_front.csv, PnP_extension_board_front.csv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]
